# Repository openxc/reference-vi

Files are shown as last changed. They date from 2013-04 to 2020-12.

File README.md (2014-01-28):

OpenXC Vehicle Interface Reference Design
=========================================

This repository is a part of the [OpenXC][] project.

This repository contains the documentation and open source design files for the
OpenXC vehicle interface reference design, originally created by Ford.

## Documentation

The documentation is in the form of simple website, written in Markdown with the
HTML generated with [Jekyll][jekyll].

[jekyll]: http://jekyllrb.com/

### Organization

* the `*.mkd` files are the source for the documentation website - they're very
  readable as plain text files, too, if you're just digging through the
  repository.
* `static/` contains the static JavaScript, CSS and images for the site.
* `_layouts/default.html` contains the main layout for the site. There's only 1
  layout for now, although there could others in the future.
* `electrical/` contains the electrical design files and documentation.
* `mechanical/` contains the mechanical housing design files and documentation.
* `assembly/` contains documentation to support final assembly at a fabrication
  house.

### Local development

If you do not have ruby and RubyGems installed (you already do on OS X), see
below.

Assuming you have Ruby and RubyGems installed:

    $ gem install rdiscount jekyll

Then, assuming you have Python's `pip` installed:

    $ pip install pygments

Then run the local development server:

    $ cd reference-vi
    reference-vi/ $ jekyll serve -w

and point your browser to http://localhost:4000.

Jekyll uses the templates in the repository to generate a static html version of
the site. The static version is always dumped in the `_site` subdirectory in the
repository - this is *not* committed, since it's automatically generated. The
`-w` flag turns on auto-recompilation, so anytime you change a file it will
regenerate whatever files have changed, so you just need to refresh the browser
to see your latest updates.

### Installing Ruby and RubyGems

**Cygwin in Windows**

TODO is this necessary anymore?

Install the `ruby`, `make`, `gcc`, `libiconv` and `zlib` packages in
Cygwin using the `setup.exe`
you downloaded earlier. Download the RubyGems TGZ package from
http://rubygems.org/pages/download and put it in `C:\cygwin\home\<your
username>`. Fire up Cygwin and run this:

    $ tar -xzf rubygems*.tgz
    $ cd rubygems*
    $ ruby setup.rb

Jekyll depends on posix-spawn v0.3.6, but that has a problem with compiling in
Cygwin. The latest development version works, though, so install that gem from
source before continuing:

    $ git clone https://github.com/rtomayko/posix-spawn.git
    $ cd posix-spawn
    $ gem build posix-spawn.gemspec
    $ gem install posix-spawn-0.3.6.gem

If you didn't get any errors, return to the top of this section and install
jekyll.

### Going Live

The documentation site is hosted on GitHub pages, so deploying is as simple as
commiting your changes to the `gh-pages` branch and pushing to GitHub. It gets
regenerated within a minute or two, and then it's live. This of course means
don't push anything in the `gh-pages` branch that isn't 100% done!

## License

Copyright (c) 2013 Ford Motor Company

The electrical and mechanical designs in this repository are available under the
[Creative Commons Attribution 4.0
International](http://creativecommons.org/licenses/by/4.0/deed.en_US) license.

[OpenXC]: http://openxcplatform.com

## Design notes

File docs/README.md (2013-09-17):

OpenXC Vehicle Interface
========================

[TOC]

Details
-------

### Block diagram

Interface Block Diagram

The Vehicle Interface (VI) is built around an LPC1769 ARM Cortex M3 MCU by NXP,
running at 100MHz.  The interface reads vehicle data via two CAN buses.  By
default the device reads from the Diagnostic High speed and Diagnostic Medium
speed buses (Channel B can also read from the Multimedia CAN bus).  The CAN
buses are converted into serial data by a [TJA1048
IC](http://www.nxp.com/documents/data_sheet/TJA1048.pdf).  The translated data
is sent to a tablet or PC via USB and Bluetooth.  USB is achieved by the device
controller built into the LPC1769.  Bluetooth is achieved via a [Roving Networks
RN-41 Embedded bluetooth module](http://www.rovingnetworks.com/products/RN41),
using UART channel 1 on the LPC1769 with hardware flow control.

The Dock has two power regulators.  The main regulator is a low dropout linear
regulator regulator that steps the +12V automotive power down to a steady +5V.
A smaller 3.3V low dropout regulator (LDO) provides the USB Hub with a 3.3V
rail.  The power section is configured so that a USB OTG host can either provide
or consume +5V power.  If the Dock is plugged into a PC or laptop, the +5V power
can be used to power the Dock and downstream devices.  If a mobile phone or
tablet is plugged into the Dock, and is configured to charge from the USB OTG
port, it will be able to charge from the +5V power.  This is protected by a 1A
PTC resettable fuse - if a power fault occurs, the fuse will trip and power will
need to be removed for several minutes until the fuse is reset.

Several other headers and jumpers have been exposed for development purposes.  A
header has been provided to access UART0 on the LPC1769 - this can be used for
serial debug as well as ISP programming.  The standard JTAG interface has also
been exposed through a 10-pin ARM JTAG Mini connector.  Two buttons have also
been added to the board - one resets the LPC1769, and the other allows the
LPC1769 to enter a USB bootloader if available.  See
[Inputs/Outputs](#inputsoutputs) for more information.

### Parts Layout

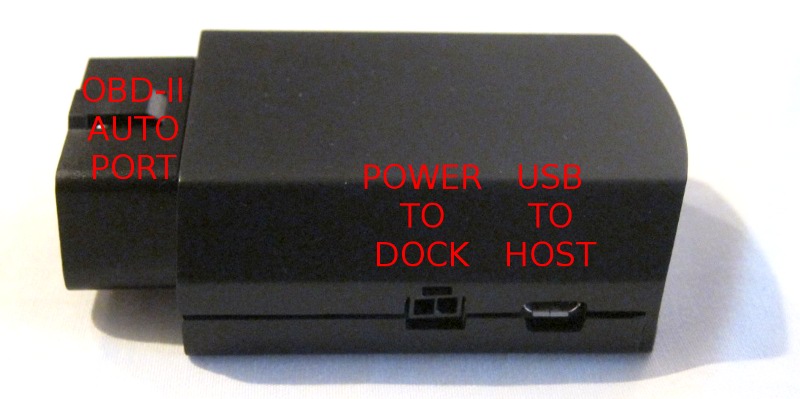
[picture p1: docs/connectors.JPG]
Interface Connections Interface board - Connections


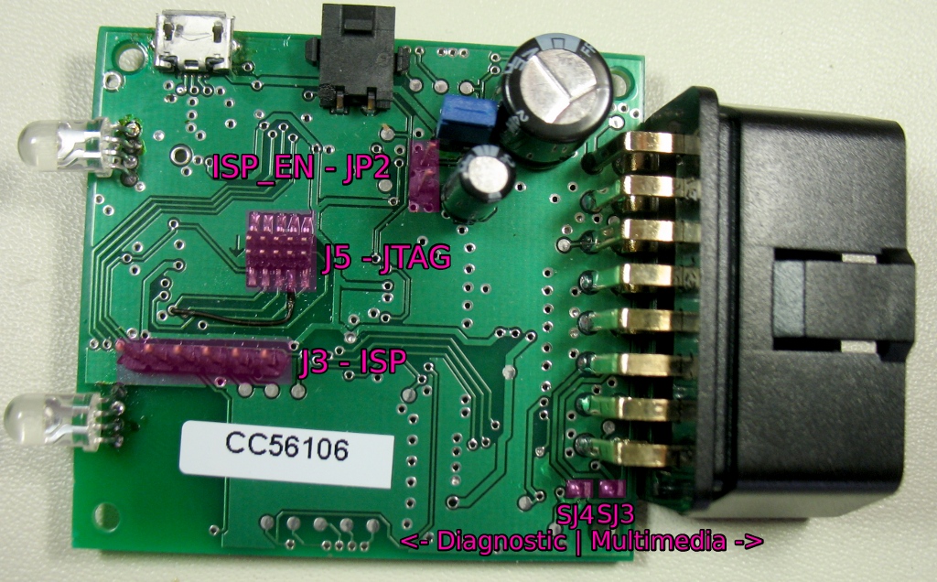
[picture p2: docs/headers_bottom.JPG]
Interface Headers Bottom Interface board - headers on bottom side


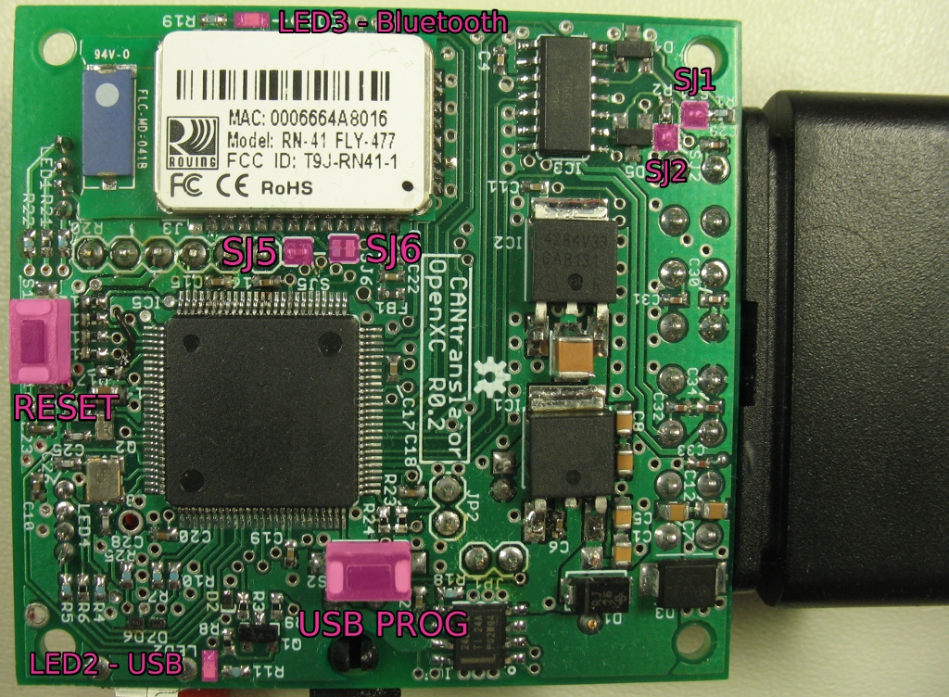
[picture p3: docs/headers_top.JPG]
Interface Headers Top Interface board - headers on top side


### Inputs/Outputs

#### Buttons

* S1 (RESET) - Pressing this button will reset the LPC1769 (it will not reset
  the RN-41 chipset)
* S2 (PROG) - This button engages a USB Bootloader. Hold down S2 while pressing
  S1 to enter the bootloader.

#### Headers and jumpers

* JP1 (HOST PWR) - Shorting this jumper will allow the board to either charge an
  upstream USB device, or be powered by it.
* JP2 (ISP_EN) - Shorting this jumper will place the LPC1769 in ISP Bootloader
  mode when it is reset. In ISP Bootloader mode, user code is not run - J3 can
  only be used to deploy firmware over serial.
* J3 (ISP) - The debug serial port (UART0) which can also be used for ISP
  programming (see JP2).
* J5 (JTAG) - This is a 50 mil pitch 10-pin ARM Mini JTAG interface. An adapter
  can be used to connect the standard 100 mil 20-pin JTAG connector.

#### Solder Jumpers

* SJ1, SJ2 - These are used to engage the 120 ohm termination resistor for CAN
  interfaces A and B respectively. If being used in a test bench without a full
  CAN network, you probably want these enabled. It may be simpler and more
  reversible to add the resistors to the OBD-II cable, instead.
* SJ3, SJ4 - These switch the CAN B channel between the Diagnostic Medium Speed
  and Multimedia CAN buses exposed by the OBD-II connector on Ford vehicles.
  They are each shorted towards the PCB edge, enabling the Diagnostic interface
  by default.
* SJ5  - This connects the DTR line of the ISP header (J3) to the LPC1769 RESET
  line. This can be used by an ISP programmer to automatically reset the LPC1769
  for programming.  In practice, this can accidentally hold the LPC1769 in
  reset, so this jumper should be OPENED if J3 is used.
* SJ6  - This disconnects the RN-41 reset pin from the BT_RST GPIO pin on the
  LPC1769. This is normally closed, and should only be opened if the RN-41 needs
  to be put into reset without the LPC1769.

### GPIO Pin List

A list of GPIO pins used on the LPC1769

#### Port 0

* P0.2 - ISP/Debug UART: TX
* P0.3 - ISP/Debug UART: RX
* P0.4 - CAN Channel B: RX
* P0.5 - CAN Channel B: TX
* P0.6 - CAN Channel B: Enable (HIGH = Normal Mode, LOW = Standby Mode)
* P0.15 - Bluetooth UART: RX
* P0.16 - Bluetooth UART: TX
* P0.17 - Bluetooth Enable: (HIGH = RN-41 is enabled, LOW = RN-41 is in RESET)
* P0.18 - Bluetooth Connection: INPUT - Will go high when bluetooth host is
  connected
* P0.19 - CAN Channel A: Enable (HIGH = Normal Mode, LOW = Standby Mode)
* P0.21 - CAN Channel A: RX
* P0.22 - CAN Channel A: TX
* P0.29 - USB D+
* P0.30 - USB D-

#### Port 1

* P1.18 - LED4 (Right LED) Green Channel
* P1.20 - LED4 (Right LED) Blue Channel
* P1.21 - LED4 (Right LED) Red Channel
* P1.23 - LED1 (Left LED) Green Channel
* P1.24 - LED1 (Left LED) Blue Channel
* P1.26 - LED1 (Left LED) Red Channel
* P1.30 - USB VBUS: Connected to USB +5V pin

#### Port 2

* P2.2 - Bluetooth UART: RTS (LOW when RN-41 is ready for data, HIGH when RN-41
  serial buffer is full)
* P2.7 - Bluetooth UART: CTS (LOW when LPC1769 is ready for data, HIGH when
  LPC1769 serial buffer is full)
* P2.9 - USB CONNECT: Enables USB Pullup (LOW when USB unused, HIGH to signal
  USB interface is ready)
* P2.10 - ISP ENABLE: When HIGH, User code runs on next RESET. When LOW, ISP
  Serial bootloader runs on next RESET.
* P2.12 - USB Bootloader ENABLE: When HIGH, User code runs on next RESET. When
  LOW, USB bootloader runs on next RESET
* P2.13 - Power output enable (Active Low): Output power port enabled when LOW

Usage:
------

### How to program

The most reliable way to program the VI is via the JTAG
interface, however other options are available:

#### JTAG

To program using JTAG, any ARM Cortex M3 compatible JTAG adapter can be used.
The interface has been tested using an
[ARM-USB-TINY-H](https://www.olimex.com/Products/ARM/JTAG/ARM-USB-TINY-H/) and
an [ARM-USB-OCD-H](https://www.olimex.com/Products/ARM/JTAG/ARM-USB-OCD-H/) by
Olimex.  The interface board does not have a full-size 20-pin JTAG connector -
[an adapter will be required with most JTAG
programmers](https://www.olimex.com/Products/ARM/JTAG/ARM-JTAG-20-10/).  Simply
plug the ARM-JTAG-MINI connector into J5 on the bottom side of the vehicle
interface PCB.  Make sure that the ribbon cable exits the connector in the
direction of the arrow on the PCB.

With the JTAG adapter connected, and power applied to the board, the LPC1769
should respond to commands from [OpenOCD](http://openocd.sourceforge.net/).  If
deploying code from an OpenXC repository, the board can be programmed by simply
executing "make flash" from the root of the source tree.  See other LPC17XX JTAG
tutorials for more information, the process is nearly identical across all
LPC17XX devices.

#### ISP

If a [3.3V USB-Serial converter is
available](https://www.sparkfun.com/products/9873), the device can be programmed
using the ISP header, J3.  To use ISP simply short JP2 and reset the LPC1769.
If the ISP_EN pin is grounded when the LPC1769 boots, it will enter the built-in
ISP bootloader instead of running the OpenXC firmware.  UART0 will then be used
for programming under an application like [Flash
Magic](http://www.flashmagictool.com/).  Page 616 of the LPC17XX user manual
outlines how to use ISP mode.

#### USB Bootloader

The LPC1769 has the capability to load code from the USB interface, however this
is not built into the MCU.  In order to program over USB, a USB bootloader must
already have been programmed onto the LPC1769.  The USB Bootloader should watch
pin P2.12 (the same pin as the LPC1768 BlueBoard) on startup.  If installed
correctly, the bootloader can be actived by holding down S2 while resetting the
VI.

#### RN-41 Configuration

After being manufactured, the only additional configuration step (outside of
deploying firmware) is to change a few default values on the RN-41 device.  The
default RN-41 baud rate is 115200 baud, which is not high enough to saturate the
bluetooth link.  The quickest way to preform this first initial configuration is
to use a PC or tablet with a bluetooth interface:

1. Apply power to the VI.
1. Discover Bluetooth devices on the PC, find the VI, and pair
      with it.
1. Remove power from the VI.
1. After a few moments, reapply power to the VI
1. Very quickly (within 60 seconds) connect to the VI and open a
    terminal
1. type "$$$" and press enter.  If done quickly, the bluetooth LED should
      start flashing rapidly and "CMD" should be printed to the screen.
1. type "ST,10" to reduce the configuration timer to 10 seconds.  It can also
      be disabled by executing "ST,0".
1. type "SU,43" to set the baud rate to 460800.  This value is used by the test
    firmware.
1. type "---" to exit configuration mode
1. Remove power from the VI.  When power is reapplied, the
   settings will be changed.

The commands can also be sent via UART0 on the LPC1769 to avoid the
configuration timer.  See [the RN-41 advanced user
manual](http://www.rovingnetworks.com/resources/download/47/Advanced_User_Manual)
for additional documentation on parameters that can be changed (Page 30 for a
quick reference)

### Known issues:

For greater detail, see CHANGELOG.xls

#### v0.3:

* The very first run of prototypes are lacking epoxy on the USB Micro connector
  and the connector may break under stress.  This will be fixed in subsequent
  manufacturing runs.

#### v0.2:

* Output Power Jack Polarity is incorrect - The output power jack should be
  configured such that Pin 1 (the keyed pin) is Ground, and Pin 2 is +12V. This
  is flipped on the R0.2 PCB. A custom cable was created to patch this issue,
  and is labeled `R0.2 Only`. Only use this cable with R0.2 prototypes,
  otherwise the KBoard TVS Diode D2 and/or the VI power switch IC7
  may be damaged or destroyed.
* JTAG CLK line - the JTAG signal RTCK was disconnected on R0.2 boards. It has
  manually been replaced with a wire. Occasionally the additional capacitance of
  this wire can cause JTAG errors - try reducing the JTAG clock rate.
* JTAG Ground noise - Occasionally JTAG errors can be caused by a ground loop
  between a USB JTAG adapter and the MicroUSB port on the VI. Try
  removing one or more connections to ground: IE, try powering the prototype
  from ONLY +5V USB verses the +12V OBD-II supply.
* Bluetooth connection dropout - Under some circumstances, the RN-41 bluetooth
  chipset will lock up and drop an active bluetooth connetion when under heavy
  load:
    * The most common cause of this problem is software flow control: make sure
      to use the RTS and CTS pins for UART1.
    * The RN-41 configuration timer can also cause the RN-41 input buffer to
      fill. From the LPC1769, enter configuration mode by transmitting
      ```$$$```, disable the configuration timer with ```ST,0\r\n``` and then
      exit configuration mode by entering ```---\r\n```. Finally, power cycle
      the VI. The test firmware `rn42-passthrough` enables serial
      data to be relayed between UART0 (the 6-pin ISP header) and UART1 (the
      bluetooth interface).

Design Details and Consideration
--------------------------------

### MCU Selection

The VI was originally built around a ChipKit MAX32 development
board, which used a PIC32MX795F512 processor.  We chose to move away from this
architecture due to frustrations around the open-source support and tools of the
PIC32 line.  We had trouble developing for this platform in Linux, and had to
resort to closed-source windows tools in order to use the device effectively.
Most other MCUs in the same performance category as the PIC32 device lie in the
[ARM-Cortex-M family](http://en.wikipedia.org/wiki/ARM_Cortex-M), particularly
the ARM Cortex-M3 core.  Several major MCU manufacturers make Cortex-M3 devices
(Atmel, NXP, STMicro, TI),  The NXP LPC17XX line was selected due to it's
excellent open-source compiler support, library support, and ease of
programming.  Many off-the-shelf open-source hardware designs exist for the
LPC1768, and this encourages a large amount of community support and a wider
variety of user-contributed libraries.

The MCU system design was based around the [Blueboard
LPC1768-H](http://shop.ngxtechnologies.com/product_info.php?products_id=65).
This was done to allow firmware to be prototyped on an off-the-shelf open-source
hardware.  The hardware configuration is also compatible with the [MBED rapid
prototyping board/environment](http://mbed.org/).  The Clock, Power and USB
subsystems are all equivalent.  The JTAG interface was converted to the 10-pin
ARM JTAG Mini format to reduce the PCB footprint of the normal large 20-pin JTAG
connector.  This results in a 12MHz external crystal oscillator stepped up to a
100MHz system clock.

### LPC1769 Data

* [LPC1769FB100 Product Page](http://www.nxp.com/products/microcontrollers/cortex_m3/LPC1769FBD100.html)
* [LPC176X Datasheet](http://www.nxp.com/documents/data_sheet/LPC1769_68_67_66_65_64_63.pdf)
* [LPC17XX User Manual](http://www.nxp.com/documents/user_manual/UM10360.pdf)
* [Blueboard LPC1768-H Product Page](http://shop.ngxtechnologies.com/product_info.php?products_id=65)
* [Blueboard LPC1768-H Schematics V2](http://shop.ngxtechnologies.com/download/Schematics/BlueBoard/BB_LPC1768_H/Blueboard_lpc1768_H_V2.pdf)
* [mbed LPC1768 schematics](http://mbed.org/media/uploads/chris/mbed-005.1.pdf)

### Power Section

The VI uses two heavy-duty low dropout linear regulators to
convert the unpredictable +12V automotive power source to the +5V and +3.3V
rails needed by the MCU and related ICs.  Incoming power is protected from
overvoltage by D3, a [SMBJ16CA](http://www.fairchildsemi.com/ds/SM/SMBJ16CA.pdf)
Transient Voltage Suppressor (TVS) diode.  D3 will protect the interface from
any voltage over 19.7V (Vbr).  The power regulators can handle up to 40V, but
the Dock power switch (IC7) can only tolerate up to 20V.  Reverse voltage is
protected by D1.  Both regulators do not require any additional current or
temperature protection - they can safely drive into a short circuit at
temperatures up to 150 degrees C, and will limit current if they become too hot.
Plenty of bulk and bypass capacitance has been provided to absorb automotive
power transients.

The regulators are cascaded such that the +5V rail supplies the +3.3V rail.  The
TLE4284DV33 has a maximum voltage drop of 1.4V, so it can be safely powered by
any source above 4.7V.  While this puts additional load on the +5V rail, it also
allows the interface to be powered either by the OBD-II connector or the
MicroUSB port.  Both regulators can deliver current up to 1.6A.  Current budget:

* 5V regulator capacity: 1600mA
* USB Charging Limit (fuse): 1000mA
* RN-41 average TX rate: 60mA
* LPC1769 Base consumption @ 100MHz: 50mA
* LPC1769 peripherals (2xCAN+2xUART): 3mA
* Both RGB LEDs on at full: 60mA
* TJA1048T both channels dominant: 140mA
* Total: 1313mA

This yields a headroom of ~300mA when all peripherals are active and a Tablet is
charging at 1A.

### Power Input/Output

The VI has the following power connections:

* OBD-II Automotive Power: Input @ 12V
* Dock Power Connector: Output @ 5V up to 6A
* USB Micro Connector: Input OR Output @5V up to 1A

The Dock power connector is controlled by a [TPS2421-2 power switch with
internal MOSFET](http://www.ti.com/lit/ds/symlink/tps2421-2.pdf).  This allows
the Dock power to be disabled when the vehicle is turned off, as well as
providing current protection.  The power switch has an active 6A limit, and will
actively attempt to re-engage power when the limit is tripped ("retry on
fault").

The USB Micro Connector is directly connected to the +5V bus through a Fuse.
The lack of a diode means that the connected USB device can either consume or
supply current.  If a PC is connected to the USB Micro connector, it will power
the 3.3V regulator and the +5V regulator will be bypassed.  If an android tablet
is connected that supports USB OTG Charging, it will be allowed to consume +5V
power.  A resettable fuse (F1) has been added to protect the VI
from a bad USB cable or USB Host.  The fuse is a [Bourns
MF-MSMF110/16-2](http://www.bourns.com/pdfs/mfmsmf.pdf).  The fuse will
automatically reset when power is removed and the fuse is allowed to cool off.
This has an added downside of temperature dependence - the fuse can only pass
the full 1A of current up to 40 degrees C.  Above that temperature the limit
slowly decreases - see the datasheet for a thermal derating chart.

### CAN Interface

The CAN interface is acheived using an [NXP
TJA1048](http://www.nxp.com/documents/data_sheet/TJA1048.pdf), a dual-channel
CAN transceiver.  This is a part recommended by Ford engineers for it's
reliablity and robustness.  The only hard requirement of this transceiver is
that it have a Standby mode, and some way to wake up the microcontroller when
the CAN bus comes out of standby.  Aside from the CAN signals, the TJA1048 also
has one standby input per channel - pulling each line low will put it's
respective CAN channel into standby mode.  These are routed to P0.19 for CAN
Channel 1, and P0.6 for CAN Channel 2.

On the automotive side of the CAN transceivers, some support electronics are
required.  D4 and D5 provide additional ESD protection against voltage spikes on
the CAN line - each
[PESD1CAN](http://www.nxp.com/documents/data_sheet/PESD1CAN.pdf) can provide up
to 200W of peak dissipation and ESD protection up to 23kV.  R1 and R2 provide
termination resistance for the CAN Bus.  If the VI is acting as a
CAN Slave, and is reading CAN signals from a vehicle, these resistors need to be
connected across the HI and LO wires of each CAN bus.  SJ1 and SJ2 are closed by
default, enabling this termination.  If this termination is not needed, the
solder jumpers can be cut.  Finally, each CAN signal as a 100pF bypass capacitor
very close to the OBD connector, to shunt high frequency noise to ground.

The CAN bus doesn't particularly require a high speed PCB design, since the rate
is only 1Mbps at most.  However an attempt was made to maintain the
characteristic 120 ohm differential impedance on the CAN lines.  An attempt was
also made to maintain a 45 mil guard band around each CAN bus, to keep high
frequency switching transients from coupling onto the CAN bus.  The guard band
was also applied to the LPC1769 side of the CAN transciever, to keep the same
transients out of the converted CAN signals.  Since the layout is only 2 layers
and very crowded, this wasn't implemented perfectly, but seems to be within 85%
coverage.  The combination of these considerations means that the CAN interface
should be highly resilient to noise and should limit signal distortion due to
reflections and other transmission line phenomenon.

### Bluetooth Interface

The [Roving Networks RN-41](http://www.rovingnetworks.com/products/RN41) was
chosen to implement the Bluetooth interface for the VI:

* a low-cost and easy-to-use option
* easily prototyped
* automatically implents the Serial Port Profile (SPP) configuration
* no need to implement a Host/Controller Interface (HCI), keeps MCU code simple

The only major design impact of the RN-41 is that it requires a large "keepout"
area near the antenna of the module.  In this area, there should be a minimal
amount of traces or copper blocking the radio signal.  The [RN-41
Datasheet](http://www.rovingnetworks.com/resources/download/18/RN_41)
illustrates the suggested keepout zone on page 9.  Otherwise, the RN-41 is
controlled with a serial UART bus with similar bitrates to the CAN data (230kbps
- 1Mbps).  In our testing we discovered that hardware flow control is necessary
to fully saturate the bluetooth link.  The firmware on the RN-41 does not
respond well to buffer overruns - if data is written to the RN-41 faster than it
can be sent over the bluetooth link, the module will eventually overflow and
reset without warning.  Adding the RTS and CTS lines to UART1 on the LPC1769
fixed this problem - the RN-41 will inform the MCU host when it's buffer is
full.

The tradeoff of a simplified Bluetooth module is that the implementation details
of the SPP profile limit the throughput of the bluetooth link.  While the
underlying Enhanced Data Rate (EDR) bluetooth link can technically operate at
3Mbps, the asynchronous nature of SPP limits the RN-41 to 240kbps in slave mode.
In our testing, the RN-41 only hit this speed for brief peak bursts.  The
sustained average speed was 202kbps.  Future designs may consider using a more
complicated bluetooth chipset with an HCI interface implemented on the MCU for
greater throughput.  An example of a test run:

<img src="./Testing%20Results/BT_Endurance_Histogram_012613.svg" alt="RN-41 Test Throughput" width="1024">
<!--![RN-41 Test Throughput](./Testing%20Results/BT_Endurance_Histogram_012613.svg "RN-41 Test Throughput")-->

* Average rate: 25.282 KB/s
* Maximum speed: 30.185 KB/s
* Minimum speed: 14.718 KB/s

### USB Interface

USB is provided directly by the LPC1769 - no external transceiver or controller
is necessary.  A few external components are required to correctly enable the
LPC1769 as a USB Device and can be found on [Page 276 of the LPC1769
manual](http://www.rovingnetworks.com/resources/download/47/Advanced_User_Manual).
The USB_CONNECT line and associated circuitry was mirrored from the LPC1768-H
Blueboard design so that USB bootloader firmware would be interoperable, and a
few modifications were made for additional resilience and device compatibility:

Diodes D2, D6 and D7 were added to ESD protect the USB lines.  D2 is an [NXP
PESD12VS1ULD](http://www.nxp.com/documents/data_sheet/PESD12VS1ULD.pdf)
unidirectional ESD protection diode.  D6 and D7 are [NXP
PESD5V0X1BL](http://www.nxp.com/documents/data_sheet/PESD5V0X1BL.pdf)
bidirectional ESD diodes.  All protection diodes are specifically designed for
the USB bus and have very low capacitance to avoid disrupting USB signals.

Resistor R25 attempts to indicate to an attached USB OTG device that the CAN
Translator can provide charging current.  A specification exists on [Page 48 of
the USB Battery Charging Specification
R1.2](http://kinetis.pl/sites/default/files/BC1.2_FINAL.pdf) describing an
Accessory Charger Adapter.  This specification defines special resistance values
on pin 4 of a USB OTG connector that should flag that the connected device is a
charging device.  However in practice very few devices actually honor this
specification.  It's totally up to the implementation of the portable tablet or
smartphone whether or not they support charging while using the USB port as a
USB Host.

If a Male-Male USB Micro cable is used with the VI, this
identification resistor will be readable by a connected USB OTG device.  If the
device is USB ACA compliant, it will successfully charge.  If a Male-Male cable
is unavailable, or if the device doesn't honor the USB ACA specification, a
normal USB A to USB Micro cable can be used with a commonly-available USB OTG
Host mode adapter.  For example:

* A Samsung Galaxy Note II with stock android firmware will honor the USB ACA
  profile [(from this forum post)](http://www.head-fi.org/t/595071/android-phones-and-usb-dacs/405#post_8748466)
* A Motorola Droid Razr with stock firmware and a normal USB OTG Host cable will
  charge (tested)
* A Google Nexus 7 tablet will not charge from the USB OTG port when host mode
  is enabled without a custom firmware (tested)

USB signals require high speed PCB routing to avoid signal integrity issues,
since the bitrates are high (11Mbps - 480Mbps).  Unfortunately with a 2 layer
PCB, the trace widths required to obtain the ideal 90 ohm differential impedance
for a USB line would be unfeasibly wide.  To compensate for this fact, the USB
connector was located extremely close (~300 mils) to the LPC1769 USB pins.  A
guard band was used around the USB lines and tightly coupled to the ground
plane.  The ground plane underneath the USB signals was kept clear so the ground
loop would be kept small and transient ground currents would avoid coupling into
the USB signal.

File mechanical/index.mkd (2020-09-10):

---
layout: default
title: Mechanical Design
---

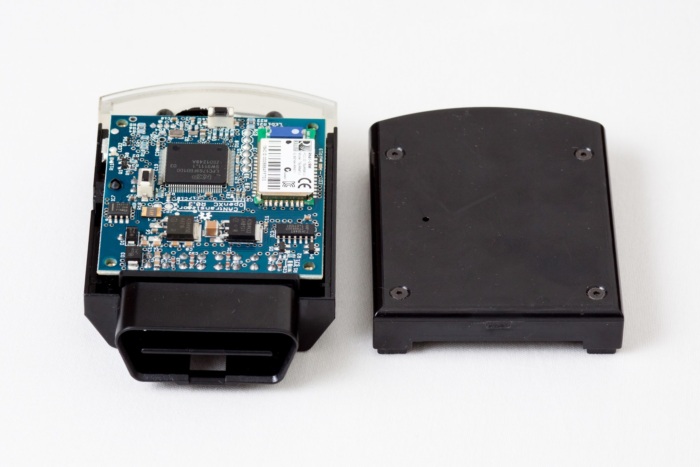
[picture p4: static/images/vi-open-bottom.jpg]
Assembly opened


The VI housing design consists of an opaque top and bottom, with a translucent
diffuser piece at the end opposite the OBD-II connector, between two halves of
the housing. The diffuser does a decent job of spreading the light from the 2
RGB LEDs, although a light pipe may provide more consistent saturation.

We've manufacturing this design succesfully with a MakerBot Replicator 2,
SLA, and most recently, injection molded by contract manufacturers from Silicon Valley, the
materials used were:

* VI Top and Bottom: Bayblend T85 XF-901510
* VI Difffuser: Lexan 3412R-131 (Natural 20% Glass Fiber PC)

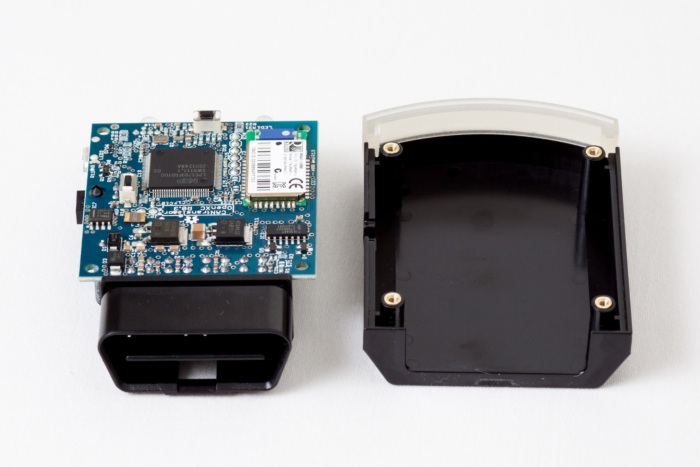
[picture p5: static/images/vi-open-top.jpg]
Assembly opened and separated


## Sources

The original master source files for the 3D design were created in CATIA, which
unfortunately is neither open source nor affordable. We've output the design for
the top of the enclosure, the bottom and the diffuser as STL (triangle) and STP
(solid) files.

The files are all [stored in a Git repository at
GitHub](https://github.com/openxc/reference-vi/tree/gh-pages/mechanical) -
pull requests are welcome!

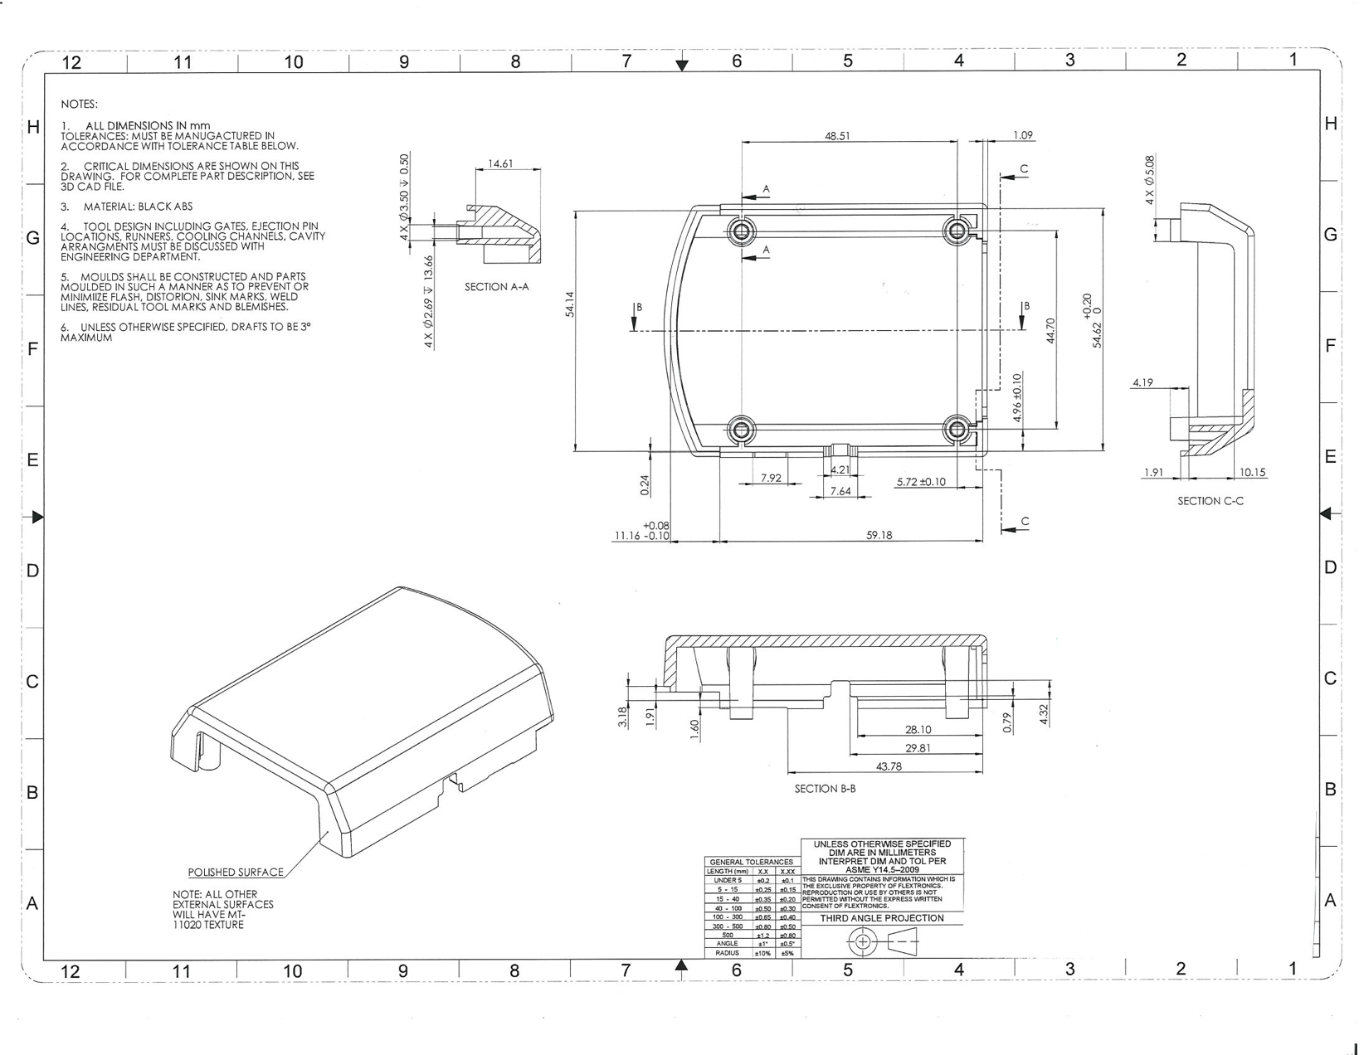
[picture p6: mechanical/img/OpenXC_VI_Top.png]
Top

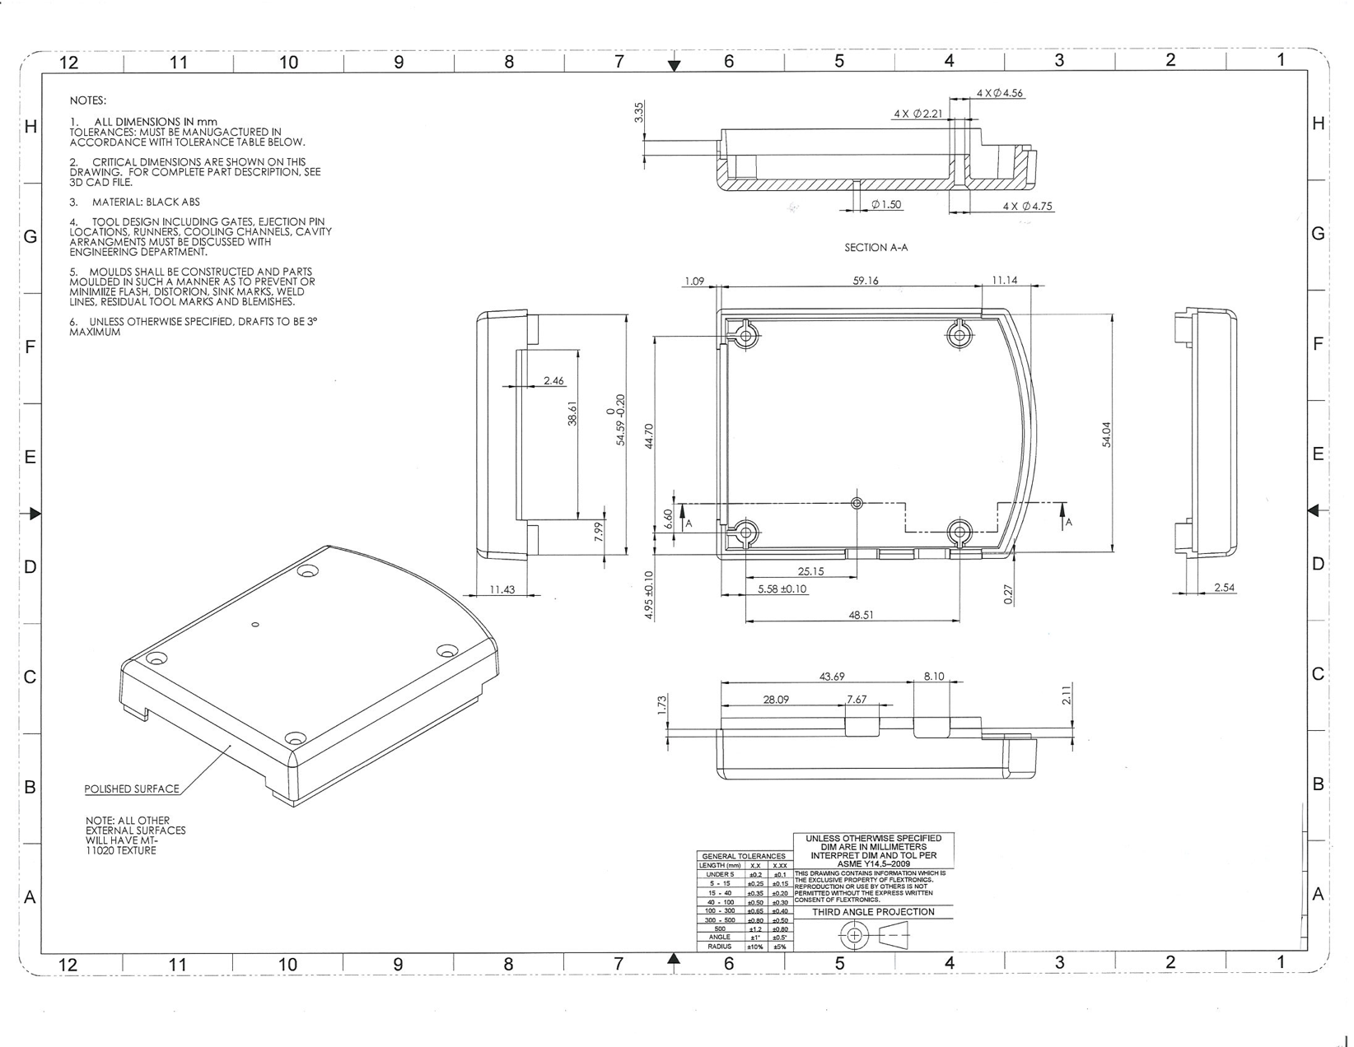
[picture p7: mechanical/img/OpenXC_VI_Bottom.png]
Bottom

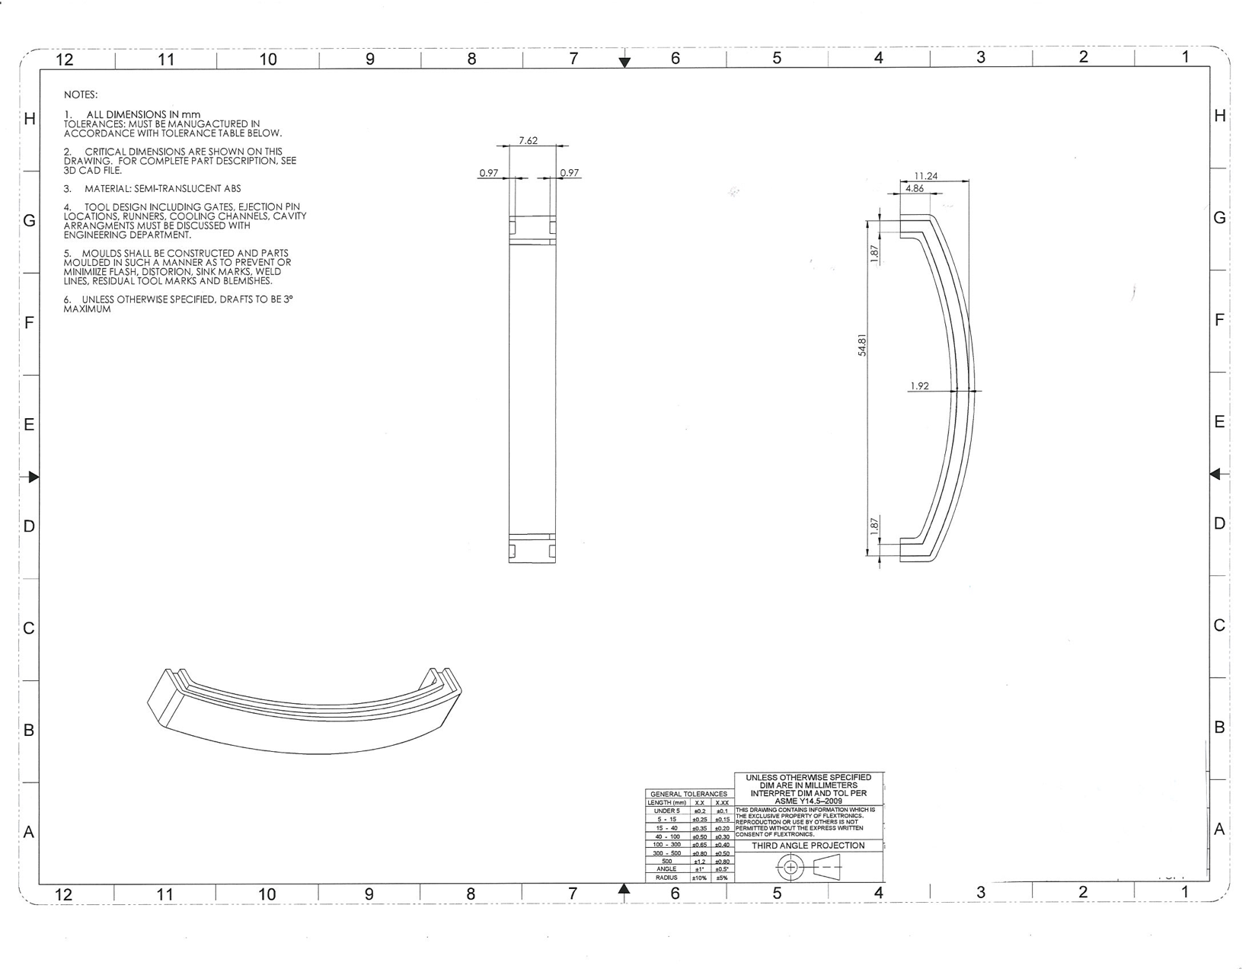
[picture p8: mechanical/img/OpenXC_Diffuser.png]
Diffuser


* VI Enclosure Bottom
  * [2D Drawing(PDF)](/mechanical/OpenXC_VI_Bottom.PDF)
  * [STEP](/mechanical/VI_bottom.step)
* VI Enclosure Top
  * [2D Drawing(PDF)](/mechanical/OpenXC_VI_Top.PDF)
  * [STEP](/mechanical/VI_top.step)
* Diffuser
  * [2D Drawing(PDF)](/mechanical/OpenXC_Diffuser.PDF)
  * [STEP](/mechanical/VI_diffuser.step)

## Design for Manufacturing

* Added 1.5 degree draft angles for top and bottom enclosures. 1.5 degree was chosen based on the selected surface texturing MT-11020. The only exception is the vertical wall where the OBD-II connector sits, which only has 0.5 degree of draft and does not have texturing.
*

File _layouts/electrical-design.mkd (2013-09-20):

---
layout: electrical
---

<ul class="nav nav-tabs subnav">
  <li><a href="/electrical/index.html">Overview</a></li>
  <li><a href="/electrical/design/power.html">Power</a></li>
  <li><a href="/electrical/design/microcontroller.html">Microcontroller</a></li>
  <li><a href="/electrical/design/can.html">CAN</a></li>
  <li><a href="/electrical/design/bluetooth.html">Bluetooth</a></li>
  <li><a href="/electrical/design/usb.html">USB</a></li>
</ul>

{{ content }}

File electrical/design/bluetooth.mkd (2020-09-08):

---
layout: electrical-design
title: Bluetooth Interface
---

The [Roving Networks RN-41](http://www.rovingnetworks.com/products/RN41) was
chosen to implement the Bluetooth interface for the VI because:

* it supports the Serial Port Profile (SPP) configuration
* it doesn't require implementing a Host/Controller Interface (HCI), keeping the
  MCU code simple
  - the stack is on the RN-41

The only major design impact of the RN-41 is that it requires a large "keepout"
area near the antenna of the module. In this area, there should be a minimal
amount of traces or copper blocking the radio signal. The [RN-41
Datasheet](https://cdn.sparkfun.com/datasheets/Wireless/Bluetooth/Bluetooth-RN-41-DS.pdf)
illustrates the suggested keepout zone on page 9. Otherwise, the RN-41 is
controlled with a serial UART bus with similar bitrates to the CAN data (230kbps
- 1Mbps).

In our testing we discovered that hardware flow control is necessary to fully
saturate the bluetooth link. The firmware on the RN-41 [does not respond
well](http://christopherpeplin.com/2013/07/26/uart-hardware-flow-control/) to
buffer overruns - if data is written to the RN-41 faster than it can be sent
over the bluetooth link, the module will eventually overflow and reset without
warning. Adding the RTS and CTS lines to UART1 on the LPC1769 fixed this problem
- the RN-41 will inform the MCU host when it's buffer is full.

The tradeoff of a simplified Bluetooth module is that the implementation details
of the SPP profile limit the throughput of the bluetooth link. While the
underlying Enhanced Data Rate (EDR) bluetooth link can technically operate at
3Mbps, the asynchronous nature of SPP limits the RN-41 to 240kbps in slave mode.
In our testing, the RN-41 only hit this speed for brief peak bursts. The
sustained average speed was 202kbps. Future designs may consider using a more
complicated Bluetooth chipset with an HCI interface implemented on the MCU for
greater throughput. An example of a test run:

Bluetooth Testing Results

* Average rate: 25.282 KB/s
* Maximum speed: 30.185 KB/s
* Minimum speed: 14.718 KB/s

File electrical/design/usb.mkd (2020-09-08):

---
layout: electrical-design
title: USB Interface
---

USB is provided directly by the LPC1769 - no external transceiver or controller
is necessary. A few external components are required to correctly enable the
LPC1769 as a USB Device and can be found on [the LPC1769
manual](https://www.nxp.com/docs/en/user-guide/UM10360.pdf).
The USB_CONNECT line and associated circuitry was mirrored from the LPC1768-H
Blueboard design so that USB bootloader firmware would be interoperable, and a
few modifications were made for additional resilience and device compatibility:

Diodes D2, D6 and D7 were added to ESD protect the USB lines. D2 is an [NXP
PESD12VS1ULD](https://assets.nexperia.com/documents/data-sheet/PESD12VS1ULD.pdf)
unidirectional ESD protection diode. D6 and D7 are [NXP
PESD5V0X1BL](https://assets.nexperia.com/documents/data-sheet/PESD5V0X1BL.pdf)
bidirectional ESD diodes. All protection diodes are specifically designed for
the USB bus and have very low capacitance to avoid disrupting USB signals.

Resistor R25 attempts to indicate to an attached USB OTG device that the CAN
Translator can provide charging current. A specification exists on [
the USB Battery Charging Specification
R1.2](https://www.usb.org/sites/default/files/USB_Battery_Charging_1.2.pdf) describing an
Accessory Charger Adapter. This specification defines special resistance values
on pin 4 of a USB OTG connector that should flag that the connected device is a
charging device. However in practice very few devices actually honor this
specification. It's totally up to the implementation of the portable tablet or
smartphone whether or not they support charging while using the USB port as a
USB Host.

If a Male-Male USB Micro cable is used with the VI, this
identification resistor will be readable by a connected USB OTG device. If the
device is USB ACA compliant, it will successfully charge. If a Male-Male cable
is unavailable, or if the device doesn't honor the USB ACA specification, a
normal USB A to USB Micro cable can be used with a commonly-available USB OTG
Host mode adapter. For example:

* A Samsung Galaxy Note II with stock android firmware will honor the USB ACA
  profile [(from this forum post)](http://www.head-fi.org/t/595071/android-phones-and-usb-dacs/405#post_8748466)
* A Motorola Droid Razr with stock firmware and a normal USB OTG Host cable will
  charge (tested)
* A Google Nexus 7 tablet will not charge from the USB OTG port when host mode
  is enabled without a custom firmware (tested)

USB signals require high speed PCB routing to avoid signal integrity issues,
since the bitrates are high (11Mbps - 480Mbps). Unfortunately with a 2 layer
PCB, the trace widths required to obtain the ideal 90 ohm differential impedance
for a USB line would be unfeasibly wide. To compensate for this fact, the USB
connector was located extremely close (~300 mils) to the LPC1769 USB pins. A
guard band was used around the USB lines and tightly coupled to the ground
plane. The ground plane underneath the USB signals was kept clear so the ground
loop would be kept small and transient ground currents would avoid coupling into
the USB signal.

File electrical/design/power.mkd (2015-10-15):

---
layout: electrical-design
title: Power Supply
---

The VI uses two heavy-duty low dropout linear regulators to
convert the unpredictable +12V automotive power source to the +5V and +3.3V
rails needed by the MCU and related ICs.  Incoming power is protected from
overvoltage by D3, a [SMBJ16CA](http://www.fairchildsemi.com/ds/SM/SMBJ16CA.pdf)
Transient Voltage Suppressor (TVS) diode.  D3 will protect the interface from
any voltage over 19.7V (Vbr).  The power regulators can handle up to
40V.  Reverse voltage is
protected by D1.  Both regulators do not require any additional current or
temperature protection - they can safely drive into a short circuit at
temperatures up to 150 degrees C, and will limit current if they become too hot.
Plenty of bulk and bypass capacitance has been provided to absorb automotive
power transients.

The regulators are cascaded such that the +5V rail supplies the +3.3V rail.  The
TLE4284DV33 has a maximum voltage drop of 1.4V, so it can be safely powered by
any source above 4.7V.  While this puts additional load on the +5V rail, it also
allows the interface to be powered either by the OBD-II connector or the
MicroUSB port.  Both regulators can deliver current up to 1.6A.  Current budget:

* 5V regulator capacity: 1600mA
* USB Charging Limit (fuse): 1000mA
* RN-41 average TX rate: 60mA
* LPC1769 Base consumption @ 100MHz: 50mA
* LPC1769 peripherals (2xCAN+2xUART): 3mA
* Both RGB LEDs on at full: 60mA
* TJA1048T both channels dominant: 140mA
* Total: 1313mA

This yields a headroom of ~300mA when all peripherals are active and a Tablet is
charging at 1A.

### Power Input/Output

The VI has the following power connections:

* OBD-II Automotive Power: Input @ 12V
* External Accessory Power Connector: Output @ 12V up to 5A
* USB Micro Connector: Input OR Output @ 5V up to 1A

The external accessory power connector is controlled by a [TPS2421-2
power switch with
internal MOSFET](http://www.ti.com/lit/ds/symlink/tps2421-2.pdf).  This allows
the external accessory power to be disabled when the vehicle is turned
off, as well as
providing current protection.  The power switch has an active 5A limit, and will
actively attempt to re-engage power when the limit is tripped ("retry on
fault").

The USB micro connector is directly connected to the +5V bus through a fuse.
The lack of a diode means that the connected USB device can either consume or
supply current.  If a PC is connected to the USB micro connector, it will power
the 3.3V regulator and the +5V regulator will be bypassed.  If an Android tablet
is connected that supports USB OTG charging, it will be allowed to consume +5V
power.  A resettable fuse (F1) has been added to protect the VI
from a bad USB cable or USB host.  The fuse is a [Bourns
MF-MSMF110/16-2](http://www.bourns.com/pdfs/mfmsmf.pdf).  The fuse will
automatically reset when power is removed and the fuse is allowed to cool off.
This has an added downside of temperature dependence - the fuse can only pass
the full 1A of current up to 40 degrees C.  Above that temperature the limit
slowly decreases - see the datasheet for a thermal derating chart.

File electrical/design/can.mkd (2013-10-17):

---
layout: electrical-design
title: CAN Interface
---

The CAN interface is acheived using an [NXP
TJA1048](http://www.nxp.com/documents/data_sheet/TJA1048.pdf), a dual-channel
CAN transceiver. This is a part recommended by Ford engineers for it's
reliablity and robustness. The only hard requirement of this transceiver is
that it have a standby mode, and some way to wake up the microcontroller when
the CAN bus comes out of standby. Aside from the CAN signals, the TJA1048 also
has one standby input per channel - pulling each line low will put it's
respective CAN channel into standby mode. These are routed to P0.19 for CAN
Channel 1, and P0.6 for CAN Channel 2.

Some support electronics are required on the vehicle side of the CAN
transceiver. D4 and D5 provide additional ESD protection against voltage spikes
on the CAN line - each
[PESD1CAN](http://www.nxp.com/documents/data_sheet/PESD1CAN.pdf) can provide up
to 200W of peak dissipation and ESD protection up to 23kV. R1 and R2 provide
termination resistance for the CAN Bus. If the VI is acting as a termiantion
point for a bench testing CAN rig, these resistors may need to be connected
across the HI and LO wires of each CAN bus. SJ1 and SJ2 are closed by default,
enabling this termination. If this termination is not needed, the solder jumpers
can be cut (see [this issue](https://github.com/openxc/reference-vi/issues/9)).
Finally, each CAN signal has a 100pF bypass capacitor very close to the OBD
connector, to shunt high frequency noise to ground.

The CAN bus doesn't particularly require a high speed PCB design, since the rate
is only 1Mbps at most and 500Kbps in practice. However, an attempt was made to
maintain the characteristic 120 ohm differential impedance on the CAN lines
(Note: this is a mistake in the design, as the termiation resistance should be
left to the vehicle's bus in normal operation - see [issue #21](https://github.com/openxc/reference-vi/issues/21)). An
attempt was also made to maintain a 45 mil guard band around each CAN bus, to
keep high frequency switching transients from coupling onto the CAN bus. The
guard band was also applied to the LPC1769 side of the CAN transciever, to keep
the same transients out of the converted CAN signals. Since the layout is only 2
layers and very crowded, this wasn't implemented perfectly, but seems to be
within 85% coverage. The combination of these considerations means that the CAN
interface should be highly resilient to noise and should limit signal distortion
due to reflections and other transmission line phenomena.

All CAN transceiver options we considered:

* NXP TJA1040 (or other NXP model, but this is supposedly best for being able to
  suspend)
* MCP2551 - Single CAN transceiver (not recommended need 2)
* NXP TJA1048T - Dual-CAN transceiver (recommended)
  * about 10 cents more expensive than 2 single CAN transceivers

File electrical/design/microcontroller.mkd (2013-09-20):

---
layout: electrical-design
title: Microcontroller
---

The VI was originally built around a ChipKit MAX32 development
board, which used a PIC32MX795F512 processor. We chose to move away from this
architecture due to the closed source nature of Microchip's C32 compiler for the
PIC32. It was pleasant enough using the compiler packaged with the chipKIT IDE
(MPIDE) but the licensing situation was unclear, particularly with the Microchip
Peripheral libraries (MAL).

Most other MCUs in the same performance category as the PIC32 device lie in the
[ARM-Cortex-M family](http://en.wikipedia.org/wiki/ARM_Cortex-M), particularly
the ARM Cortex-M3 core. Several major MCU manufacturers make Cortex-M3 devices
(Atmel, NXP, STMicro, TI). The NXP LPC17XX line was selected due to it's
excellent open-source compiler support, library support, and ease of
programming. Many off-the-shelf open-source hardware designs exist for the
LPC1768, and this encourages a large amount of community support and a wider
variety of user-contributed libraries.

The MCU system design was based around the [Blueboard
LPC1768-H](http://shop.ngxtechnologies.com/product_info.php?products_id=65).
This was done to allow firmware to be prototyped on an off-the-shelf open-source
hardware. The hardware configuration is also compatible with the [MBED rapid
prototyping board/environment](http://mbed.org/). The Clock, Power and USB
subsystems are all equivalent. The JTAG interface was converted to the 10-pin
ARM JTAG Mini format to reduce the PCB footprint of the normal large 20-pin JTAG
connector. This results in a 12MHz external crystal oscillator stepped up to a
100MHz system clock.

### LPC1769 Data

* [LPC1769FB100 Product Page](http://www.nxp.com/products/microcontrollers/cortex_m3/LPC1769FBD100.html)
* [LPC176X Datasheet](http://www.nxp.com/documents/data_sheet/LPC1769_68_67_66_65_64_63.pdf)
* [LPC17XX User Manual](http://www.nxp.com/documents/user_manual/UM10360.pdf)
* [Blueboard LPC1768-H Product Page](http://shop.ngxtechnologies.com/product_info.php?products_id=65)
* [Blueboard LPC1768-H Schematics V2](http://shop.ngxtechnologies.com/download/Schematics/BlueBoard/BB_LPC1768_H/Blueboard_lpc1768_H_V2.pdf)
* [mbed LPC1768 schematics](http://mbed.org/media/uploads/chris/mbed-005.1.pdf)

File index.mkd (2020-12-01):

---
layout: default
title: OpenXC Vehicle Interface Reference Design
section: overview
---

<h2>What is OpenXC?</h2>

[OpenXC](http://openxcplatform.com) is an API to your car - by installing a small hardware module
to read and translate metrics from a car's internal network, the data becomes
accessible from most Android applications using the OpenXC library. You can
start making vehicle-aware applications that have better interfaces based on
context, can minimize distraction while driving, are integrated with other
connected services, and can offer you more insight into your car's operation.
This website is the documentation for a reference design of an OpenXC-compatible
[Vehicle Interface](http://openxcplatform.com/vehicle-interface/index.html)  -
for more information on the platform in general, visit
[openxcplatform.com](http://openxcplatform.com).

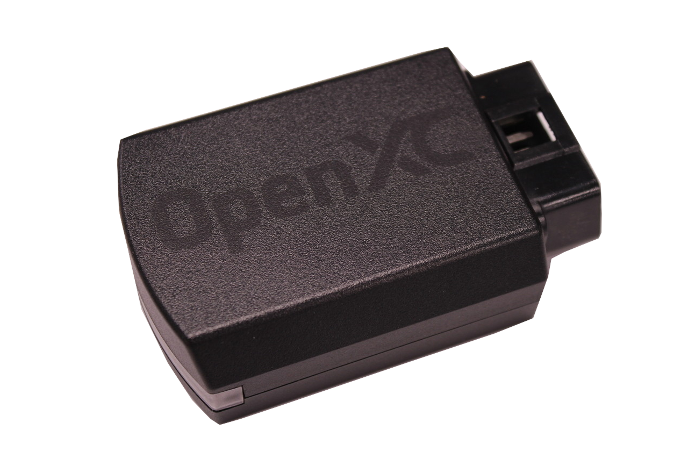
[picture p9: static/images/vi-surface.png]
Vehicle Interface

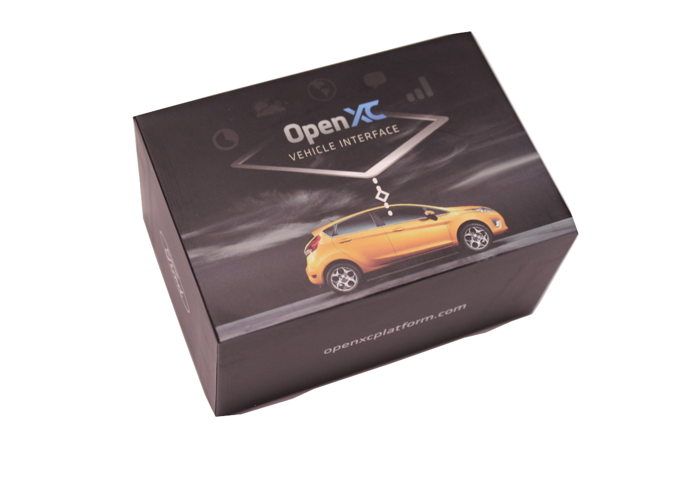
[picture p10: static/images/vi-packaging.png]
Vehicle Interface Opened Up


The [Vehicle Interface](http://openxcplatform.com/vehicle-interface/index.html)
(VI) is piece of hardware that connects to the car's CAN bus, translates
proprietary CAN messages to the standard [OpenXC message format](http://openxcplatform.com/vehicle-interface/output-format.html)
and sends the output over a common interface like USB to a [host device](http://openxcplatform.com/host-devices/hardware.html) -
this particular implementation has USB and Bluetooth.

Ford created this design and manufactured a small quantity to seed the developer
community. If you have an idea for an OpenXC application and this hardware would
help, make sure there aren't [any known issues
with
the fit](https://github.com/openxc/openxcplatform.com/wiki/Vehicle-interface-physical-fit-compatibility)
for the reference VI in your car.

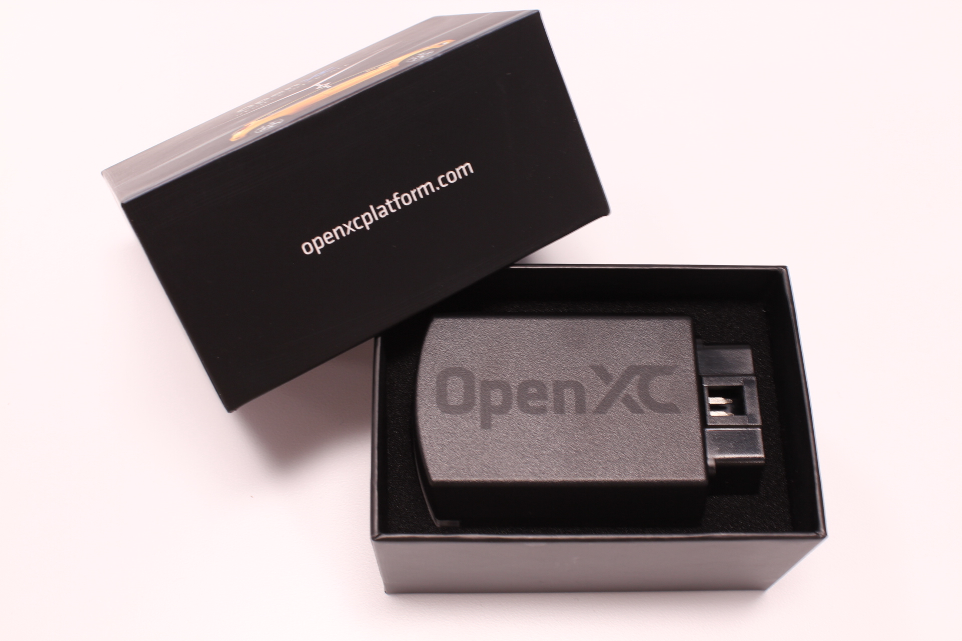
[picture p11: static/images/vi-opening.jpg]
Vehicle Interface Open

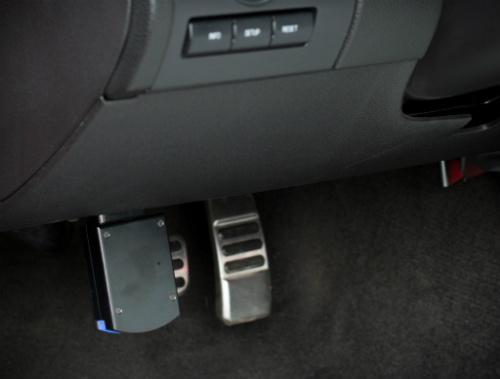
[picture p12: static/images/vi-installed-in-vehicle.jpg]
Vehicle Interface Installed in Vehicle


<h2>Quick Start</h2>

<div class="tabbable">

    <ul class="nav nav-tabs">
        <li class="active"><a href="#app-devs" data-toggle="tab">For App Developers</a></li>
        <li><a href="#firmware-devs" data-toggle="tab">For Firmware Developers</a></li>
        <li><a href="#hardware-devs" data-toggle="tab">For Hardware Developers</a></li>
    </ul>

    <div class="tab-content">

        <div class="active tab-pane" id="app-devs">

            <p>The VI needs to be programmed with firmware before you can get data
                from a car. You can use the <a href="https://github.com/openxc/vi-firmware/releases">emulator
                    firmware (zip file)</a> to test the data connection to a <a
                    href="http://openxcplatform.com/host-devices/index.html">host device</a>
                (a computer, smartphone or tablet). To get data from a real car, grab one
                of the <a href="http://openxcplatform.com/vehicle-interface/firmware.html">other
                    available firmwares</a>.
            </p>

            <p>Once you've downloaded a firmware file (it should be a version for the
                "FORDBOARD" and have the ".bin" extension) programming the VI is simple -
                follow the <a href="/firmware/programming/usb.html">USB programming
                    instructions</a>.
            </p>

        </div>

        <div class="active tab-pane" id="firmware-devs">

            <p>Besides using <a href="http://openxcplatform.com/vehicle-interface/firmware.html">binary
                    firmware for app developers</a>, you can build your own code to run on the
                VI. You can use the <a href="http://vi-firmware.openxcplatform.com">official OpenXC VI
                    firmware</a> (the source for most binary firmware, e.g. those from Ford)
                or start from scratch with a <a href="https://github.com/openxc/lpc17xx-starter">blank project</a>.</p>

            <p>Alternatively, you can use one of a few lower level programming options
                (some even allow in-circuit debugging). More details are available in the
                <a href="/firmware/index.html">firmware page</a>.
            </p>

        </div>

        <div class="active tab-pane" id="hardware-devs">

            <p>This site contains complete documentation of the hardware,
                design motivations, fabrication and testing plans. Every component is
                released as open source hardware and the source files are available in the
                <a href="https://github.com/openxc/reference-vi">openxc/reference-vi</a>
                GitHub repository (along with the contents of this website).
            </p>

        </div>

    </div>

</div>

<hr />

<h2>What is this vehicle interface?</h2>

<p>
    The particular unit is a reference design for a "dongle" style vehicle interface
    that connects directly to the diagnostic port with no cable. Ford created this
    design as an iteration from the original, <a href="https://chipkit-vi.openxcplatform.com"> chipKIT-based vehicle
        interface </a> with the goal to:
</p>

<ul>
    <li>Require no OBD-II cable to connect to the vehicle</li>
    <li>Be compact enough to sit directly on the OBD-II port and not hit the driver's
        knees</li>
    <li>Include Bluetooth by default</li>
    <li>Be powered from the vehicle and not drain the battery when left attached</li>
    <li>Provide 12v power from the vehicle to an external USB hub for other OpenXC
        hardware modules</li>
</ul>

<p>
    This streamlined vehicle interface uses a ARM Cortex-M3 microcontroller (NXP's
    LPC1769), a dual-channel CAN transceiver from NXP, the RN-41 Bluetooth
    module from Roving
    Networks and includes a micro-USB port. The design also includes a 12v port
    (with a Molex connector) to power an external device from the car, and this port
    can be shut off with the car to avoid battery drain.
</p>

<p>
    We also designed and prototyped a plastic housing for the board that allows it
    to be easily gripped and attached/detached from the OBD-II port underneath the
    steering wheel.
</p>

<p>
    The device is not as compact as it could be, primarily because we design it to
    use only a 2-layer PCB (to make it more accessible for hobbyists). Depending on
    the placement and angle of the OBD-II port in your vehicle, the VI may protrude
    too much - we recommend one of the many available <a
        href="http://www.obd2cables.com/products/obd-cables/obd-ii-cables/cable-j1962m-to-j1962f-obd-ii-extension-cable-5ft.html">OBD-II
        extension
        cables</a> if that's the case.
</p>

<p>
    The current BOM total cost for the electrical components in 1,000 unit
    quantities is around $45.
</p>

<h2>Features</h2>

<ul>
    <li>Reads from 2 different CAN buses simultaneously at up to 1Mbps per bus - by
        default CAN1 and CAN2-1 (according to the <a
            href="http://openxcplatform.com/vehicle-interface/index.html">OpenXC naming
            scheme</a>), with CAN2-2
        available behind a solder jumper
    </li>
    <li>Can relay vehicle data at up to 250kbps over a Bluetooth connection</li>
    <li>Can relay vehicle data at up to 11Mbps over a USB connection</li>
    <li>Passes up to 6A of power from the vehicle to accessories</li>
</ul>

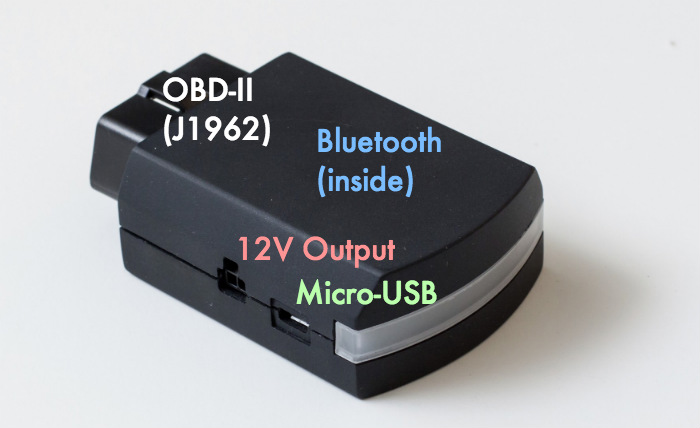
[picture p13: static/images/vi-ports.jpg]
VI Ports


<h2>Contributors</h2>

<p>
    The electrical reference design was created by Bug Labs, contracted by
    Ford and in
    collaboration with Ford Research and Innovation engineers in both <a
        href="https://corporate.ford.com/operations/locations/silicon-valley.html">Palo
        Alto, CA</a> and Dearborn, MI. For a full list of the
    contributors to this project, see the <a
        href="https://github.com/openxc/reference-vi/blob/gh-pages/AUTHORS">AUTHORS</a> file.
</p>

<h2>License</h2>

<p>
    Copyright (c) 2013 Ford Motor Company
</p>

<p>
    This vehicle interface is open source hardware. The electrical and mechanical
    designs in this repository are available under the <a
        href="http://creativecommons.org/licenses/by/4.0/deed.en_US">Creative Commons Attribution
        4.0 International</a> license.
</p>

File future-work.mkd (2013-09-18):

---
layout: overview
title: Future Work and Cost Optimization
---

These are some thoughts on how to minimize the cost of the VI.

**Remove Bluetooth**

Cost Savings: ~$25 (1000 unit quantity) by removing the module, associated
components on board and the slight size decrease that would be possible.

Negatives: No wireless support, USB only.

**Use a different MCU in the same family**

Cost Savings: ~$2 (1000 unit quantity) by going with the LPC1754 (half the price
of the LPC1769)

Negatives: Only 1 CAN controller

**Use a different MCU from another family**

Cost Savings: ?

NXP's Cortex-0 family doesn't have CAN controllers. The PIC32 family is
generally more expensive than the LPC1769. Any other options?

**Remove 12v power port**

**Remove 1 RGB LED**

Cost savings: $1

**Remove 1 button**

Cost savings: ~$0.35

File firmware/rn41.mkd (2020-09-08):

---
layout: firmware
title: RN-41 Configuration
---

After being manufactured, the RN-41 is in the default state and likely needs to
be confirgured with the correct device name and baud rate. Some firmware, like
the official [OpenXC VI firmware](/firmware/index.html) will automatically
handle this configuration each time it boots up (using the [AT-commander
library](http://github.com/openxc/at-commander)). If you need to configure it
manually, follow these instructions.

1. Apply power to the VI.
1. Discover Bluetooth devices on the PC, find the VI, and pair with it.
1. Remove power from the VI.
1. After a few moments, reapply power to the VI
1. Very quickly (within 60 seconds) connect to the VI and open a terminal
1. Type `$$$` and press enter.  If done quickly, the bluetooth LED should
      start flashing rapidly and `CMD` should be printed to the screen.
1. Type `ST,10` to reduce the configuration timer to 10 seconds.  It can also
      be disabled by executing `ST,0`.
1. Type `SU,43` to set the baud rate to 460800.
1. Type `---` to exit configuration mode
1. Remove power from the VI.  When power is reapplied, the settings will be
   changed.

The commands can also be sent via `UART0` on the LPC1769 to avoid the
configuration timer.  See [the RN-41 advanced user
manual](https://www.sparkfun.com/datasheets/Wireless/Bluetooth/rn-bluetooth-um.pdf)
for additional documentation on parameters that can be changed (Page 30 for a
quick reference)

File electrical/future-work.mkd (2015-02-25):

---
layout: electrical
title: Future Work and Cost Optimization
---

These are some thoughts on how to minimize the cost of 
the VI.

**PCB Design DFM**

Increase spacing between pin-through-holes(PIH) and surface-mount components(SMT) to allow wave soldering. For next iteration, potentially separate the two as much as possible.  
Negatives: none

**Remove Bluetooth**

Cost Savings: ~$25 (1000 unit quantity) by removing the module, associated
components on board and the slight size decrease that would be possible.

Negatives: No wireless support, USB only.

**Use a different MCU in the same family**

Cost Savings: ~$2 (1000 unit quantity) by going with the LPC1754 (half the price
of the LPC1769)

Negatives: Only 1 CAN controller

**Use a different MCU from another family**

Cost Savings: ?

NXP's Cortex-0 family doesn't have CAN controllers. The PIC32 family is
generally more expensive than the LPC1769. Any other options?

**Remove 12v power port**

**Remove 1 RGB LED**

Cost savings: $1

**Remove 1 button**

Cost savings: ~$0.35

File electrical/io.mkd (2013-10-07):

---
layout: electrical
title: Pins, Ports, Inputs and Outputs
---

Several headers and jumpers have been exposed for development purposes.  A
header has been provided to access UART0 on the LPC1769 - this can be used for
serial debug as well as [ISP programming](/firmware/programming/isp.html).  The
standard [JTAG interface](/firmware/programming/jtag.html) has also been exposed
through a 10-pin ARM JTAG Mini connector.  Two buttons have also been added to
the board - one resets the LPC1769, and the other allows the LPC1769 to enter a
[USB bootloader](/firmware/programming/usb.html) if available.

### Parts Layout

VI Ports

### Inputs/Outputs

#### Buttons

* S1 (RESET) - Pressing this button will reset the LPC1769 (it will not reset
  the RN-41 chipset)
* S2 (PROG) - This button engages a USB Bootloader. Hold down S2 while pressing
  S1 to enter the bootloader.

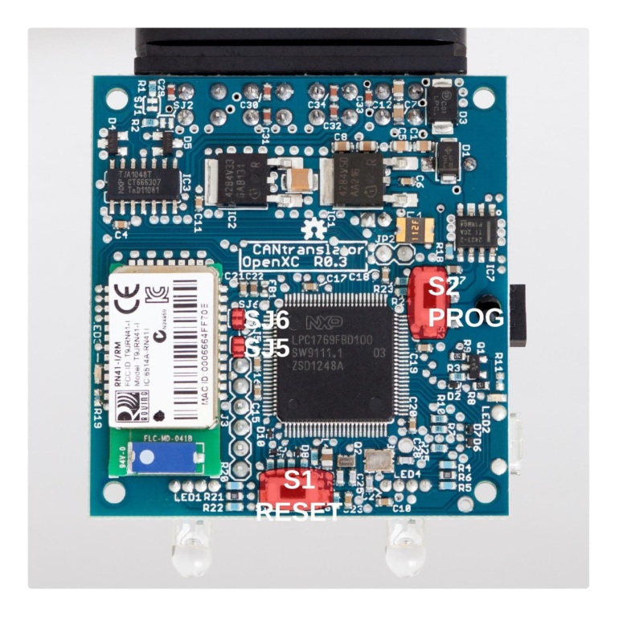
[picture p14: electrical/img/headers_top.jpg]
Interface Headers Top Interface board - headers on top side


#### Headers and jumpers

* JP1 (HOST PWR) - Shorting this jumper will allow the board to either charge an
  upstream USB device, or be powered by it.
* JP2 (ISP_EN) - Shorting this jumper will place the LPC1769 in ISP Bootloader
  mode when it is reset. In ISP Bootloader mode, user code is not run - J3 can
  only be used to deploy firmware over serial.
* J3 (ISP) - The debug serial port (UART0) which can also be used for ISP
  programming (see JP2).
* J5 (JTAG) - This is a 50 mil pitch 10-pin ARM Mini JTAG interface. An adapter
  can be used to connect the standard 100 mil 20-pin JTAG connector.

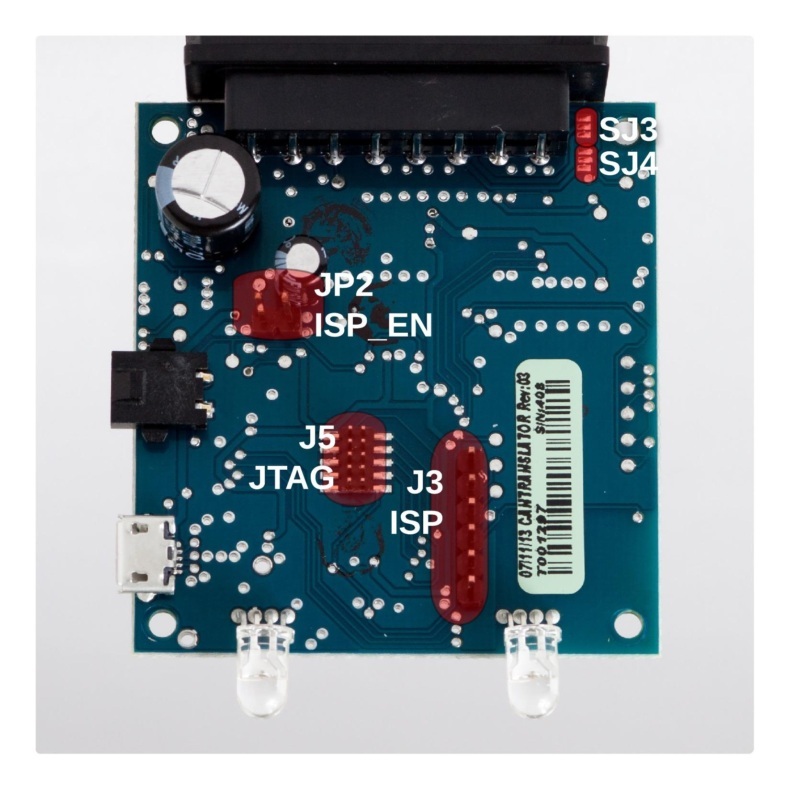
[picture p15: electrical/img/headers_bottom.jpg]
Interface Headers Bottom Interface board - headers on bottom side


#### Solder Jumpers

* SJ1, SJ2 - These are used to engage the 120 ohm termination resistor for CAN
  interfaces A and B respectively. If being used in a test bench without a full
  CAN network, you probably want these enabled. It may be simpler and more
  reversible to add the resistors to the OBD-II cable, instead. Note: The
  current version has an error in the design and this functionality is reversed - the
  resistors are enabled by default, and are disabled with the solder jumper. The
  termiation resistance should be left to the vehicle's bus in normal operation
  - see [issue #21](https://github.com/openxc/reference-vi/issues/21))
* SJ3, SJ4 - These switch the CAN B channel between the Diagnostic Medium Speed
  and Multimedia CAN buses exposed by the OBD-II connector on Ford vehicles.
  They are each shorted towards the PCB edge, enabling the Diagnostic interface
  by default.
* SJ5  - This connects the DTR line of the ISP header (J3) to the LPC1769 RESET
  line. This can be used by an ISP programmer to automatically reset the LPC1769
  for programming.  In practice, this can accidentally hold the LPC1769 in
  reset, so this jumper should be OPENED if J3 is used.
* SJ6  - This disconnects the RN-41 reset pin from the BT_RST GPIO pin on the
  LPC1769. This is normally closed, and should only be opened if the RN-41 needs
  to be put into reset without the LPC1769.

### GPIO Pin List

A list of GPIO pins used on the LPC1769

#### Port 0

* P0.2 - ISP/Debug UART: TX
* P0.3 - ISP/Debug UART: RX
* P0.4 - CAN Channel B: RX
* P0.5 - CAN Channel B: TX
* P0.6 - CAN Channel B: Enable (HIGH = Normal Mode, LOW = Standby Mode)
* P0.15 - Bluetooth UART: RX
* P0.16 - Bluetooth UART: TX
* P0.17 - Bluetooth Enable: (HIGH = RN-41 is enabled, LOW = RN-41 is in RESET)
* P0.18 - Bluetooth Connection: INPUT - Will go high when bluetooth host is
  connected
* P0.19 - CAN Channel A: Enable (HIGH = Normal Mode, LOW = Standby Mode)
* P0.21 - CAN Channel A: RX
* P0.22 - CAN Channel A: TX
* P0.29 - USB D+
* P0.30 - USB D-

#### Port 1

* P1.18 - LED4 (Right LED) Green Channel
* P1.20 - LED4 (Right LED) Blue Channel
* P1.21 - LED4 (Right LED) Red Channel
* P1.23 - LED1 (Left LED) Green Channel
* P1.24 - LED1 (Left LED) Blue Channel
* P1.26 - LED1 (Left LED) Red Channel
* P1.30 - USB VBUS: Connected to USB +5V pin

#### Port 2

* P2.2 - Bluetooth UART: RTS (LOW when RN-41 is ready for data, HIGH when RN-41
  serial buffer is full)
* P2.7 - Bluetooth UART: CTS (LOW when LPC1769 is ready for data, HIGH when
  LPC1769 serial buffer is full)
* P2.9 - USB CONNECT: Enables USB Pullup (LOW when USB unused, HIGH to signal
  USB interface is ready)
* P2.10 - ISP ENABLE: When HIGH, User code runs on next RESET. When LOW, ISP
  Serial bootloader runs on next RESET.
* P2.12 - USB Bootloader ENABLE: When HIGH, User code runs on next RESET. When
  LOW, USB bootloader runs on next RESET
* P2.13 - Power output enable (Active Low): Output power port enabled when LOW

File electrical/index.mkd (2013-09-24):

---
layout: electrical-design
title: Electrical Design Considerations
---

At the outset, we required the vehicle interface to have:

* A microcontroller with enough horsepower to process and send all CAN messages
* USB 2.0 port (controller included in microcontroller)
* 2x CAN transceivers, 2x CAN controllers
* UART with optional Bluetooth module
* Be programmable over USB with no extra hardware
* JTAG header for programming and debugging
* 6-pin ISP header for debugging
* Can be powered either via USB or the vehicle (via the OBD-II port)
* Allow USB to be attached while being vehicle powered
* Pass 12v power from the car to external peripherals

The result, documented on this site, meets all of the requirements with these
parts:

* Microcontroller: NXP LPC1769
  * Includes a [USB controller](/electrical/design/usb.html), 2 CAN controllers
    and enough UARTs for debugging and Bluetooth output
* [Dual-Channel CAN Transceiver](/electrical/design/can.html): NXP TJA1048
* Reads from 2 different CAN buses simultaneously at up to 1Mbps per bus - by
  default CAN1 and CAN2-1 (according to the [OpenXC naming
  scheme](http://openxcplatform.com/vehicle-interface/index.html)), with CAN2-2
  available behind a solder jumper
* [Bluetooth](/electrical/design/bluetooth.html): Roving Networks RN-41, with
  hardware flow control enabled
* [USB Programming](/firmware/programming/usb.html): we
  made the [OpenLPC USB
  Bootloader](https://github.com/openxc/openlpc-USB_Bootloader) compatible with
  this board and made it more reliable across all major operating systems.
* [Power](/electrical/design/power.html): up to 6A of 12v power can be passed
  through from the car, and USB can still be used when being powered by the car.

Interface Block Diagram

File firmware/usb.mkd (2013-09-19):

---
layout: firmware
title: USB Programming
---

The LPC1769 has the capability to load code from the USB interface, however this
is not built into the MCU.  In order to program over USB, a USB bootloader must
already have been programmed onto the LPC1769.  The USB Bootloader should watch
pin P2.12 (the same pin as the LPC1768 BlueBoard) on startup.  If installed
correctly, the bootloader can be actived by holding down S2 while resetting the
VI.

TODO add image

1. Use a paper clip or pencil to hold down the programming button on the VI.
1. While holding down the programming button, connect a micro-USB cable to the
   VI and to the computer you will use to do the programming - an LED on the VI
   will flash green, and then you can let go of the button. TODO add image of
   USB cable attaching
1. On Windows, OS X and Linux, the VI will appear as a typical USB drive named
   `LPC1759` - open it.
1. The drive will have a `firmware.bin` file - delete it.
1. Drag and drop the new firmware `.bin` file onto the drive.
1. Eject or unmount the drive.
1. When the drive is safe to remove, unplug the USB cable.
1. The next time you power up the VI (without pressing the programming button)
   it will be running the new firmware.

TODO point to testing guide, installing Windows drivers

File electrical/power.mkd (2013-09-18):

---
layout: default
title: Power Supply
---

### Power Section

The VI uses two heavy-duty low dropout linear regulators to
convert the unpredictable +12V automotive power source to the +5V and +3.3V
rails needed by the MCU and related ICs.  Incoming power is protected from
overvoltage by D3, a [SMBJ16CA](http://www.fairchildsemi.com/ds/SM/SMBJ16CA.pdf)
Transient Voltage Suppressor (TVS) diode.  D3 will protect the interface from
any voltage over 19.7V (Vbr).  The power regulators can handle up to 40V, but
the Dock power switch (IC7) can only tolerate up to 20V.  Reverse voltage is
protected by D1.  Both regulators do not require any additional current or
temperature protection - they can safely drive into a short circuit at
temperatures up to 150 degrees C, and will limit current if they become too hot.
Plenty of bulk and bypass capacitance has been provided to absorb automotive
power transients.

The regulators are cascaded such that the +5V rail supplies the +3.3V rail.  The
TLE4284DV33 has a maximum voltage drop of 1.4V, so it can be safely powered by
any source above 4.7V.  While this puts additional load on the +5V rail, it also
allows the interface to be powered either by the OBD-II connector or the
MicroUSB port.  Both regulators can deliver current up to 1.6A.  Current budget:

* 5V regulator capacity: 1600mA
* USB Charging Limit (fuse): 1000mA
* RN-41 average TX rate: 60mA
* LPC1769 Base consumption @ 100MHz: 50mA
* LPC1769 peripherals (2xCAN+2xUART): 3mA
* Both RGB LEDs on at full: 60mA
* TJA1048T both channels dominant: 140mA
* Total: 1313mA

This yields a headroom of ~300mA when all peripherals are active and a Tablet is
charging at 1A.

### Power Input/Output

The VI has the following power connections:

* OBD-II Automotive Power: Input @ 12V
* Dock Power Connector: Output @ 5V up to 6A
* USB Micro Connector: Input OR Output @5V up to 1A

The Dock power connector is controlled by a [TPS2421-2 power switch with
internal MOSFET](http://www.ti.com/lit/ds/symlink/tps2421-2.pdf).  This allows
the Dock power to be disabled when the vehicle is turned off, as well as
providing current protection.  The power switch has an active 6A limit, and will
actively attempt to re-engage power when the limit is tripped ("retry on
fault").

The USB Micro Connector is directly connected to the +5V bus through a Fuse.
The lack of a diode means that the connected USB device can either consume or
supply current.  If a PC is connected to the USB Micro connector, it will power
the 3.3V regulator and the +5V regulator will be bypassed.  If an android tablet
is connected that supports USB OTG Charging, it will be allowed to consume +5V
power.  A resettable fuse (F1) has been added to protect the VI
from a bad USB cable or USB Host.  The fuse is a [Bourns
MF-MSMF110/16-2](http://www.bourns.com/pdfs/mfmsmf.pdf).  The fuse will
automatically reset when power is removed and the fuse is allowed to cool off.
This has an added downside of temperature dependence - the fuse can only pass
the full 1A of current up to 40 degrees C.  Above that temperature the limit
slowly decreases - see the datasheet for a thermal derating chart.

Some notes on the power supply, designed by Kevin Hille and Karl Wojcik.

* One of the 330 caps at the top, going into the 5v regulator, is missing the
  polarity sign - the top line should have the +.
* C5 protects from low voltage dropout
* Diodes make sure reversing 12v and ground doesn't blow anything up
* c3/c4 are high frequency filters to protect from a voltage dropout
* 47uF - keeps 3v3 regulator stable and protects from dropouts
* Could take the 3.3v regulator off of the 5v to minimize the heat that has to
  be dissapated - going from 5 -> 3.3 instead of 12 -> 3.3v.
  * Fill in the copper around the regulator as a heatsink

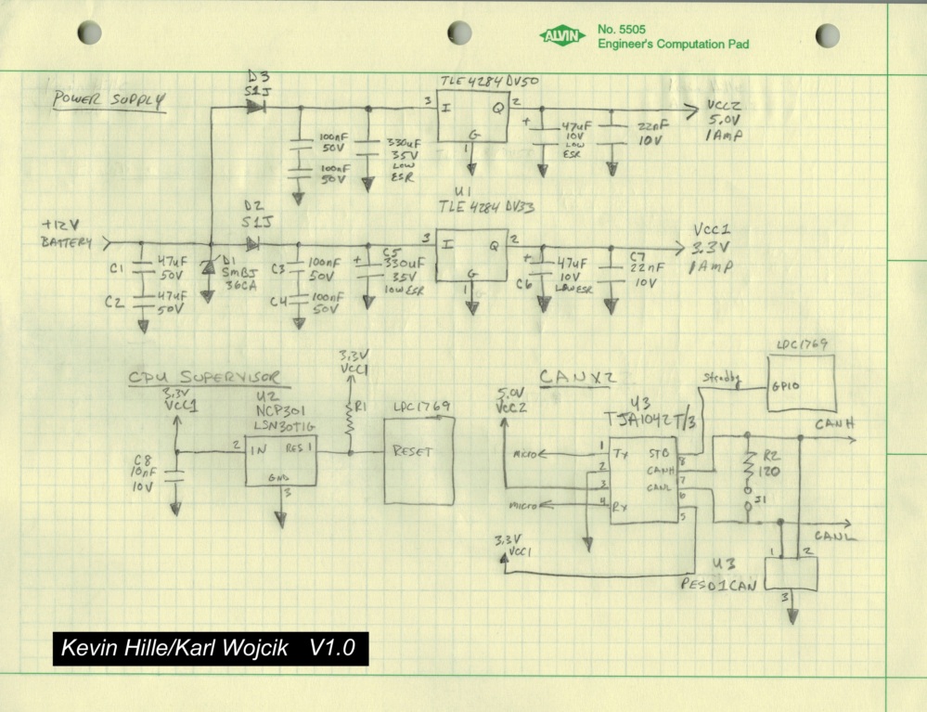
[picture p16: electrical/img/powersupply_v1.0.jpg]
Power Supply Schematic


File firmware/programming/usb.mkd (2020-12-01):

---
layout: programming
title: USB Programming
---

All of the reference VI units manufactured so far are pre-programmed with a USB
bootloader (the OpenXC fork of the [OpenLPC USB
Bootloader](https://github.com/openxc/openlpc-USB_Bootloader)). This means you
can re-flash the device using USB, with no extra hardware required.

<p>
To verify the VI was flashed correctly, we recommend trying the
<a href="http://openxcplatform.com/android/getting-started.html">Android "smoke test"</a> to make sure everything's working.
You can also <a href="http://openxcplatform.com/python/getting-started.html">test from a regular computer with Python</a>, but it's a
bit more involved if you're not already familiar with the tools.
</p>

<p>
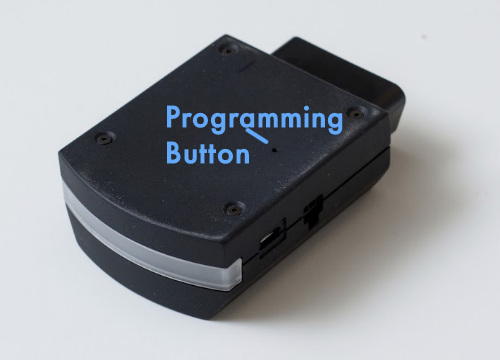
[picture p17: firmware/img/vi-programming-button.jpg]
Programming Button

</p>

<div class="panel-group" id="accordian">

   <div class="panel panel-default">
      <div class="panel-heading">
         <h4 class="panel-title">
            <a class="accordian-toggle" data-toggle="collapse"
                  data-parent="#accordian" href="#collapseMac">
               Mac OS X
            </a>
         </h4>
      </div>
      <div id="collapseMac" class="panel-collapse collapse">
         <div class="panel-body">
            <p>Use a paper clip or pencil to hold down the programming button on
            the VI. While holding down the programming button, connect a
            micro-USB cable to the VI and to the computer you will use to do the
            programming - an LED on the VI will flash green, and then you can
            let go of the button.
            </p>

            <p>
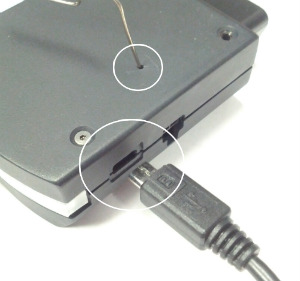
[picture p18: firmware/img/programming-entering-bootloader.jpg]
Entering the Bootloader
            
            </p>

            <p>
            If your VI has the v1.1 bootloader, i.e. it <strong>does</strong>
            have an OpenXC sticker on the housing, you can copy the new
            firmware over in Finder. Browse to the LPC1759 drive that appears
            when you run it in bootloader mode, delete the firmware.bin file and
            copy your new firmware file .bin over (the new filename doesn't
            matter).
            </p>

            <p>Eject the LPC1759 drive and unplug the VI. It's flashed!</p>

            <p>Eject the LPC1759 drive and unplug the VI. It's flashed!</p>
            
            <p>
            Note: The <code>LPC1759/firmware.bin</code> file you see in Finder is
            <a href="https://github.com/openxc/openlpc-USB_Bootloader#flashing-user-code">just a placeholder</a>. 
            To check if your firmware is properly flashed, plug in the VI via 
            USB and try running <code>openxc-control version</code>
            <a href="http://openxcplatform.com/python/getting-started.html">from the Terminal</a>
            to get the firmware version.
            </p>

         </div>
      </div>
   </div>

   <div class="panel panel-default">
      <div class="panel-heading">
         <h4 class="panel-title">
            <a class="accordian-toggle" data-toggle="collapse"
                  data-parent="#accordian" href="#collapseLinux">
               Linux
            </a>
         </h4>
      </div>
      <div id="collapseLinux" class="panel-collapse collapse">
         <div class="panel-body">

            <p>Use a paper clip or pencil to hold down the programming button on the VI. While
            holding down the programming button, connect a micro-USB cable to the VI and to
            the computer you will use to do the programming - an LED on the VI will flash
            green, and then you can let go of the button.
            </p>

            <p>
            Entering the Bootloader
            </p>

            <p>
            If your VI has the v1.1 bootloader, i.e. it <strong>does</strong>
            have an OpenXC sticker on the housing, you can copy the new
            firmware over in any file manager. Browse to the LPC1759 drive that
            appears when you run it in bootloader mode, delete the firmware.bin
            file and copy your new firmware file .bin over (the new filename
            doesn't matter). Eject the LPC1759 drive and unplug the VI. It's
            flashed!
            </p>

         </div>
      </div>
   </div>

   <div class="panel panel-default">
      <div class="panel-heading">
         <h4 class="panel-title">
            <a class="accordian-toggle" data-toggle="collapse"
                  data-parent="#accordian" href="#collapseWindows">
               Windows
            </a>
         </h4>
      </div>
      <div id="collapseWindows" class="panel-collapse collapse">
         <div class="panel-body">

            <p>Use a paper clip or pencil to hold down the programming button on the VI. While
            holding down the programming button, connect a micro-USB cable to the VI and to
            the computer you will use to do the programming - an LED on the VI will flash
            green, and then you can let go of the button.
            </p>

            <p>
            Entering the Bootloader
            </p>

            <p>The VI will appear as a typical USB drive named
            <code>LPC1759</code> - open it.</p>

            <p>
            USB drive
            </p>

            <p>
            The drive will have a <code>firmware.bin</code> file - delete it.
            </p>

            <p>
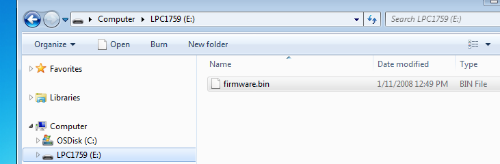
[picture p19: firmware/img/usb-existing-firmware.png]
Existing firmware
            
            </p>

            <p>
            Drag and drop the new firmware <code>.bin</code> file onto the drive.
            </p>

            <p>
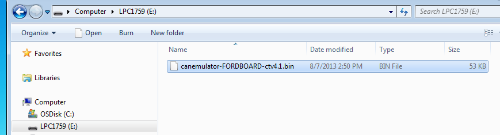
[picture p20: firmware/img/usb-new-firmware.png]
New firmware
            
            </p>

            <p>
            Eject or unmount the drive. When the drive is safe to remove, unplug the USB
            cable.
            </p>

            <p>
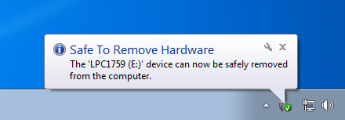
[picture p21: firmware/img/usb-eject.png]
Safe to remove
            
            </p>

            <p>
            The next time you power up the VI (without pressing the programming button) it
            will be running the new firmware.
            </p>
            <p>
            Note: The <code>LPC1759/firmware.bin</code> file you see in Windows
            Explorer is <a href="https://github.com/openxc/openlpc-USB_Bootloader#flashing-user-code">just a placeholder</a>. 
            To check if your firmware is properly flashed, plug in the VI via 
            USB and try running <code>openxc-control version</code>
            <a href="http://openxcplatform.com/python/getting-started.html">from the command line</a>
            to get the firmware version.
            </p>
         </div>
      </div>
   </div>

</div>

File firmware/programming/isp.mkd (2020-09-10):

---
layout: programming
title: ISP Programming
---

If a [3.3V USB-Serial converter is
available](https://www.sparkfun.com/products/9873), the device can be programmed
using the ISP header, J3.  To use ISP simply short JP2 and reset the LPC1769.
If the ISP_EN pin is grounded when the LPC1769 boots, it will enter the built-in
ISP bootloader instead of running the OpenXC firmware.  UART0 will then be used
for programming under an application like [Flash
Magic](http://www.flashmagictool.com/).  

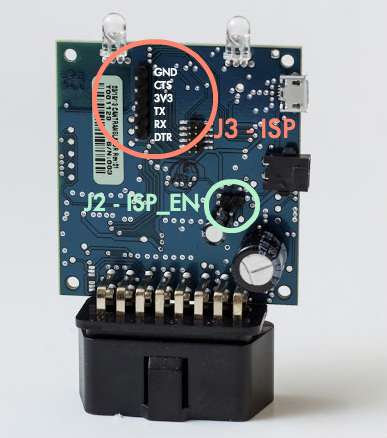
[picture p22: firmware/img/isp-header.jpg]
ISP Header


The setup using Flash Magic are as follow:

1. Connect to the OpenXC VI board using 3.3V USB-Serial converter, with exactly each pins on USB-Serial converter connect to the OpenXC VI board as shown on the above
2. Short JP2 with a proper connector or jumper cable 
3. Use Flash Magic and set the following programming paratmeters:

	- Select LPC1769 device from dropdown list
	- Select the correct COM port
	- Set Baud rate to 38400
	- Set Oscillator frequency to 12000000
	- Check "Erase all Flash+Code Rd Prot" box
	- Check "Verify after programming" box
	- Select the downloaded [bootloader hex file](/firmware/programming/Bootloader.hex)

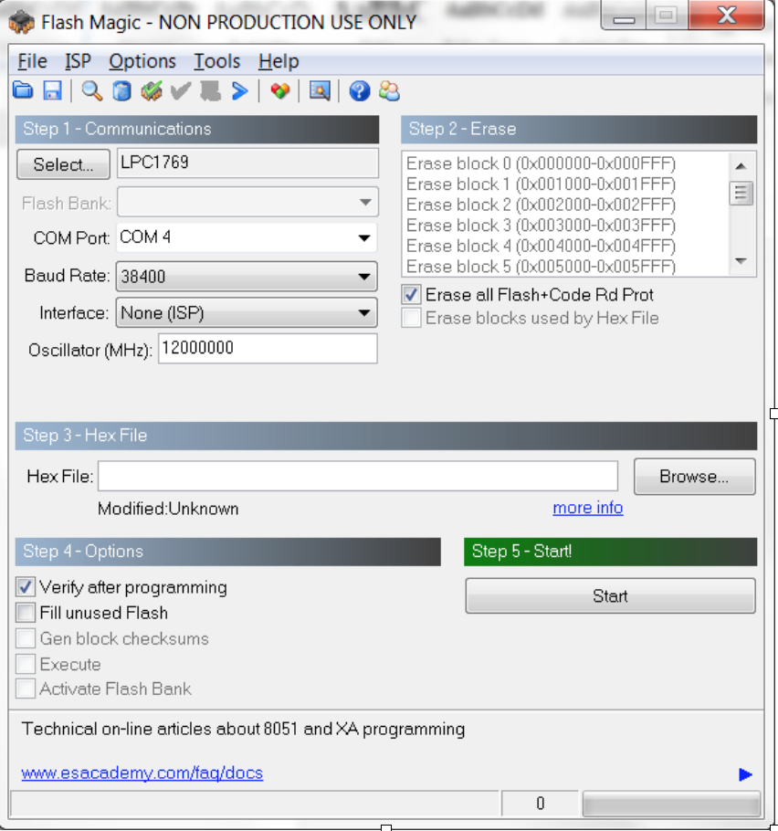
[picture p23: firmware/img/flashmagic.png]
flash magic


Step 4: 
	Click Start in Flash Magic!

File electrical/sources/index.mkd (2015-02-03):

---
layout: electrical
title: Electrical Source Files
---

The board was designed with Cadsoft EAGLE, and the source files should be
compatible with the free Light Edition.

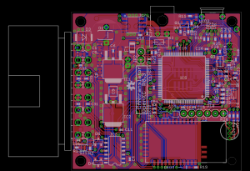
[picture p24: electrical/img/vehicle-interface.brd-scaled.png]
Layout

Schematic

The files are all [stored in a Git repository at
GitHub](https://github.com/openxc/reference-vi/tree/gh-pages/electrical/sources) -
pull requests are welcome!

* Electrical Schematic
  * [EAGLE source](/electrical/sources/vehicle-interface.sch)
  * [PDF](/electrical/sources/vehicle-interface.sch.pdf)
* Board Layout
  * [EAGLE source](/electrical/sources/vehicle-interface.brd)
  * [PNG image](/electrical/sources/vehicle-interface.brd.png)
* [Bill of Materials (BOM)](/electrical/sources/vehicle-interface.bom-v3.xls)
* [Changelog](/electrical/CHANGELOG.xls)

VI PCB Top
VI PCB Bottom

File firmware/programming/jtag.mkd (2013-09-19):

---
layout: programming
title: JTAG Programming
---

To program using JTAG, any ARM Cortex M3 compatible JTAG adapter can be used.
The interface has been tested using an
[ARM-USB-TINY-H](https://www.olimex.com/Products/ARM/JTAG/ARM-USB-TINY-H/) and
an [ARM-USB-OCD-H](https://www.olimex.com/Products/ARM/JTAG/ARM-USB-OCD-H/) by
Olimex.  The interface board does not have a full-size 20-pin JTAG connector -
[an adapter will be required with most JTAG
programmers](https://www.olimex.com/Products/ARM/JTAG/ARM-JTAG-20-10/).  Simply
plug the ARM-JTAG-MINI connector into J5 on the bottom side of the vehicle
interface PCB.  Make sure that the ribbon cable exits the connector in the
direction of the arrow on the PCB.

JTAG Header

With the JTAG adapter connected, and power applied to the board, the LPC1769
should respond to commands from [OpenOCD](http://openocd.sourceforge.net/).  If
deploying code from an OpenXC repository, the board can be programmed by simply
executing "make flash" from the root of the source tree.  See other LPC17XX JTAG
tutorials for more information, the process is nearly identical across all
LPC17XX devices.



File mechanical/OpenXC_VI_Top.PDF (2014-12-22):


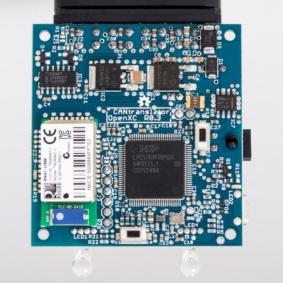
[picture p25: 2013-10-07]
static/images/vi-front-square.jpg

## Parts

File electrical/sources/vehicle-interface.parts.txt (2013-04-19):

Partlist

Exported from CANtranslator.sch at 3/11/13 7:49 PM

EAGLE Version 6.1.0 Copyright (c) 1988-2012 CadSoft

Assembly variant: 

Part     Value                     Device                        Package               Library                    Sheet

C1       0.1u                      CAP0805                       0805                  BUG                        1
C2       150u                      CAP_POL5MMX2D                 CPOL-5MMX2D           BUG                        1
C3       270u                      CAP_POL10MMX5D                CPOL-10MMX5D          BUG                        1
C4       22n                       CAP0402-CAP                   0402-CAP              BUG                        1
C5       0.1u                      CAP0805                       0805                  BUG                        1
C6       0.1u                      CAP0402-CAP                   0402-CAP              BUG                        1
C7       0.47u                     CAP0805                       0805                  BUG                        1
C8       0.1u                      CAP0805                       0805                  BUG                        1
C9       47u                       CAP1210                       1210                  BUG                        1
C10      0.1u                      CAP0402-CAP                   0402-CAP              BUG                        1
C11      22n                       CAP0402-CAP                   0402-CAP              BUG                        1
C12      0.47u                     CAP0805                       0805                  BUG                        1
C13      0.1u                      CAP0805                       0805                  BUG                        1
C14      10u                       CAP0805                       0805                  BUG                        1
C15      0.1u                      CAP0402-CAP                   0402-CAP              BUG                        1
C16      0.1u                      CAP0402-CAP                   0402-CAP              BUG                        1
C17      0.1u                      CAP0402-CAP                   0402-CAP              BUG                        1
C18      0.1u                      CAP0402-CAP                   0402-CAP              BUG                        1
C19      0.1u                      CAP0402-CAP                   0402-CAP              BUG                        1
C20      0.1u                      CAP0402-CAP                   0402-CAP              BUG                        1
C21      0.1u                      CAP0402-CAP                   0402-CAP              BUG                        1
C22      1u                        CAP0402-CAP                   0402-CAP              BUG                        1
C23      0.1u                      CAP0402-CAP                   0402-CAP              BUG                        1
C24      18p                       CAP0402-CAP                   0402-CAP              BUG                        1
C25      18p                       CAP0402-CAP                   0402-CAP              BUG                        1
C26      18p                       CAP0402-CAP                   0402-CAP              BUG                        1
C27      1u                        CAP0402-CAP                   0402-CAP              BUG                        1
C28      18p                       CAP0402-CAP                   0402-CAP              BUG                        1
C29      100p                      CAP0402-CAP                   0402-CAP              BUG                        1
C30      100p                      CAP0402-CAP                   0402-CAP              BUG                        1
C31      100p                      CAP0402-CAP                   0402-CAP              BUG                        1
C32      100p                      CAP0402-CAP                   0402-CAP              BUG                        1
C33      100p                      CAP0402-CAP                   0402-CAP              BUG                        1
C34      100p                      CAP0402-CAP                   0402-CAP              BUG                        1
D1       RS1J                      DIODESMA                      SMA-DIODE             BUG                        1
D2       PESD12VS1ULD              DIODE-TVS-SOD882D             SOD-882D              BUG                        1
D3       1SMB16CAT3G               DIODE-TVS-SMB                 SMB-DIODE             BUG                        1
D4       PESD1CAN                  DIODE_ESD_DUAL-SOT-23         SOT23                 BUG                        1
D5       PESD1CAN                  DIODE_ESD_DUAL-SOT-23         SOT23                 BUG                        1
D6       PESD5V0X1BL               DIODE_ESD_BI-SOD882           SOD-882               BUG                        1
D7       PESD5V0X1BL               DIODE_ESD_BI-SOD882           SOD-882               BUG                        1
D8                                 DIODE_ESD_DUAL-SOT-1123       SOT-1123              BUG                        1
D9                                 DIODE_ESD_DUAL-SOT-1123       SOT-1123              BUG                        1
D10                                DIODE_ESD_DUAL-SOT-1123       SOT-1123              BUG                        1
F1       MF-MSMF110/16-2           PTCFUSE-1206                  R1206                 adafruit                   1
FB1      742843122                 INDUCTOR0402                  C0402                 BUG                        1
IC1      LM340S-50                 V_REG_317DPACK                V-REG_DPACK           SparkFun-PowerIC           1
IC2      TLE4284DV33               V_REG_317DPACK                V-REG_DPACK           SparkFun-PowerIC           1
IC3      TJA1048T                  TJA1048-SO14                  SO14                  BUG                        1
IC5      LPC1769FBD100             LPC1768_SPLIT-TQFP            TQFP100               BUG                        1
IC6      RN41-I/RM                 BLUETOOTH-RN41"               RN41                  SparkFun-RF                1
IC7      TPS2421-2                 TPS2421SO8                    POWER_SO8             BUG                        1
J1       USB_MINIB_SHIELD-10118193 USB_MINIB_SHIELD-10118193     10118193              BUG                        1
J2       OBDII                     M08X2-OBDII-COMTECH           OBDII-COMTECH         BUG                        1
J3       ISP                       ARDUINO_SERIAL_PROGRAMPTH     1X06                  SparkFun-Connectors        1
J4       PWR OUT                   M022-1445055-2                2-1445055-2           BUG                        1
J5       ARM mini-JTAG             M05X2-SHF-105-01-X-D-SM       SHF-105-01-X-D-SM     BUG                        1
JP2      ISP_EN                    M02PTH                        1X02                  SparkFun-Connectors        1
LED1     RGB                       LED_3X_COMMON_CATHODE         LED5MM-RGB            BUG                        1
LED2     SML-LX0603SRW             LED0603                       LED-0603              BUG                        1
LED3     SML-LX0603SRW             LED0603                       LED-0603              BUG                        1
LED4     RGB                       LED_3X_COMMON_CATHODE         LED5MM-RGB            BUG                        1
Q1       BC856                     TRANSISTOR_PNPSMD             SOT23-3               SparkFun-DiscreteSemi      1
Q2       32k                       CRYSTAL-ST2012SB              ST2012SB              BUG                        1
Q3       12M                       CRYSTAL-CX3225SB              CX3225SB              BUG                        1
R1       120                       RESISTOR0402-RES              0402-RES              BUG                        1
R2       120                       RESISTOR0402-RES              0402-RES              BUG                        1
R3       10k                       RESISTOR0402-RES              0402-RES              BUG                        1
R4       17.4                      RESISTOR0402-RES              0402-RES              BUG                        1
R5       143                       RESISTOR0402-RES              0402-RES              BUG                        1
R6       30                        RESISTOR0402-RES              0402-RES              BUG                        1
R7       33E                       RESISTOR0402-RES              0402-RES              BUG                        1
R8       1.5k                      RESISTOR0402-RES              0402-RES              BUG                        1
R9       2k                        RESISTOR0402-RES              0402-RES              BUG                        1
R10      33E                       RESISTOR0402-RES              0402-RES              BUG                        1
R11      560                       RESISTOR0402-RES              0402-RES              BUG                        1
R12      10k                       RESISTOR0402-RES              0402-RES              BUG                        1
R13      10k                       RESISTOR0402-RES              0402-RES              BUG                        1
R14      10k                       RESISTOR0402-RES              0402-RES              BUG                        1
R15      4.7k                      RESISTOR0402-RES              0402-RES              BUG                        1
R16      10k                       RESISTOR0402-RES              0402-RES              BUG                        1
R17      10k                       RESISTOR0402-RES              0402-RES              BUG                        1
R18      49.9k                     RESISTOR0402-RES              0402-RES              BUG                        1
R19      560                       RESISTOR0402-RES              0402-RES              BUG                        1
R20      143                       RESISTOR0402-RES              0402-RES              BUG                        1
R21      30                        RESISTOR0402-RES              0402-RES              BUG                        1
R22      17.4                      RESISTOR0402-RES              0402-RES              BUG                        1
R23      10k                       RESISTOR0402-RES              0402-RES              BUG                        1
R24      10k                       RESISTOR0402-RES              0402-RES              BUG                        1
R25      120                       RESISTOR0402-RES              0402-RES              BUG                        1
R25B     DNP                       RESISTORPTH-1/4W              AXIAL-0.4             BUG                        1
S1       RESET                     SWITCH-MOMENTARY-2-SMD-1101NE TACTILE-SWITCH-1101NE SparkFun-Electromechanical 1
S2       PROG                      SWITCH-MOMENTARY-2-SMD-1101NE TACTILE-SWITCH-1101NE SparkFun-Electromechanical 1
SJ1      CLOSED                    SOLDERJUMPERTRACE             SJ_2S-TRACE           SparkFun-Passives          1
SJ2      CLOSED                    SOLDERJUMPERTRACE             SJ_2S-TRACE           SparkFun-Passives          1
SJ3                                SOLDERJUMPER_2WAYPASTE1&2     SJ_3_PASTE1&2         SparkFun-Passives          1
SJ4                                SOLDERJUMPER_2WAYPASTE1&2     SJ_3_PASTE1&2         SparkFun-Passives          1
SJ5      OPEN                      SOLDERJUMPERNO                SJ_2S-NO              SparkFun-Passives          1
SJ6      CLOSED                    SOLDERJUMPERTRACE             SJ_2S-TRACE           SparkFun-Passives          1
TP1                                TEST-POINT3X5                 PAD.03X.05            SparkFun-Passives          1
TP2                                TEST-POINT3X5                 PAD.03X.05            SparkFun-Passives          1
TP3                                TEST-POINT3X5                 PAD.03X.05            SparkFun-Passives          1
TP4                                TEST-POINT3X5                 PAD.03X.05            SparkFun-Passives          1
TP5                                TEST-POINT3X5                 PAD.03X.05            SparkFun-Passives          1
TP6                                TEST-POINT3X5                 PAD.03X.05            SparkFun-Passives          1
TP7                                TEST-POINT3X5                 PAD.03X.05            SparkFun-Passives          1
TP8                                TEST-POINT3X5                 PAD.03X.05            SparkFun-Passives          1
TP9                                TEST-POINT3X5                 PAD.03X.05            SparkFun-Passives          1
TP10                               TEST-POINT3X5                 PAD.03X.05            SparkFun-Passives          1
TP11                               TEST-POINT3X5                 PAD.03X.05            SparkFun-Passives          1
TP12                               TEST-POINT3X5                 PAD.03X.05            SparkFun-Passives          1
TP13                               TEST-POINT3X5                 PAD.03X.05            SparkFun-Passives          1
TP14                               TEST-POINT3X5                 PAD.03X.05            SparkFun-Passives          1
TP15                               TEST-POINT3X5                 PAD.03X.05            SparkFun-Passives          1
TP16                               TEST-POINT3X5                 PAD.03X.05            SparkFun-Passives          1
TP17                               TEST-POINT3X5                 PAD.03X.05            SparkFun-Passives          1
TP18                               TEST-POINT3X5                 PAD.03X.05            SparkFun-Passives          1
TP19                               TEST-POINT3X5                 PAD.03X.05            SparkFun-Passives          1
TP20                               TEST-POINT3X5                 PAD.03X.05            SparkFun-Passives          1
TP21                               TEST-POINT3X5                 PAD.03X.05            SparkFun-Passives          1
TP22                               TEST-POINT3X5                 PAD.03X.05            SparkFun-Passives          1
TP23                               TEST-POINT3X5                 PAD.03X.05            SparkFun-Passives          1

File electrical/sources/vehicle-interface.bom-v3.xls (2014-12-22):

Level | Number | Part Type | Description | Rev | Lifecycle Phase | Commodity Code | Customer(s) | Rev Incorp Date | Rev Release Date | Effectivity Date | Exclude from Rollup | Compliance Calculated Date | Overall Compliance | Shippable Item | Part Family | Size | Sites | BOM.Position # | BOM.MSS Sequence | BOM.Item Description | BOM.Item Rev | BOM.Effective Date | BOM.Qty | BOM.UOM | BOM.MSS Alternate Part % | BOM.MSS Prime Item | BOM.Ref Des | BOM.BOM Notes | BOM.Item Lifecycle Phase | BOM.Item Type | BOM.Item Group | BOM.Part Type | BOM.Customer Part Number | BOM.Customer Rev | BOM.Legacy Part Number | BOM.Phantom | BOM.Operation Seq. | BOM.Warehouse | BOM.Point of usage | BOM.Scrap Factor | BOM.Lead Time Offset | BOM.LTO Value | BOM.Number of Notes | BOM.Extra Information | BOM.Signal Code | BOM.MSS Sequence Trigger | BOM.Customer Part Number & Revision History (Automotive) | BOM.Legacy Part Number & Revision History (Automotive) | BOM.Scrap Qty | Manufacturers.Mfr. Name | Manufacturers.Mfr. Part Number | Manufacturers.Status | Manufacturers.Manufacturer Code | Manufacturers.Mfr. Part Lifecycle Phase | Manufacturers.Comments | Manufacturers.MFG REPLACED BY | Manufacturers.MPN Validated | Manufacturers.AML Expired Date | Manufacturers.Packing Type
0 | 335-FMC-3000-000035 | Part | FORD, DIAGNOSTIC UNIT | X4-1 FNP-050321 | Prototype |  | FORD MOTOR COMPANY |  | 11/24/2014 03:04:45 PM PST | 11/24/2014 12:00:00 AM PST | No |  |  | No |  |  |  |  |  |  |  |  |  |  |  |  |  |  |  |  |  |  |  |  |  |  |  |  |  |  |  |  |  |  |  |  |  |  |  | FLEXTRONICS INTERNATIONAL | 3000-000035 | Active | M45840 | Active
1 | 335-FMC-320-000446 | Part | VI TOP | X1 FNP-047754 | Prototype |  | FORD MOTOR COMPANY |  | 09/05/2014 06:43:25 PM PDT | 09/05/2014 12:00:00 AM PDT | No |  |  | No |  |  |  | 10 |  | VI TOP | X1 FNP-047754 | 09/05/2014 12:00:00 AM PDT | 1 | ea |  |  |  |  | Prototype | PURCHASED | FMCAPP | Part | 320-000446 | X1 |  |  |  |  |  |  |  |  |  |  |  | 0 |  |  |  | MODEL SOLUTION | VI TOP | Active | MA4937 | Active
1 | 335-FMC-320-000447 | Part | VI BOTTOM | X1 FNP-047754 | Prototype |  | FORD MOTOR COMPANY |  | 09/05/2014 06:43:25 PM PDT | 09/05/2014 12:00:00 AM PDT | No |  |  | No |  |  |  | 20 |  | VI BOTTOM | X1 FNP-047754 | 09/05/2014 12:00:00 AM PDT | 1 | ea |  |  |  |  | Prototype | PURCHASED | FMCAPP | Part | 320-000447 | X1 |  |  |  |  |  |  |  |  |  |  |  | 0 |  |  |  | MODEL SOLUTION | VI BOTTOM | Active | MA4937 | Active
1 | 335-FMC-320-000448 | Part | VI DIFFUSER | X1 FNP-047754 | Prototype |  | FORD MOTOR COMPANY |  | 09/05/2014 06:43:25 PM PDT | 09/05/2014 12:00:00 AM PDT | No |  |  | No |  |  |  | 30 |  | VI DIFFUSER | X1 FNP-047754 | 09/05/2014 12:00:00 AM PDT | 1 | ea |  |  |  |  | Prototype | PURCHASED | FMCAPP | Part | 320-000448 | X1 |  |  |  |  |  |  |  |  |  |  |  | 0 |  |  |  | MODEL SOLUTION | VI DIFFUSER | Active | MA4937 | Active
1 | 335-FMC-HWR-00001267-000 | Part | SCREW M2x12MM METRIC BLACK CARBON STEEL PHILLIPS FLAT HEAD | 01 FNP-050254 | Prototype | Screws | FORD MOTOR COMPANY |  | 11/20/2014 01:54:16 PM PST | 11/20/2014 12:00:00 AM PST | No |  |  | No |  |  |  | 40 |  | SCREW M2x12MM METRIC BLACK CARBON STEEL PHILLIPS FLAT HEAD | 01 FNP-050254 | 11/20/2014 12:00:00 AM PST | 4 | ea |  |  |  |  | Prototype | PURCHASED | FMCAPP | Part | HWR-00001267-000 |  |  |  |  |  |  |  |  |  |  |  |  | 0 |  |  |  | PENCOM | BUY BY DESCRIPTION | Active | M06565 | Active
1 | 335-FMC-PCA-00001186-000 | Part | PCA,FMC,DIAGNOSTIC | 02 FNP-050529 | Prototype |  | FORD MOTOR COMPANY |  | 12/03/2014 04:57:37 PM PST | 12/03/2014 12:00:00 AM PST | No |  |  | No |  |  |  | 50 |  | PCA,FMC,DIAGNOSTIC | 02 FNP-050529 | 12/03/2014 12:00:00 AM PST | 1 | ea |  |  |  |  | Prototype | MANUFACTURED | FMCBAM | Part | PCA-00001186-000 | 1 |  |  |  |  |  |  |  |  |  |  |  | 0 |  |  |  | FLEXTRONICS INTERNATIONAL | PCA-00001186-000 | Active | M45840 | Active
2 | 335-FMC-CON-00001146-000 | Part | CONN HEADER 6 POS 2.54 | A MLG-078457 | Prototype |  | FORD MOTOR COMPANY |  | 11/18/2014 03:37:51 PM PST |  | No |  |  | No |  |  |  | 10 |  | CONN HEADER 6 POS 2.54 | A MLG-078457 |  | 1 | ea |  |  | J3 |  | Prototype | PURCHASED | FMCAPP | Part | CON-00001146-000 | A |  |  |  |  |  |  |  |  |  |  |  | 0 |  |  |  | WURTH | 613 006 111 21 | Active | MB1918 | Active | // |  | Yes |  | Bulk BLK
2 | 335-FMC-CAP-00001147-000 | Part | CAP CER 1UF 6.3V 10% X5R 0603 | A MLG-078457 | Prototype |  | FORD MOTOR COMPANY |  | 11/18/2014 03:37:51 PM PST |  | No |  |  | No |  |  |  | 20 |  | CAP CER 1UF 6.3V 10% X5R 0603 | A MLG-078457 |  | 2 | ea |  |  | C22,C27 |  | Prototype | PURCHASED | FMCC1P | Part | CAP-00001147-000 | A |  |  |  |  |  |  |  |  |  |  |  | 0 |  |  |  | AVX/KYOCERA | 06036D105KAT2A | Active | M01800 | Active | // |  | Yes |  | Tape and Reel TR
2 | 335-FMC-CON-00001148-000 | Part | CONN USB MICRO B RECPT SMT R/A | A MLG-078457 | Prototype |  | FORD MOTOR COMPANY |  | 11/18/2014 03:37:51 PM PST |  | No |  |  | No |  |  |  | 30 |  | CONN USB MICRO B RECPT SMT R/A | A MLG-078457 |  | 1 | ea |  |  | J1 |  | Prototype | PURCHASED | FMCAPP | Part | CON-00001148-000 | A |  |  |  |  |  |  |  |  |  |  |  | 0 |  |  |  | FCI | 10118193-0001LF | Active | M16110 | Active | // |  | Yes |  | Tape and Reel TR
2 | 335-FMC-DIO-00001149-000 | Part | TVS DIODE 16VWM 26VC SMB | A MLG-078457 | Prototype |  | FORD MOTOR COMPANY |  | 11/18/2014 03:37:51 PM PST |  | No |  |  | No |  |  |  | 40 |  | TVS DIODE 16VWM 26VC SMB | A MLG-078457 |  | 1 | ea |  |  | D3 |  | Prototype | PURCHASED | FMCAPP | Part | DIO-00001149-000 | A |  |  |  |  |  |  |  |  |  |  |  | 0 |  |  |  | ON SEMICONDUCTOR | 1SMB16CAT3G | Active | M43960 | Active | // |  | Yes |  | Tape and Reel TR
2 | 335-FMC-CON-00001150-000 | Part | CONN HEADER 3MM 2POS R/A TIN | A MLG-078457 | Prototype |  | FORD MOTOR COMPANY |  | 11/18/2014 03:37:51 PM PST |  | No |  |  | No |  |  |  | 50 |  | CONN HEADER 3MM 2POS R/A TIN | A MLG-078457 |  | 1 | ea |  |  | J4 |  | Prototype | PURCHASED | FMCAPP | Part | CON-00001150-000 | A |  |  |  |  |  |  |  |  |  |  |  | 0 |  |  |  | TE CONNECTIVITY | 2-1445055-2 | Active | MB4588 | Active | // |  | Yes |  | Bulk BLK
2 | 335-FMC-RES-00001151-000 | Part | RES 49.9K OHM 1/16W 1% 0603 | A MLG-078457 | Prototype |  | FORD MOTOR COMPANY |  | 11/18/2014 03:37:51 PM PST |  | No |  |  | No |  |  |  | 60 |  | RES 49.9K OHM 1/16W 1% 0603 | A MLG-078457 |  | 1 | ea |  |  | R18 |  | Prototype | PURCHASED | FMCC1P | Part | RES-00001151-000 | A |  |  |  |  |  |  |  |  |  |  |  | 0 |  |  |  | TE CONNECTIVITY | 2-1879338-7 | Active | MB4588 | Active | // |  | Yes |  | Tape and Reel TR
2 | 335-FMC-RES-00001152-000 | Part | RES 4.7K OHM 1/16W 0.05% 0603 | A MLG-078887 | Prototype |  | FORD MOTOR COMPANY |  | 11/26/2014 05:18:13 PM PST |  | No |  |  | No |  |  |  | 70 |  | RES 4.7K OHM 1/16W 0.05% 0603 | A MLG-078887 |  | 1 | ea |  |  | R15 |  | Prototype | PURCHASED | FMCC1P | Part | RES-00001152-000 | A |  |  |  |  |  |  |  |  |  |  |  | 0 |  |  |  | TE CONNECTIVITY | 5-1879192-0 | Active | MB4588 | Active | // |  | Yes |  | Tape and Reel TR
 |  |  |  |  |  |  |  |  |  |  |  |  |  |  |  |  |  |  |  |  |  |  |  |  |  |  |  |  |  |  |  |  |  |  |  |  |  |  |  |  |  |  |  |  |  |  |  |  |  | PANASONIC | ERA3ARW472V | Active | M12880 | Active | //,0.1W |  | Yes |  | Tape and Reel TR
2 | 335-FMC-IND-00001153-000 | Part | FERRITE BEAD 220 OHM .5A 0603 | A FNP-049952 | Prototype |  | FORD MOTOR COMPANY |  | 11/10/2014 05:00:52 PM PST | 11/10/2014 12:00:00 AM PST | No |  |  | No |  |  |  | 80 |  | FERRITE BEAD 220 OHM .5A 0603 | A FNP-049952 | 11/10/2014 12:00:00 AM PST | 1 | ea |  |  | FB1 |  | Prototype | PURCHASED | FMCAPP | Part | IND-00001153-000 | A |  |  |  |  |  |  |  |  |  |  |  | 0 |  |  |  | WURTH | 710-74279263 | Active | MB1918 | Active
2 | 335-FMC-RES-00001154-000 | Part | RES 1.5K OHM 1/16W 1% 0603 | A FNP-050623 | Prototype |  | FORD MOTOR COMPANY |  | 12/05/2014 05:49:17 PM PST |  | No |  |  | No |  |  |  | 90 |  | RES 1.5K OHM 1/16W 1% 0603 | A FNP-050623 |  | 1 | ea |  |  | R8 |  | Prototype | PURCHASED | FMCC1P | Part | RES-00001154-000 | A |  |  |  |  |  |  |  |  |  |  |  | 0 |  |  |  | TE CONNECTIVITY | 7-1879336-9 | Active | MB4588 | Active | // |  | Yes |  | Tape and Reel TR
 |  |  |  |  |  |  |  |  |  |  |  |  |  |  |  |  |  |  |  |  |  |  |  |  |  |  |  |  |  |  |  |  |  |  |  |  |  |  |  |  |  |  |  |  |  |  |  |  |  | SAMSUNG ELECTRONICS | RC1608F152CS | Active | M27960 | Active
2 | 335-FMC-CON-00001156-000 | Part | CONN,BERGSTIK II 0.100 DUAL | A MLG-078457 | Prototype |  | FORD MOTOR COMPANY |  | 11/18/2014 03:37:51 PM PST |  | No |  |  | No |  |  |  | 110 |  | CONN,BERGSTIK II 0.100 DUAL | A MLG-078457 |  | 1 | ea |  |  | JP2 |  | Prototype | PURCHASED | FMCAPP | Part | CON-00001156-000 | A |  |  |  |  |  |  |  |  |  |  |  | 0 |  |  |  | FCI | 93287-202HLF | Active | M16110 | Active | //,OBS |  | Yes |  | Bulk BLK
2 | 335-FMC-XTR-00001157-000 | Part | TRANS PNP 65V 100MA SOT23 | A MLG-078457 | Prototype |  | FORD MOTOR COMPANY |  | 11/18/2014 03:37:51 PM PST |  | No |  |  | No |  |  |  | 120 |  | TRANS PNP 65V 100MA SOT23 | A MLG-078457 |  | 1 | ea |  |  | Q1 |  | Prototype | PURCHASED | FMCAPP | Part | XTR-00001157-000 | A |  |  |  |  |  |  |  |  |  |  |  | 0 |  |  |  | ON SEMICONDUCTOR | BC856ALT1G | Active | M43960 | Active | // |  | Yes |  | Tape and Reel TR
2 | 335-FMC-CAP-00001158-000 | Part | CAP CER 0.1UF 16V 5% X7R 0603 | A MLG-078457 | Prototype |  | FORD MOTOR COMPANY |  | 11/18/2014 03:37:51 PM PST |  | No |  |  | No |  |  |  | 130 |  | CAP CER 0.1UF 16V 5% X7R 0603 | A MLG-078457 |  | 10 | ea |  |  | C6,C10,C15,C16,C17,C18,C19,C20,C21,C23 |  | Prototype | PURCHASED | FMCC1P | Part | CAP-00001158-000 | A |  |  |  |  |  |  |  |  |  |  |  | 0 |  |  |  | KEMET ELECTRONICS | C0603C104J4RACTU | Active | M04220 | Active | // |  | Yes |  | Tape and Reel TR
2 | 335-FMC-CAP-00001159-000 | Part | CAP CER 18PF 50V 5% C0G 0603 | A MLG-078457 | Prototype |  | FORD MOTOR COMPANY |  | 11/18/2014 03:37:51 PM PST |  | No |  |  | No |  |  |  | 140 |  | CAP CER 18PF 50V 5% C0G 0603 | A MLG-078457 |  | 4 | ea |  |  | C24,C25,C26,C28 |  | Prototype | PURCHASED | FMCC1P | Part | CAP-00001159-000 | A |  |  |  |  |  |  |  |  |  |  |  | 0 |  |  |  | SAMSUNG ELECTRONICS | CL10C180JB8NNNC | Active | M27960 | Active | // |  | Yes |  | Tape and Reel TR
 |  |  |  |  |  |  |  |  |  |  |  |  |  |  |  |  |  |  |  |  |  |  |  |  |  |  |  |  |  |  |  |  |  |  |  |  |  |  |  |  |  |  |  |  |  |  |  |  |  | KEMET ELECTRONICS | C0603C180J5GACTU | Active | M04220 | Active | // |  | Yes |  | Tape and Reel TR
 |  |  |  |  |  |  |  |  |  |  |  |  |  |  |  |  |  |  |  |  |  |  |  |  |  |  |  |  |  |  |  |  |  |  |  |  |  |  |  |  |  |  |  |  |  |  |  |  |  | TDK | CGA3E2C0G1H180J080AA | Active | M25801 | Active | // |  | Yes |  | Tape and Reel TR
2 | 335-FMC-CAP-00000925-000 | Part | CAP CER 0.1UF 50V 10% X7R 0805 | A MLG-078457 | Prototype |  | FORD MOTOR COMPANY |  | 11/18/2014 03:37:51 PM PST |  | No |  |  | No |  |  |  | 150 |  | CAP CER 0.1UF 50V 10% X7R 0805 | A MLG-078457 |  | 4 | ea |  |  | C1,C5,C8,C13 |  | Prototype | PURCHASED | FMCC1P | Part | CAP-00000925-000 | A |  |  |  |  |  |  |  |  |  |  |  | 0 |  |  |  | KEMET ELECTRONICS | C0805C104K5RACAUTO | Active | M04220 | Active | // |  | Yes |  | Tape and Reel TR
2 | 335-FMC-CAP-00001160-000 | Part | CAP CER 10UF 10V 10% X5R 0805 | A MLG-078457 | Prototype |  | FORD MOTOR COMPANY |  | 11/18/2014 03:37:51 PM PST |  | No |  |  | No |  |  |  | 160 |  | CAP CER 10UF 10V 10% X5R 0805 | A MLG-078457 |  | 1 | ea |  |  | C14 |  | Prototype | PURCHASED | FMCC1P | Part | CAP-00001160-000 | A |  |  |  |  |  |  |  |  |  |  |  | 0 |  |  |  | KEMET ELECTRONICS | C0805C106K8PACTU | Active | M04220 | Active | // |  | Yes |  | Tape and Reel TR
2 | 335-FMC-CAP-00001161-000 | Part | CAP CER 0.47UF 50V 10% X7R 0805 | A MLG-078457 | Prototype |  | FORD MOTOR COMPANY |  | 11/18/2014 03:37:51 PM PST |  | No |  |  | No |  |  |  | 170 |  | CAP CER 0.47UF 50V 10% X7R 0805 | A MLG-078457 |  | 2 | ea |  |  | C7,C12 |  | Prototype | PURCHASED | FMCC1P | Part | CAP-00001161-000 | A |  |  |  |  |  |  |  |  |  |  |  | 0 |  |  |  | KEMET ELECTRONICS | C0805C474K5RACTU | Active | M04220 | Active | // |  | Yes |  | Tape and Reel TR
2 | 335-FMC-CAP-00000528-001 | Part | CAP CER 100PF 50V 5% NP0 0603 | A MLG-078457 | Prototype |  | FORD MOTOR COMPANY |  | 11/18/2014 03:37:51 PM PST |  | No |  |  | No |  |  |  | 180 |  | CAP CER 100PF 50V 5% NP0 0603 | A MLG-078457 |  | 6 | ea |  |  | C29,C30,C31,C32,C33,C34 |  | Prototype | PURCHASED | FMCC1P | Part | CAP-00000528-001 | A |  |  |  |  |  |  |  |  |  |  |  | 0 |  |  |  | MURATA MANUFACTURING | GRM1885C1H101JA01D | Active | M17400 | Active | // |  | Yes |  | Tape and Reel TR
 |  |  |  |  |  |  |  |  |  |  |  |  |  |  |  |  |  |  |  |  |  |  |  |  |  |  |  |  |  |  |  |  |  |  |  |  |  |  |  |  |  |  |  |  |  |  |  |  |  | TDK | C1608C0G1H101J080AA | Active | M25801 | Active | // |  | Yes |  | Tape and Reel TR
 |  |  |  |  |  |  |  |  |  |  |  |  |  |  |  |  |  |  |  |  |  |  |  |  |  |  |  |  |  |  |  |  |  |  |  |  |  |  |  |  |  |  |  |  |  |  |  |  |  | KEMET ELECTRONICS | C0603C101J5GACTU | Active | M04220 | Active | // |  | Yes |  | Tape and Reel TR
2 | 335-FMC-CAP-00001162-000 | Part | CAP CER 0.022UF 50V 10% X7R 0603 | A MLG-078457 | Prototype |  | FORD MOTOR COMPANY |  | 11/18/2014 03:37:51 PM PST |  | No |  |  | No |  |  |  | 190 |  | CAP CER 0.022UF 50V 10% X7R 0603 | A MLG-078457 |  | 2 | ea |  |  | C4,C11 |  | Prototype | PURCHASED | FMCC1P | Part | CAP-00001162-000 | A |  |  |  |  |  |  |  |  |  |  |  | 0 |  |  |  | SAMSUNG ELECTRONICS | CL10B223KB8SFNC | Active | M27960 | Active | // |  | Yes |  | Tape and Reel TR
2 | 335-FMC-XTL-00001163-000 | Part | CRYSTAL 12KHZ 8PF SMD | A FNP-049952 | Prototype |  | FORD MOTOR COMPANY |  | 11/10/2014 05:00:52 PM PST | 11/10/2014 12:00:00 AM PST | No |  |  | No |  |  |  | 200 |  | CRYSTAL 12KHZ 8PF SMD | A FNP-049952 | 11/10/2014 12:00:00 AM PST | 1 | ea |  |  | Q3 |  | Prototype | PURCHASED | FMCAPP | Part | XTL-00001163-000 | A |  |  |  |  |  |  |  |  |  |  |  | 0 |  |  |  | AVX/KYOCERA | CX3225SB12000D0FLJZZ | Active | M01800 | Active
2 | 335-FMC-CAP-00000928-000 | Part | CAP,ALUM,150UF,10V,20%,RADIAL | A MLG-078457 | Prototype |  | FORD MOTOR COMPANY |  | 11/18/2014 03:37:51 PM PST |  | No |  |  | No |  |  |  | 210 |  | CAP,ALUM,150UF,10V,20%,RADIAL | A MLG-078457 |  | 1 | ea |  |  | C2 |  | Prototype | PURCHASED | FMCC1P | Part | CAP-00000928-000 | A |  |  |  |  |  |  |  |  |  |  |  | 0 |  |  |  | PANASONIC | EEUFR1A151B | Active | M12880 | Active | // |  | Yes |  | Ammo AMP
2 | 335-FMC-CAP-00000932-000 | Part | CAP,ALUM,270UF,35V,20%,RADIAL | A FNP-049952 | Prototype |  | FORD MOTOR COMPANY |  | 11/10/2014 05:00:52 PM PST | 11/10/2014 12:00:00 AM PST | No |  |  | No |  |  |  | 220 |  | CAP,ALUM,270UF,35V,20%,RADIAL | A FNP-049952 | 11/10/2014 12:00:00 AM PST | 1 | ea |  |  | C3 |  | Prototype | PURCHASED | FMCC1P | Part | CAP-00000932-000 | A |  |  |  |  |  |  |  |  |  |  |  | 0 |  |  |  | PANASONIC | EEU-FR1V271 | Active | M12880 | Active
2 | 335-FMC-DIO-00001164-000 | Part | TVS DIODE 3.3VWM 7.8VC SOT1123 | A MLG-078457 | Prototype |  | FORD MOTOR COMPANY |  | 11/18/2014 03:37:51 PM PST |  | No |  |  | No |  |  |  | 230 |  | TVS DIODE 3.3VWM 7.8VC SOT1123 | A MLG-078457 |  | 3 | ea |  |  | D8,D9,D10 |  | Prototype | PURCHASED | FMCAPP | Part | DIO-00001164-000 | A |  |  |  |  |  |  |  |  |  |  |  | 0 |  |  |  | ON SEMICONDUCTOR | ESD11A3.3DT5G | Active | M43960 | Active | // |  | Yes |  | Tape and Reel TR
2 | 335-FMC-CAP-00001165-000 | Part | CAP CER 47UF 10V 10% X7R 1210 | A MLG-078457 | Prototype |  | FORD MOTOR COMPANY |  | 11/18/2014 03:37:51 PM PST |  | No |  |  | No |  |  |  | 240 |  | CAP CER 47UF 10V 10% X7R 1210 | A MLG-078457 |  | 1 | ea |  |  | C9 |  | Prototype | PURCHASED | FMCC1P | Part | CAP-00001165-000 | A |  |  |  |  |  |  |  |  |  |  |  | 0 |  |  |  | MURATA MANUFACTURING | GRM32ER71A476KE15L | Active | M17400 | Active | // |  | Yes |  | Tape and Reel TR
2 | 335-FMC-CON-00001166-000 | Part | CONN HEADER .050 10PS DL SMD AU | A FNP-050761 | Prototype |  | FORD MOTOR COMPANY |  | 12/11/2014 02:30:48 PM PST |  | No |  |  | No |  |  |  | 250 |  | CONN HEADER .050 10PS DL SMD AU | A FNP-050761 |  | 1 | ea |  |  | J5 |  | Prototype | PURCHASED | FMCAPP | Part | CON-00001166-000 | A |  |  |  |  |  |  |  |  |  |  |  | 0 |  |  |  | SULLINS CONNECTOR SOLUTIONS | GRPB052VWQS-M81RC | Active | MB8254 | Active | //,M81=TR |  | Yes |  | Tape and Reel TR
 |  |  |  |  |  |  |  |  |  |  |  |  |  |  |  |  |  |  |  |  |  |  |  |  |  |  |  |  |  |  |  |  |  |  |  |  |  |  |  |  |  |  |  |  |  |  |  |  |  | SAMTEC | FTS-105-01-L-DV-P-TR | Active | M05290 | Active | // |  | Yes |  | Tape and Reel TR
2 | 335-FMC-ICS-00001167-000 | Part | IC MCU ARM 512KB FLASH 100LQFP | A MLG-078457 | Prototype |  | FORD MOTOR COMPANY |  | 11/18/2014 03:37:51 PM PST |  | No |  |  | No |  |  |  | 260 |  | IC MCU ARM 512KB FLASH 100LQFP | A MLG-078457 |  | 1 | ea |  |  | IC5 |  | Prototype | PURCHASED | FMCAPP | Part | ICS-00001167-000 | A |  |  |  |  |  |  |  |  |  |  |  | 0 |  |  |  | NXP SEMICONDUCTORS | LPC1769FBD100,551 | Active | MA8673 | Active | // |  | Yes |  | Tape and Reel TR
2 | 335-FMC-ELC-00001168-000 | Part | FUSE,PTC RESETTABLE 1.10A 16V 1812 | A MLG-078457 | Prototype |  | FORD MOTOR COMPANY |  | 11/18/2014 03:37:51 PM PST |  | No |  |  | No |  |  |  | 270 |  | FUSE,PTC RESETTABLE 1.10A 16V 1812 | A MLG-078457 |  | 1 | ea |  |  | F1 |  | Prototype | PURCHASED | FMCAPP | Part | ELC-00001168-000 | A |  |  |  |  |  |  |  |  |  |  |  | 0 |  |  |  | BOURNS | MF-MSMF110/16-2 | Active | M02090 | Active | // |  | Yes |  | Tape and Reel TR
2 | 335-FMC-DIO-00001169-000 | Part | TVS DIODE 12VWM 35VC SOD882D | A MLG-078457 | Prototype |  | FORD MOTOR COMPANY |  | 11/18/2014 03:37:51 PM PST |  | No |  |  | No |  |  |  | 280 |  | TVS DIODE 12VWM 35VC SOD882D | A MLG-078457 |  | 1 | ea |  |  | D2 |  | Prototype | PURCHASED | FMCAPP | Part | DIO-00001169-000 | A |  |  |  |  |  |  |  |  |  |  |  | 0 |  |  |  | NXP SEMICONDUCTORS | PESD12VS1ULD,315 | Active | MA8673 | Active | // |  | Yes |  | Tape and Reel TR
2 | 335-FMC-DIO-00001170-000 | Part | TVS DIODE 24VWM 70VC SOT23 | A MLG-078457 | Prototype |  | FORD MOTOR COMPANY |  | 11/18/2014 03:37:51 PM PST |  | No |  |  | No |  |  |  | 290 |  | TVS DIODE 24VWM 70VC SOT23 | A MLG-078457 |  | 2 | ea |  |  | D4,D5 |  | Prototype | PURCHASED | FMCAPP | Part | DIO-00001170-000 | A |  |  |  |  |  |  |  |  |  |  |  | 0 |  |  |  | NXP SEMICONDUCTORS | PESD1CAN,215 | Active | MA8673 | Active | // |  | Yes |  | Tape and Reel TR
2 | 335-FMC-DIO-00000029-000 | Part | TVS DIODE 5VWM SOD882 | B FNP-050325 | Prototype |  | FORD MOTOR COMPANY |  | 11/24/2014 04:17:41 PM PST |  | No |  |  | No |  |  |  | 300 |  | TVS DIODE 5VWM SOD882 | B FNP-050325 |  | 2 | ea |  |  | D6,D7 |  | Prototype | PURCHASED | FMCAPP | Part | DIO-00000029-000 | B |  |  |  |  |  |  |  |  |  |  |  | 0 |  |  |  | NXP SEMICONDUCTORS | PESD5V0X1BL,315 | Active | MA8673 | Active | // |  | Yes |  | Tape and Reel TR
 |  |  |  |  |  |  |  |  |  |  |  |  |  |  |  |  |  |  |  |  |  |  |  |  |  |  |  |  |  |  |  |  |  |  |  |  |  |  |  |  |  |  |  |  |  |  |  |  |  | NXP SEMICONDUCTORS | PESD5V0X1BL | Inactive | MA8673 | Active | TR version PESD5V0X1BL,315
2 | 335-FMC-RES-00001171-000 | Part | RES 30 OHM 1/10W 5% 0603 SMD | A MLG-078457 | Prototype |  | FORD MOTOR COMPANY |  | 11/18/2014 03:37:51 PM PST |  | No |  |  | No |  |  |  | 310 |  | RES 30 OHM 1/10W 5% 0603 SMD | A MLG-078457 |  | 2 | ea |  |  | R6,R21 |  | Prototype | PURCHASED | FMCC1P | Part | RES-00001171-000 | A |  |  |  |  |  |  |  |  |  |  |  | 0 |  |  |  | KOA SPEER ELECTRONICS | RK73B1JTTD300J | Active | M04273 | Active | // |  | Yes |  | Tape and Reel TR
2 | 335-FMC-RES-00001172-000 | Part | RES 120 OHM 1/16W 1% 0603 | A MLG-078457 | Prototype |  | FORD MOTOR COMPANY |  | 11/18/2014 03:37:51 PM PST |  | No |  |  | No |  |  |  | 320 |  | RES 120 OHM 1/16W 1% 0603 | A MLG-078457 |  | 3 | ea |  |  | R1,R2,R25 |  | Prototype | PURCHASED | FMCC1P | Part | RES-00001172-000 | A |  |  |  |  |  |  |  |  |  |  |  | 0 |  |  |  | KOA SPEER ELECTRONICS | RK73H1JTTD1200F | Active | M04273 | Active | //,0.1W |  | Yes |  | Tape and Reel TR
2 | 335-FMC-RES-00001173-000 | Part | RES 143 OHM 1/16W 1% 0603 | A MLG-078457 | Prototype |  | FORD MOTOR COMPANY |  | 11/18/2014 03:37:51 PM PST |  | No |  |  | No |  |  |  | 330 |  | RES 143 OHM 1/16W 1% 0603 | A MLG-078457 |  | 2 | ea |  |  | R5,R20 |  | Prototype | PURCHASED | FMCC1P | Part | RES-00001173-000 | A |  |  |  |  |  |  |  |  |  |  |  | 0 |  |  |  | KOA SPEER ELECTRONICS | RK73H1JTTD1430F | Active | M04273 | Active | //,0.1W |  | Yes |  | Tape and Reel TR
2 | 335-FMC-RES-00001174-000 | Part | RES 17.4 OHM 1/16W 1% 0603 | A MLG-078457 | Prototype |  | FORD MOTOR COMPANY |  | 11/18/2014 03:37:51 PM PST |  | No |  |  | No |  |  |  | 340 |  | RES 17.4 OHM 1/16W 1% 0603 | A MLG-078457 |  | 2 | ea |  |  | R4,R22 |  | Prototype | PURCHASED | FMCC1P | Part | RES-00001174-000 | A |  |  |  |  |  |  |  |  |  |  |  | 0 |  |  |  | KOA SPEER ELECTRONICS | RK73H1JTTD17R4F | Active | M04273 | Active | //,0.1W |  | Yes |  | Tape and Reel TR
2 | 335-FMC-RES-00001175-000 | Part | RES 560 OHM 1/16W 1% 0603 | A MLG-078457 | Prototype |  | FORD MOTOR COMPANY |  | 11/18/2014 03:37:51 PM PST |  | No |  |  | No |  |  |  | 350 |  | RES 560 OHM 1/16W 1% 0603 | A MLG-078457 |  | 2 | ea |  |  | R11,R19 |  | Prototype | PURCHASED | FMCC1P | Part | RES-00001175-000 | A |  |  |  |  |  |  |  |  |  |  |  | 0 |  |  |  | KOA SPEER ELECTRONICS | RK73H1JTTD5600F | Active | M04273 | Active | //,0.1W |  | Yes |  | Tape and Reel TR
2 | 335-FMC-ELC-00001176-000 | Part | MODULE BLUETOOTH W/ANT CLASS1 | A FNP-050406 | Prototype |  | FORD MOTOR COMPANY |  | 11/26/2014 04:13:38 PM PST |  | No |  |  | No |  |  |  | 360 |  | MODULE BLUETOOTH W/ANT CLASS1 | A FNP-050406 |  | 1 | ea |  |  | IC6 |  | Prototype | PURCHASED | FMCAPP | Part | ELC-00001176-000 | A |  |  |  |  |  |  |  |  |  |  |  | 0 |  |  |  | MICROCHIP TECHNOLOGY | RN41-I/RM | Active | M04980 | Active | // |  | Yes |  | Bulk BLK
2 | 335-FMC-RES-00001177-000 | Part | RES 10K OHM 1/16W 1% 0603 | A MLG-078457 | Prototype |  | FORD MOTOR COMPANY |  | 11/18/2014 03:37:51 PM PST |  | No |  |  | No |  |  |  | 370 |  | RES 10K OHM 1/16W 1% 0603 | A MLG-078457 |  | 8 | ea |  |  | R3,R12,R13,R14,R16,R17,R23,R24 |  | Prototype | PURCHASED | FMCC1P | Part | RES-00001177-000 | A |  |  |  |  |  |  |  |  |  |  |  | 0 |  |  |  | PANASONIC | ERJ-3EKF1002V | Active | M12880 | Active
 |  |  |  |  |  |  |  |  |  |  |  |  |  |  |  |  |  |  |  |  |  |  |  |  |  |  |  |  |  |  |  |  |  |  |  |  |  |  |  |  |  |  |  |  |  |  |  |  |  | SEI ELECTRONICS | RNCF0603FKE10K0 | Active | M18120 | Active | // |  | Yes |  | Tape and Reel TR
2 | 335-FMC-RES-00001178-000 | Part | RES 2.0K OHM 1/16W .5% 0603 SMD | A MLG-078457 | Prototype |  | FORD MOTOR COMPANY |  | 11/18/2014 03:37:51 PM PST |  | No |  |  | No |  |  |  | 380 |  | RES 2.0K OHM 1/16W .5% 0603 SMD | A MLG-078457 |  | 1 | ea |  |  | R9 |  | Prototype | PURCHASED | FMCC1P | Part | RES-00001178-000 | A |  |  |  |  |  |  |  |  |  |  |  | 0 |  |  |  | SUSUMU | RR0816P-202-D | Active | M07204 | Active | // |  | Yes |  | Tape and Reel TR
2 | 335-FMC-ELC-00000526-001 | Part | SWITCH TACTILE SPST-NO 0.05A 12V | A FNP-049952 | Prototype |  | FORD MOTOR COMPANY |  | 11/10/2014 05:00:52 PM PST | 11/10/2014 12:00:00 AM PST | No |  |  | No |  |  |  | 390 |  | SWITCH TACTILE SPST-NO 0.05A 12V | A FNP-049952 | 11/10/2014 12:00:00 AM PST | 2 | ea |  |  | S1,S2 |  | Prototype | PURCHASED | FMCAPP | Part | ELC-00000526-001 | A |  |  |  |  |  |  |  |  |  |  |  | 0 |  |  |  | C & K COMPONENTS | RS-032G05A3-SM RT | Active | M02190 | Active
2 | 335-FMC-DIO-00000938-000 | Part | DIODE,SWITCHING,600V,1A,250NS,30 AMP IFSM | A MLG-078457 | Prototype |  | FORD MOTOR COMPANY |  | 11/18/2014 03:37:51 PM PST |  | No |  |  | No |  |  |  | 400 |  | DIODE,SWITCHING,600V,1A,250NS,30 AMP IFSM | A MLG-078457 |  | 1 | ea |  |  | D1 |  | Prototype | PURCHASED | FMCC2P | Part | DIO-00000938-000 | A |  |  |  |  |  |  |  |  |  |  |  | 0 |  |  |  | VISHAY | RS1J-E3/5AT | Active | M20930 | Active | // |  | Yes |  | Tape and Reel TR
2 | 335-FMC-DIO-00001179-000 | Part | LED 660NM SUPER RED DIFF 0603SMD | A MLG-078457 | Prototype |  | FORD MOTOR COMPANY |  | 11/18/2014 03:37:51 PM PST |  | No |  |  | No |  |  |  | 410 |  | LED 660NM SUPER RED DIFF 0603SMD | A MLG-078457 |  | 2 | ea |  |  | LED2,LED3 |  | Prototype | PURCHASED | FMCC2P | Part | DIO-00001179-000 | A |  |  |  |  |  |  |  |  |  |  |  | 0 |  |  |  | LUMEX | SML-LX0603SRW-TR | Active | M04560 | Active | // |  | Yes |  | Tape and Reel TR
2 | 335-FMC-XTL-00000186-002 | Part | CRYSTAL 32.768KHZ 12.5PF SMD | A FNP-050570 | Prototype |  | FORD MOTOR COMPANY |  | 12/04/2014 05:19:27 PM PST |  | No |  |  | No |  |  |  | 420 |  | CRYSTAL 32.768KHZ 12.5PF SMD | A FNP-050570 |  | 1 | ea |  |  | Q2 |  | Prototype | PURCHASED | FMCAPP | Part | XTL-00000186-002 | A |  |  |  |  |  |  |  |  |  |  |  | 0 |  |  |  | AVX/KYOCERA | ST2012SB32768H5HPWAA | Active | M01800 | Active | // |  | Yes |  | Tape and Reel TR
2 | 335-FMC-ICS-00001180-000 | Part | IC CAN TXRX HI-SPEED 14SO | A MLG-078457 | Prototype |  | FORD MOTOR COMPANY |  | 11/18/2014 03:37:51 PM PST |  | No |  |  | No |  |  |  | 430 |  | IC CAN TXRX HI-SPEED 14SO | A MLG-078457 |  | 1 | ea |  |  | IC3 |  | Prototype | PURCHASED | FMCAPP | Part | ICS-00001180-000 | A |  |  |  |  |  |  |  |  |  |  |  | 0 |  |  |  | NXP SEMICONDUCTORS | TJA1048T,118 | Active | MA8673 | Active | // |  | Yes |  | Tape and Reel TR
2 | 335-FMC-ICS-00001181-000 | Part | IC REG LDO 3.3V 1A TO252-3 | A FNP-049952 | Prototype |  | FORD MOTOR COMPANY |  | 11/10/2014 05:00:52 PM PST | 11/10/2014 12:00:00 AM PST | No |  |  | No |  |  |  | 440 |  | IC REG LDO 3.3V 1A TO252-3 | A FNP-049952 | 11/10/2014 12:00:00 AM PST | 1 | ea |  |  | IC2 |  | Prototype | PURCHASED | FMCAPP | Part | ICS-00001181-000 | A |  |  |  |  |  |  |  |  |  |  |  | 0 |  |  |  | INFINEON TECHNOLOGIES | TLE4284D V33 | Active | M35960 | Active
2 | 335-FMC-ICS-00001182-000 | Part | IC REG LDO 5V 1A TO252-3 | A FNP-049952 | Prototype |  | FORD MOTOR COMPANY |  | 11/10/2014 05:00:52 PM PST | 11/10/2014 12:00:00 AM PST | No |  |  | No |  |  |  | 450 |  | IC REG LDO 5V 1A TO252-3 | A FNP-049952 | 11/10/2014 12:00:00 AM PST | 1 | ea |  |  | IC1 |  | Prototype | PURCHASED | FMCAPP | Part | ICS-00001182-000 | A |  |  |  |  |  |  |  |  |  |  |  | 0 |  |  |  | INFINEON TECHNOLOGIES | TLE4284D V50 | Active | M35960 | Active
2 | 335-FMC-ICS-00001183-000 | Part | IC CTRLR HOT SWAP 3-20V 8SOPWR | A MLG-078457 | Prototype |  | FORD MOTOR COMPANY |  | 11/18/2014 03:37:51 PM PST |  | No |  |  | No |  |  |  | 460 |  | IC CTRLR HOT SWAP 3-20V 8SOPWR | A MLG-078457 |  | 1 | ea |  |  | IC7 |  | Prototype | PURCHASED | FMCAPP | Part | ICS-00001183-000 | A |  |  |  |  |  |  |  |  |  |  |  | 0 |  |  |  | TEXAS INSTRUMENTS | TPS2421-2DDAR | Active | M21880 | Active | // |  | Yes |  | Tape and Reel TR
2 | 335-FMC-DIO-00001184-000 | Part | LED 5MM RGB 640/515/461NM CLR TH | A MLG-079405 | Prototype |  | FORD MOTOR COMPANY |  | 12/10/2014 05:19:25 PM PST |  | No |  |  | No |  |  |  | 470 |  | LED 5MM RGB 640/515/461NM CLR TH | A MLG-079405 |  | 2 | ea |  |  | LED1,LED4 |  | Prototype | PURCHASED | FMCC2P | Part | DIO-00001184-000 | A |  |  |  |  |  |  |  |  |  |  |  | 0 |  |  |  | KINGBRIGHT | WP154A4SUREQBFZGC | Active | M12140 | Active | // |  | Yes |  | Bulk BLK
2 | 335-FMC-ELC-00001185-000 | Part | M08X2-OBDII-COMTECH - TBD | A FNP-049952 | Prototype |  | FORD MOTOR COMPANY |  | 11/10/2014 05:00:52 PM PST | 11/10/2014 12:00:00 AM PST | No |  |  | No |  |  |  | 480 |  | M08X2-OBDII-COMTECH - TBD | A FNP-049952 | 11/10/2014 12:00:00 AM PST | 1 | ea |  |  | J2 |  | Prototype | PURCHASED | FMCAPP | Part | ELC-00001185-000 | A |  |  |  |  |  |  |  |  |  |  |  | 0 |  |  |  | COMTECH COMMUNICATION | XK144220 | Active | MK4107 | Active
2 | 335-FMC-RES-00001319-000 | Part | RES 33 OHM 1/10W 5% 0603 SMD | A MLG-079479 | Prototype | RES,CHIP THICK FILM,0603 | FORD MOTOR COMPANY |  | 12/12/2014 10:45:15 AM PST |  | No |  |  | No |  |  |  | 490 |  | RES 33 OHM 1/10W 5% 0603 SMD | A MLG-079479 |  | 2 | ea |  |  | R7,R10 |  | Prototype | PURCHASED | FMCC1P | Part | RES-00001319-000 | 01 |  |  |  |  |  |  |  |  |  |  |  | 0 |  |  |  | ROHM SEMICONDUCTOR | MCR03ERTJ330 | Active | MJ7436 | Active | // |  | Yes |  | Tape and Reel TR
2 | 335-FMC-PCB-00001186-000 | Part | PCB,(FAB),FMC,DIAGNOSTICS | A FNP-049952 | Prototype |  | FORD MOTOR COMPANY |  | 11/10/2014 05:00:52 PM PST | 11/10/2014 12:00:00 AM PST | No |  |  | No |  |  |  | 500 |  | PCB,(FAB),FMC,DIAGNOSTICS | A FNP-049952 | 11/10/2014 12:00:00 AM PST | 1 | ea |  |  |  |  | Prototype | PURCHASED | FMCAPP | Part | PCB-00001186-000 | A |  |  |  |  |  |  |  |  |  |  |  | 0 |  |  |  | MULTEK | PCB-00001186-000 | Active | M40571 | Active
3 | 335-FMC-DWG-00001186-000-PCB | Document | DWG,PCB,(FAB),FMC,DIAGNOSTICS | X00 FNP-049952 | Prototype |  | FORD MOTOR COMPANY |  | 11/10/2014 05:00:52 PM PST | 11/10/2014 12:00:00 AM PST | Yes |  |  |  |  |  |  | 7771 |  | DWG,PCB,(FAB),FMC,DIAGNOSTICS | X00 FNP-049952 | 11/10/2014 12:00:00 AM PST | 0 |  |  |  |  | REFERENCE ONLY | Prototype |  |  | Document |  |  |  |  |  |  |  |  |  |  |  |  |  | 0
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

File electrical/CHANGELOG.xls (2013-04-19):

What | Where | Criteria | done | Notes
R0.1
Verify TH Cap orientation | Layout + Docs | Clear indication of Capacitor Orientation on PCB | Y
Verify Crystal Orientation | Layout + Docs | Clear indication of Crystal Orientation on PCB | Y
Move connectors away from OBD connector | Layout | Move connectors away by at least 100 mils. | Y | Had room for 150 mils
Fix Threshold on Voltage Monitor IC | BOM | Source Voltage monitor with threshold appropriate for LPC1769 (less than 3.3v) | Y | N/A - Voltage monitor / power sequencing is unnecessary, removed.
USB Micro | Layout + Docs | Update USB Connector to a USB Micro B connector | Y
LEDs Changed to TH on BOT | Layout + Docs | Change RGB LEDs to Through Hole part, on Bottom layer of PCB | Y
RGB LED has unbalanced color | BOM | Source an RGB LED with better intensity consistency (particularly on Green) | Y
Try to better distribute LEDS | Layout | Center LEDs on 1/4 points of the front panel for even distribution of light | Y
Individual LED Control | Schematic + Layout | try to split both RGB LEDs to different PWM channels | Y
ISP Pin Pulled up with jumper or switch | Schematic + Layout + BOM | Pull up ISP line with resistor, include switch or jumper to pull down | Y | 0.1" jumper added to place device in ISP mode
Better ISP Breakout | Schematic + Layout | For debug UART, include reset and ISP line for LPC1769 ISP | Y | ISP jumper must be set before use, DTR pin will auto-reset the LPC1768.
CAN Bus Impedance Control | Layout | Provide guard band on CAN lines, attempt to maintain correct signal impedance | Y | 120 ohm differential impedance acheived, but inconsistent ground pour underneath.
USB_CONNECT signal routing | Layout | Wrong pinout on USB_CONNECT signal, fix LPC1769 part within Eagle | Y
R15 Pullup Amt | Schematic + BOM | Increase R15 Pullup to 4.7k or less for JTAG consistency. | Y
Review Main Crystal Capacitance | BOM | Consider increasing capacitance on main crystal to 18pF per LPC1769 manual. | Y
100pF caps on CAN Lines | Schematic + Layout + BOM | Place 100pF caps between each CAN line and GND | Y
Add Guard tracks | Layout | Add a Guard to CAN, USB and UART lines (at least 0.5mm wide, gnded every 10mm) | Y | Able to sneak >=20mil guard track around ~75% of sensitive signals.
USB line length | Layout | Try to make USB lines of equal length | Y | Traces are within 10 mils
Accept 5v power via USB | Schematic + Layout | Verify regulator dropout voltage is low enough to chain 3.3V regulator on 5V regulator | Y | Possible after removing 3.3v input diode (voltage drop too great).
Leave an LED on when Bluetooth Connected | Layout | Flip the LED polarity to remain ON when bluetooth connection is active | Y
Add button to enter USB bootloader mode | Schematic + Layout | This will bring total button count to 2 - one for reset, one for bootloader | Y | PROG button added to P2.12
Indicate JTAG connector orientation | Layout + Docs | An indication of which side the little notch goes | Y
Add a CAN BUS selection jumper | Schematic + Layout | Add ability to toggle channel B between Diagnostic Med and Multimedia busses | Y | Solder jumpers located on bottom of PCB.
Hardware flow control | Schematic + Layout | Add signals UARTRTS and UARTCTS between RN41 and LPC1769 | Y
IC7 ground pad is too large | Layout | Keep ground pad of IC7 away from leads to avoid shorting | Y | Culprit was an enlarged Stop mask around ground pad.
LPC Include part # in sch | Schematic | Improve schematic labeling/documentation | Y
IC7 Include part # in sch | Schematic | Improve schematic labeling/documentation | Y
Fix jumper part numbering | Schematic | Jumpers should use prefix JP, connectors prefix J | Y
IC3 update part # in sch | Schematic | Improve schematic labeling/documentation | Y
D4-D5 Include part # in sch | Schematic | Improve schematic labeling/documentation | Y
Change Pin 13 to NC | Schematic | Pin 13 should be left open RE: LPC1768 manual | Y
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

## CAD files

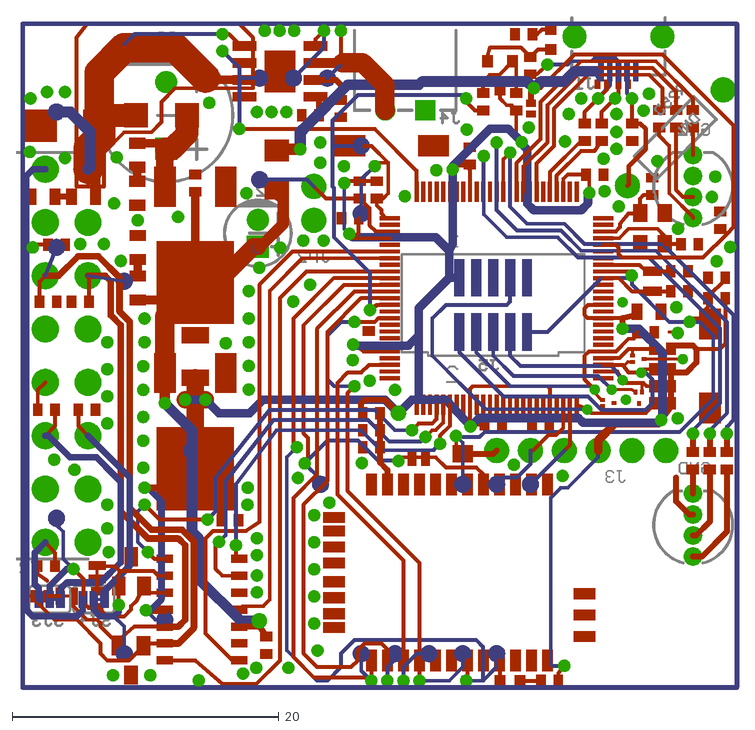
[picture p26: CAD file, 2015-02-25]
assembly/electrical/vehicle-interface.dxf
54.2 x 50.5

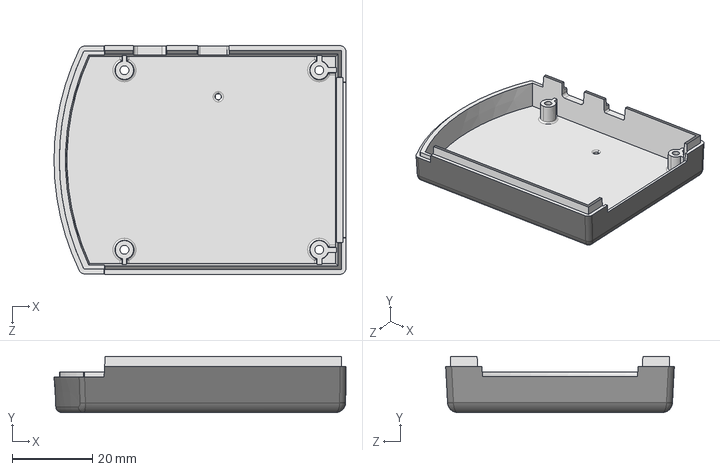
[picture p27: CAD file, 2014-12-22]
mechanical/VI_bottom.STEP
72.7 x 14.0 x 57.0 mm

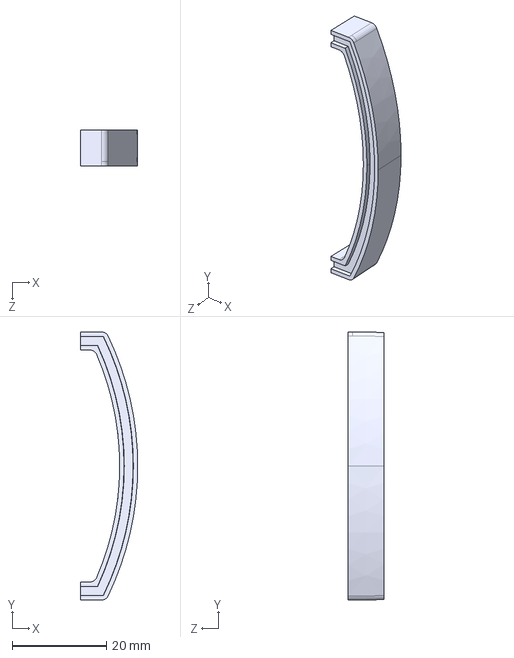
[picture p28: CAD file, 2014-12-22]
mechanical/VI_diffuser.STEP
12.2 x 56.8 x 7.62 mm

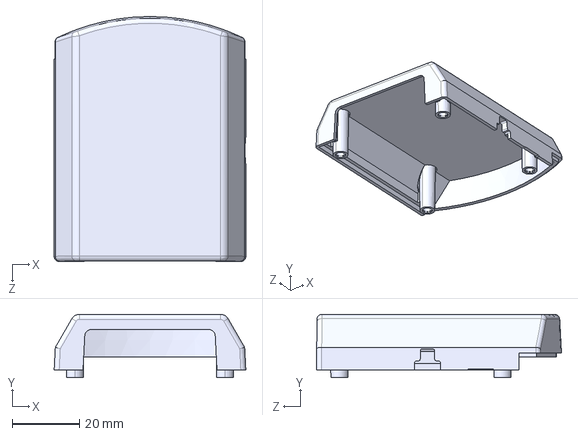
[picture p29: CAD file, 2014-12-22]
mechanical/VI_top.STEP
57.0 x 18.8 x 72.9 mm

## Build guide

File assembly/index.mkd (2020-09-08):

---
layout: assembly
title: Assembly Instructions
---

If you want to take this design into the physical world, the major components
you need to build are:

* Manufacture the PCB, e.g. with a company like [OSH Park](http://oshpark.com/)
* Manufacture the enclosure, e.g. with your own [3D
  printer](https://store.makerbot.com/3d-printers) (you may find one at your
  local [TechShop][]), a rapid prototyping shop like
  [Fathom](http://studiofathom.com/) or an injection molding service like
  [Protomold](http://www.protomold.com/).
* Assemble the components onto the PCB - there are surface mount components that
  will reuquire a reflow oven, so you can't hand solder this. Again, check out
  your local [TechShop][] (Note: currently all TechShops are close but look for similar shops such as [ProtoHaven][]) or a prototyping firm like [SF
  Circuits](http://www.sfcircuits.com/).

[TechShop]: https://en.wikipedia.org/wiki/TechShop

[ProtoHaven]: https://www.protohaven.org/

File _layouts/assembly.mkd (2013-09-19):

---
layout: default
section: assembly
---

<ul class="nav nav-tabs">
  <li><a href="/assembly/index.html">Assembly</a></li>
  <li><a href="/assembly/electrical/index.html">Electrical Fabrication Sources</a></li>
  <li><a href="/assembly/testing.html">Factory Testing</a></li>
</ul>

<div class="page-header">
    <h2>{{page.title}}</h2>
</div>

{{ content }}

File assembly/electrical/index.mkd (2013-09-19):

---
layout: assembly
title: PCB Assembly Sources
---

### Assembly Files

The assembly files are generated from the [schematics and board layout source
files](/electrical/sources/index.html) which were created in CADsoft EAGLE.

The files are all [stored in a Git repository at
GitHub](https://github.com/openxc/reference-vi/tree/gh-pages/assembly/electrical).

* [Board Layout DXF](/assembly/electrical/vehicle-interface.dxf)
* [Gerber files](https://github.com/openxc/reference-vi/raw/gh-pages/assembly/electrical)
    * .top  Top Copper Layer
    * .smt  Top Soldermask
    * .slk  Top Silkscreen
    * .tsp  Top Solderpaste
    * .bot  Bottom Copper Layer
    * .smb  Bottom Soldermask
    * .bsk  Bottom Silkscreen
    * .bsp  Bottom Solderpaste
    * .oln PCB Outline
    * .drd  Excellon Drill Data
    * .drl  Basic Drill tool information
    * .dri  Extended Drill tool information

### Special Assembly Instructions

* See NOTES: on ASSY drawings for general notes
* Ensure no excess solder is wicked into J0 (USB Micro Connector).  Verify a USB
  Micro cable can successfully connect
* Ensure J0 (USB Micro Connector) is completely flush to the PCB before/after
  reflow.  Ensure pins at rear of connector are not lifted off pads.
* Apply epoxy to J0 for additional structural rigidity
* Ensure J2 (OBD-II connector) pins are flush with PCB before soldering
* Ensure J2 (OBD-II connector) is horizontal to PCB before soldering
* LED1 and LED4 (through hole RGB LEDs) must be bent 90 degrees towards front
  edge of PCB
* Ensure both through hole electrolytic capacitors (C2 and C3) are flush against
  PCB before soldering.
* Ensure part Q2 (12MHz crystal) is oriented such that the long dimension
  follows the centerline on the silkscreen layer.

### Assembly file output instructions

If you modify the schematics and need to regenerate the assembly files, follow
these instructions.

* Verify silkscreen and PCB Frame artwork reflects accurate revision
* Update layers 125 and 126 - text on top of each component should identify the
  part designator
* Delete all content on layer (144) DrillLegend
* run "drillegend.ulp": Use all default values, click OK.
* Reselect layer (144) and move the newly created drill legend back onto the
  frame
* Verify SSC-EAGLE-2Lyr_v1.0.0.3.dru is loaded as current design rules file
* Turn on all copper and stopmask layers, turn off silkscreen layers (skip
  silkscreen error checking, silkscreen will be clipped by assembly house)
* Preform DRC/ERC check
* run "drillcfg.ulp": select "Inch" as output format.  Click OK.  Save.
* run "excellon.cam" in the CAM processor, click "Process Job"
* run "2LPlus-Sunstone.cam" in the CAM processor, click "Process Job"
* Double check all gerber files using a gerber file viewer (like gerbv).
* Deselect all layers, select only the following layers: (17)Pads, (18)Vias,
  (20)Dimension, (21)tPlace, (22)bPlace, (23)tOrigins, (24)bOrigins,
  (49)Reference, (51)tDocu, (52)bDocu, (125)tAssy, (126)bAssy
* run "dxf.ulp": deselect "Fill Areas", make sure "mm" is selected under the
  "units" header.  Save the DXF file.
* Deselect all layers, select only the following layers: (17)Pads, (18)Vias,
  (20)Dimension, (21)tPlace, (23)tOrigins, (48)Document, (49)Reference,
  (51)tDocu, (125)tAssy, (144)DrillLegend
* Hit print (Ctrl+P), select "Print to File (PDF)" as the printer, select
  vehicle-interface_ASSY_TOP.pdf, paper size A4, scale factor 1.  Click OK.
* Deselect all layers, select only the following layers: (17)Pads, (18)Vias,
  (20)Dimension, (22)bPlace, (24)bOrigins, (48)Document, (49)Reference,
  (52)bDocu, (126)bAssy, (144)DrillLegend
* Hit print (Ctrl+P), select "Print to File (PDF)" as the printer, select
  vehicle-interface_ASSY_BOT.pdf, paper size A4, scale factor 1.  Click OK.
* Deselect all layers, select only the following layers: (1)Top, (16)Bottom,
  (17)Pads, (18)Vias, (20)Dimension, (21)tPlace, (22)bPlace, (25)tNames,
  (51)tDocu, (52)bDocu
* Zoom in so that PCB is centered in the screen and fills the window as much as
  possible.
* Select File->Export->Image.  Select vehicle-interface.brd.png.  Set
  "Resolution" to 600.  Set "Area" to "Window".
* In the schematic window, hit print (Ctrl+P), select "Print to File (PDF)" as
  the printer, select vehicle-interface.sch.pdf, paper size A4, scale factor 1,
  page limit 1  Click OK.
* In the schematic window, select File->Export->Partlist.  Select
  "vehicle-interface.parts.txt".  Click OK.
* Manually compare "vehicle-interface.parts.txt" to "vehicle-interface.bom.xls".
  Make sure the two lists are consistent.
* Open "CHANGELOG.xls".  Update the file to reflect the new revision.
* Create a zip archive with the following files (at least):
    * vehicle-interface.pdf
    * vehicle-interface.brd.png
    * vehicle-interface_ASSY_TOP.pdf
    * vehicle-interface_ASSY_BOT.pdf
    * vehicle-interface.tsp
    * vehicle-interface.top
    * vehicle-interface.smt
    * vehicle-interface.smb
    * vehicle-interface.slk
    * vehicle-interface.oln
    * vehicle-interface.gpi
    * vehicle-interface.dxf
    * vehicle-interface.drl
    * vehicle-interface.dri
    * vehicle-interface.drd
    * vehicle-interface.bsp
    * vehicle-interface.bsk
    * vehicle-interface.bot
    * vehicle-interface.bom.xls
    * vehicle-interface.sch
    * vehicle-interface.brd
    * CHANGELOG.xls

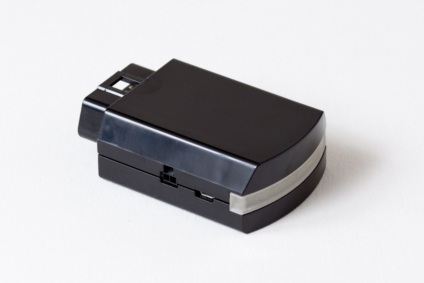
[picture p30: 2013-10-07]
static/images/vi-assembled.jpg

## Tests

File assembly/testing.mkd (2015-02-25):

---
layout: assembly
title: Testing Plan
---

A test jig can be created using [Spring Pogo
Pins](https://www.adafruit.com/products/394).  At a minimum, the test jig should
contain pogo pins and mounting holes at the PCB locations outlined by [this
spreadsheet](/assembly/pogo_location.xls).  A rooted linux host is
necessary for this test - perhaps an embedded android device like a raspberyPi,
Beagleboard or pcDuino.

1. Connect OBD cable, JTAG and Micro USB cables to the board under test
1. Apply 12V power to board
1. Measure all power rails, verify they are within 0.1V of target
1. Remove +12V power, attach +5V supply to the Micro USB port
1. Re-verify power rails are within range
1. Re-apply 12V power to board
1. Deploy test firmware to board, examine OpenOCD output for errors
1. Take snapshot of logic levels and compare to expected values: BT_RTS,
 BT_CTS, BT_RESET, BT_CONN, DOCK_PWR_EN, DOCK_PWR_OUT, USB_CON, ISP_EN,
 USBBOOT_EN, DEBUG_TX, DEBUG_RX, RESET, DOCK_PWR_FLT, DOCK_PWR_PG
1. Boot into ISP bootloader (Pull ISP_EN low, Toggle RESET, Release ISP_EN) and
 retrieve LPC1769 serial number
1. (ensure that test firmware configures the baud rate of the RN-41 device, see
 [RN-41 configuration](/firmware/rn41.html))
1. Execute short bluetooth bandwidth test (data-test.py --bandwidth --size 5000
 --plot).  Capture results.  Take snapshot of BT_RTS, BT_CTS, BT_RESET,
 BT_CONN lines upon error
1. Execute short USB bandwidth test (data-test.py --usb --bandwidth --size
 50000 --plot).  Capture results.  Take snapshot of USB_CON, +5V upon error
1.  Execute short CAN bandwdith test (cantx.py --plot).  Capture results.  Take
 snapshot CANA_HI, CANA_LO, CANB_HI, CANB_LO upon error.
1. Assert Dock power output.  Measure voltage at connector output, verify it is
 within 0.5V of target.
1. De-assert Dock power output, re-measure, verify connector output is 1V or
 below.
1. Deploy [Emulator Firmware](https://github.com/openxc/vi-firmware/releases) from the openxc-vi-firmware package and connect to the OpenXC VI with an test Android device. 
2. Use the OpenXC Enabler App on the Android device to verify emulated data is being streamed to Android from the OpenXC VI.
1. Deploy production firmware to board
1. Connect to USB, verify production firmware is successfully running

## Validation Criteria

**Bluetooth**

1. Maintain a baud rate of at least 115200 for a sustained 5MB transfer over
   Bluetooth with no transmission errors
1. Push varying amounts of data for 12 hours and record all disconnections and
   transmissions errors
1. Run through 100 connect/disconnect cycles, looking for failures to connect,
   or any instance in which the Bluetooth stack on the CAN Translator becomes
   out of sync.

**USB**

1. Maintain a transfer rate of at least 100KB/s for a sustained 5MB transfer
   over USB with no transmission errors
1. Push varying amounts of data for 12 hours and record all disconnections and
   transmissions errors
1. Verify the CAN translator can be powered via USB when not connected to an
   OBD-II port
1. Verify that the CAN translator can be powered by the vehicle through the
   OBD-II port and also be plugged into an Android device via USB while not
   having conflicting current.

**CAN**

1. Verify that CAN messages can be received from a vehicle or test harness,
   and that the stream can be maintained for 1 hour without interruption.
1. Verify that a stream of CAN messages can be written out to the CAN bus for
   1 hour

**Power**

1. Test that MCU can be put to sleep and power draw goes very low
1. Test that MCU can wakeup on a CAN interrupt and get back to full power,
   record time to wakeup (time to wakeup is on the order of microseconds)
1. External power socket should provide steady 12v
1. External power socket should not provide any power when the MCU goes into
   sleep mode

**Lighting**

1. RGB LEDs must be controllable from software

**Pysical**

1. OBD-II connector can be attached to a vehicle with a reasonable amount of
   force
1. OBD-II connector is robustly connected to the port
1. OBD-II connector takes a reasonable amount of effort to detach from the
   vehicle, but the process does not overly strain the housing or PCB
1. The 12v power cable can be attached and detached with a reasonable amount
   of force, and resists being knocked out of the socket by accident

**Mechanical Design**

1. Designed for injection molding --> Constant wall thickness, appropriate
  minimum thickness material (0.050" for ABS), draft angles, slide
  consideration
1. Robust attachment and mating features between housing pieces
1. Appropriate fit in specified vehicles (Focus, Flex, F-150, Explorer)

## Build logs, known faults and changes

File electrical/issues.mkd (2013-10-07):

---
layout: electrical
title: Known Issues
---

The version of the reference VI currently being shipped by Ford (in limited
quantity) has v0.3 of the PCB, and there are no known electrical issues.

For greater detail, see the [changelog in the source
files (.xls)](/electrical/CHANGELOG.xls).

#### v0.3

* No known electrical issues.

#### v0.2

This was the first test run of the schematic.

* Output Power Jack Polarity is incorrect - The output power jack should be
  configured such that Pin 1 (the keyed pin) is Ground, and Pin 2 is +12V. This
  is flipped on the R0.2 PCB. A custom cable was created to patch this issue,
  and is labeled `R0.2 Only`. Only use this cable with R0.2 prototypes,
  otherwise the KBoard TVS Diode D2 and/or the VI power switch IC7
  may be damaged or destroyed.
* JTAG CLK line - the JTAG signal RTCK was disconnected on R0.2 boards. It has
  manually been replaced with a wire. Occasionally the additional capacitance of
  this wire can cause JTAG errors - try reducing the JTAG clock rate.
* JTAG Ground noise - Occasionally JTAG errors can be caused by a ground loop
  between a USB JTAG adapter and the MicroUSB port on the VI. Try
  removing one or more connections to ground: IE, try powering the prototype
  from ONLY +5V USB verses the +12V OBD-II supply.
* Bluetooth connection dropout - Under some circumstances, the RN-41 bluetooth
  chipset will lock up and drop an active bluetooth connetion when under heavy
  load:
    * The most common cause of this problem is software flow control: make sure
      to use the RTS and CTS pins for UART1.
    * The RN-41 configuration timer can also cause the RN-41 input buffer to
      fill. From the LPC1769, enter configuration mode by transmitting
      ```$$$```, disable the configuration timer with ```ST,0\r\n``` and then
      exit configuration mode by entering ```---\r\n```. Finally, power cycle
      the VI. The test firmware `rn42-passthrough` enables serial
      data to be relayed between UART0 (the 6-pin ISP header) and UART1 (the
      bluetooth interface).

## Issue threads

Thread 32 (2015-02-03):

electrical BOM link doesn't work

tangchihwei, 2015-02-03:

Closed 2015-02-03.

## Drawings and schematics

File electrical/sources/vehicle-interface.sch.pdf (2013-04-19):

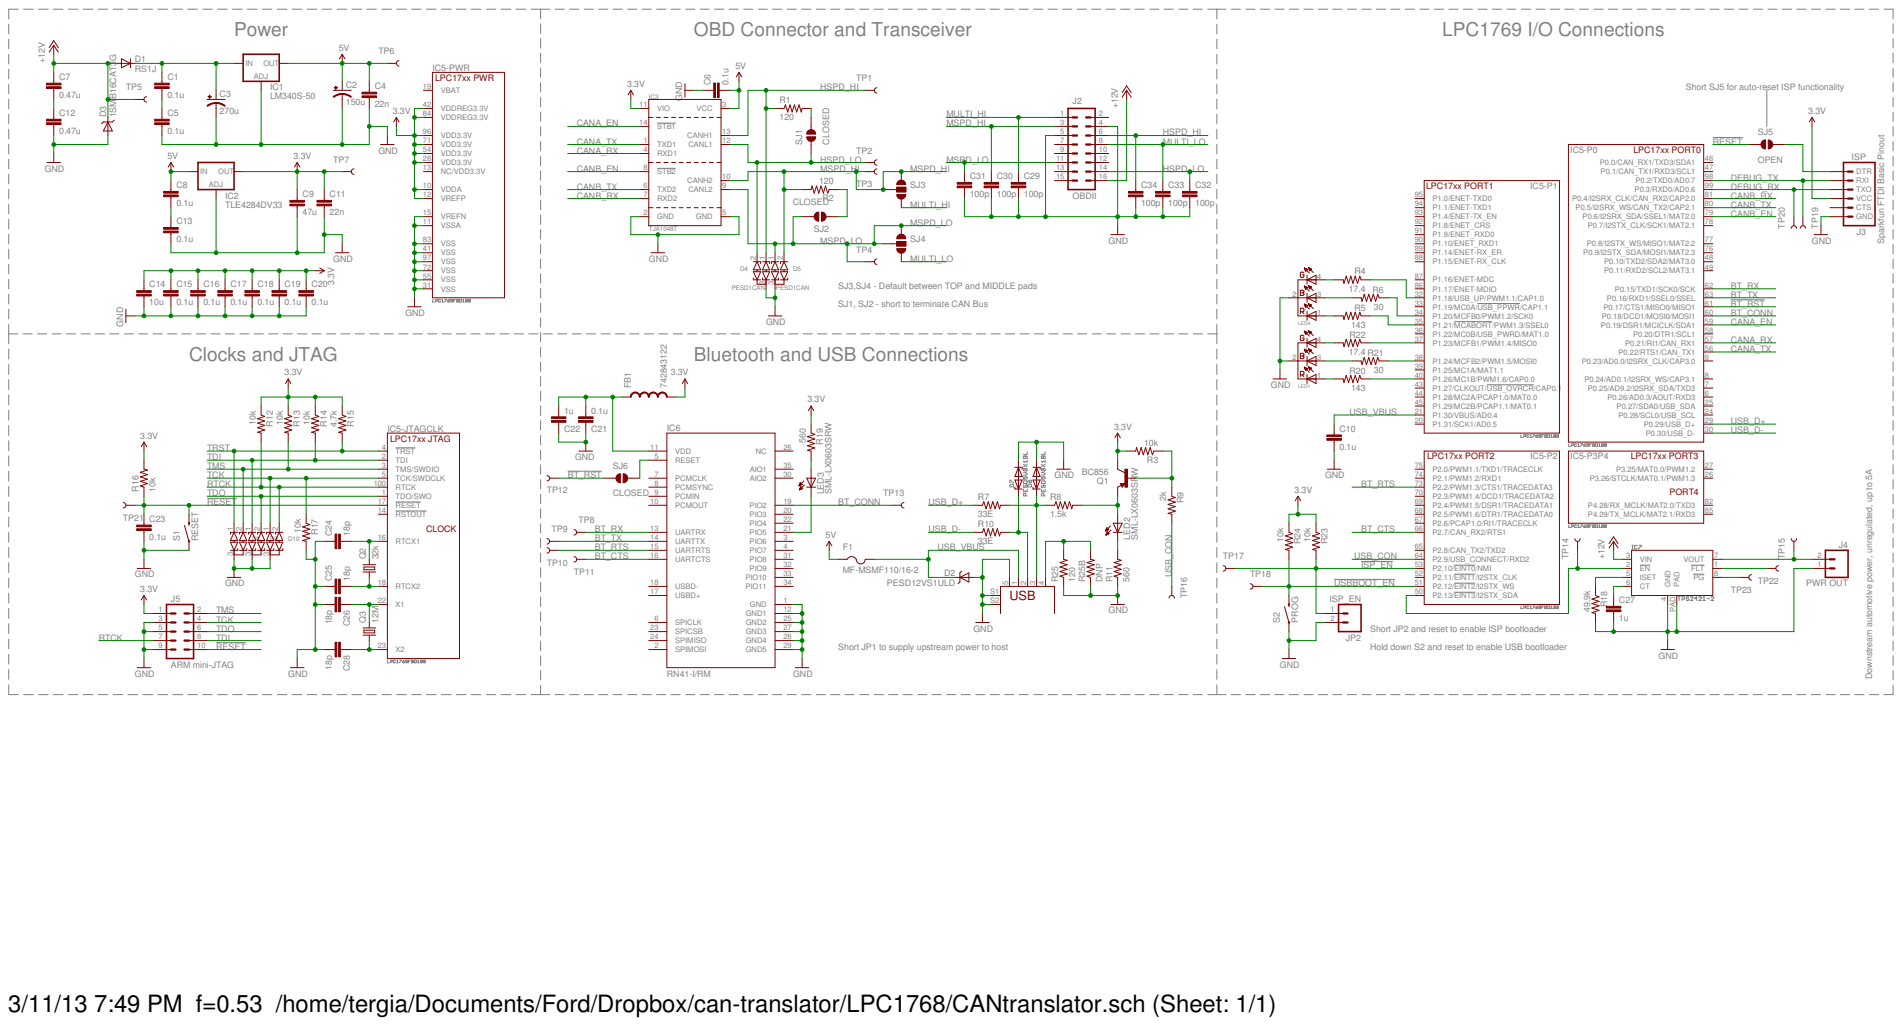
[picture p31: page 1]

Short SJ5 for auto-reset ISP functionality

SJ1, SJ2 - short to terminate CAN Bus

Short JP2 and reset to enable ISP bootloader Hold down S2 and reset to enable USB bootloader

Short JP1 to supply upstream power to host

3/11/13 7:49 PM f=0.53 /home/tergia/Documents/Ford/Dropbox/can-translator/LPC1768/CANtranslator.sch (Sheet: 1/1)

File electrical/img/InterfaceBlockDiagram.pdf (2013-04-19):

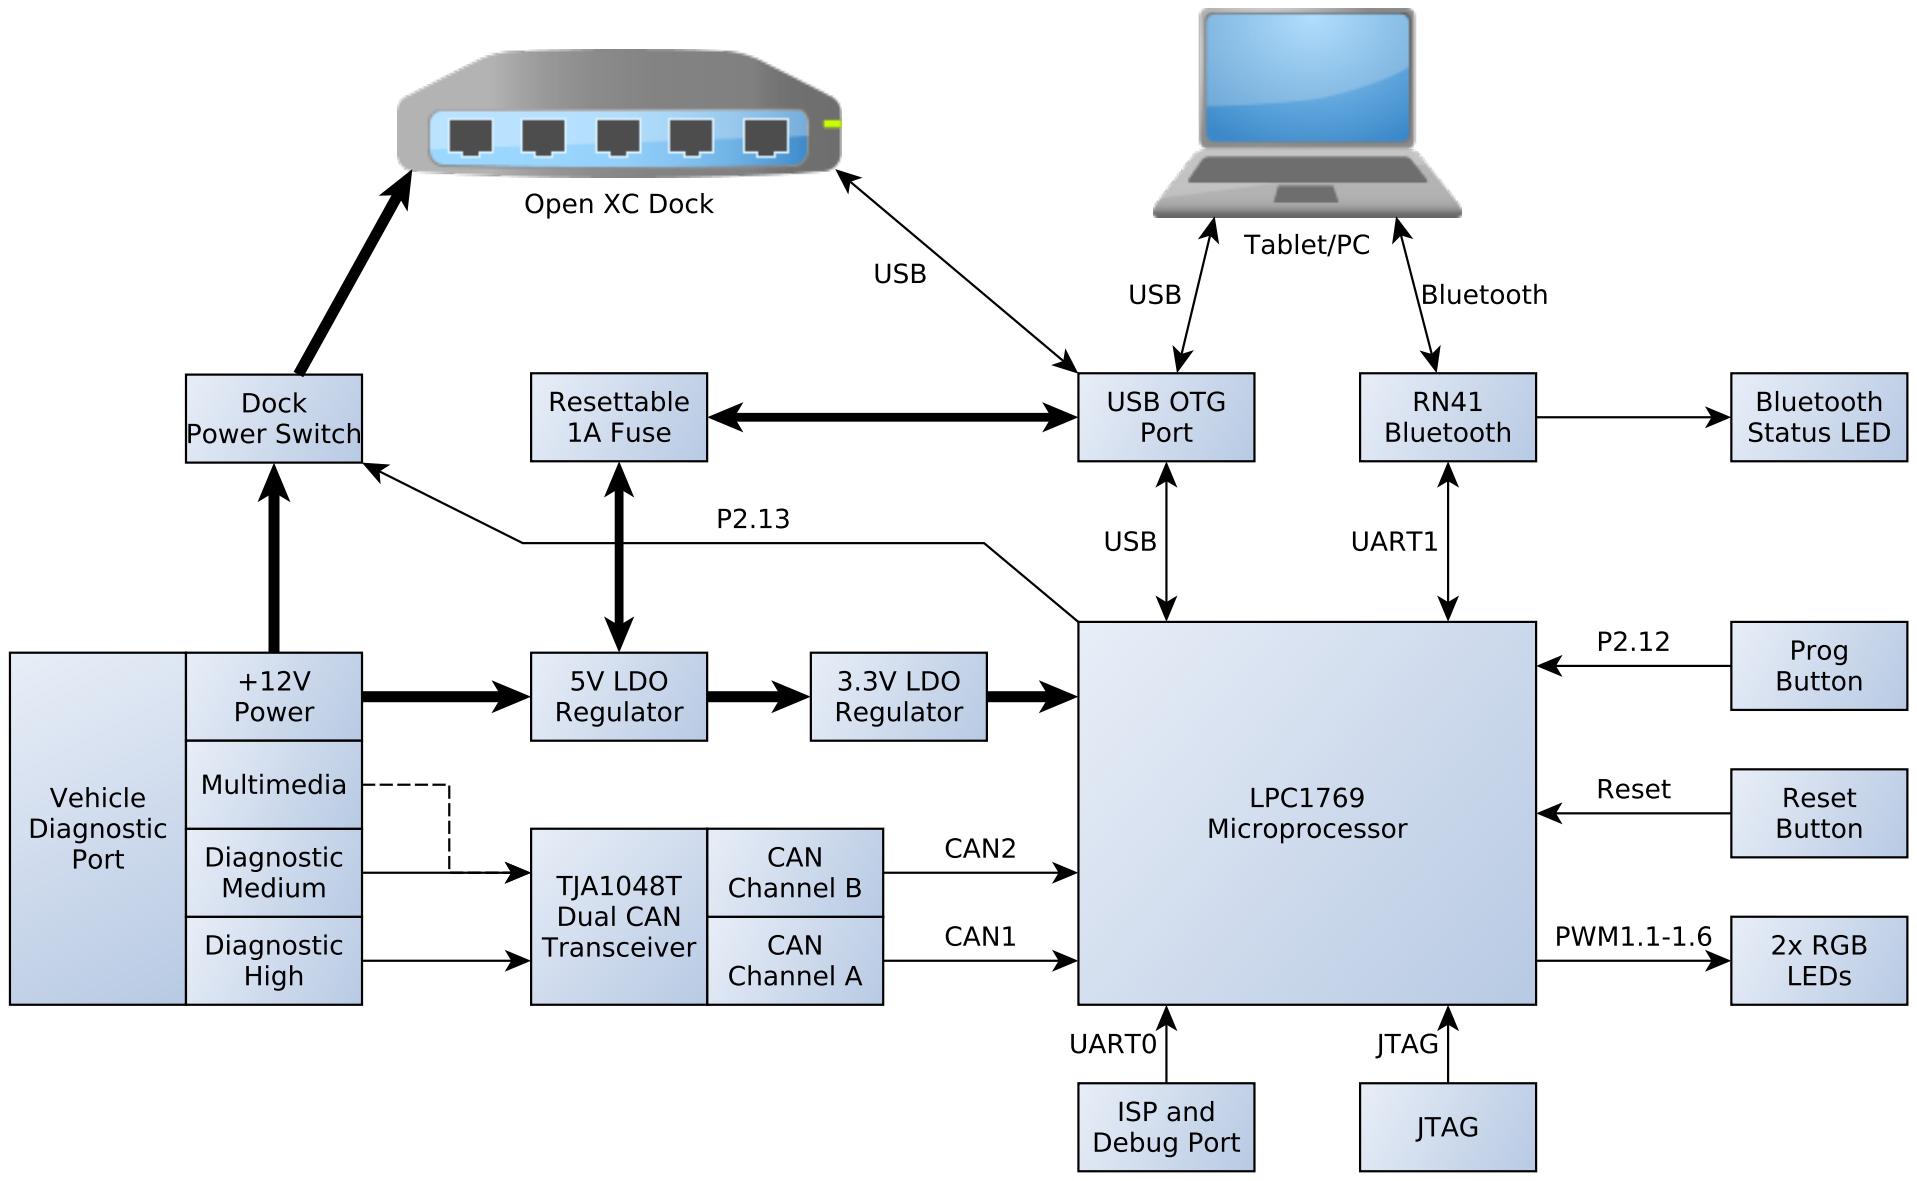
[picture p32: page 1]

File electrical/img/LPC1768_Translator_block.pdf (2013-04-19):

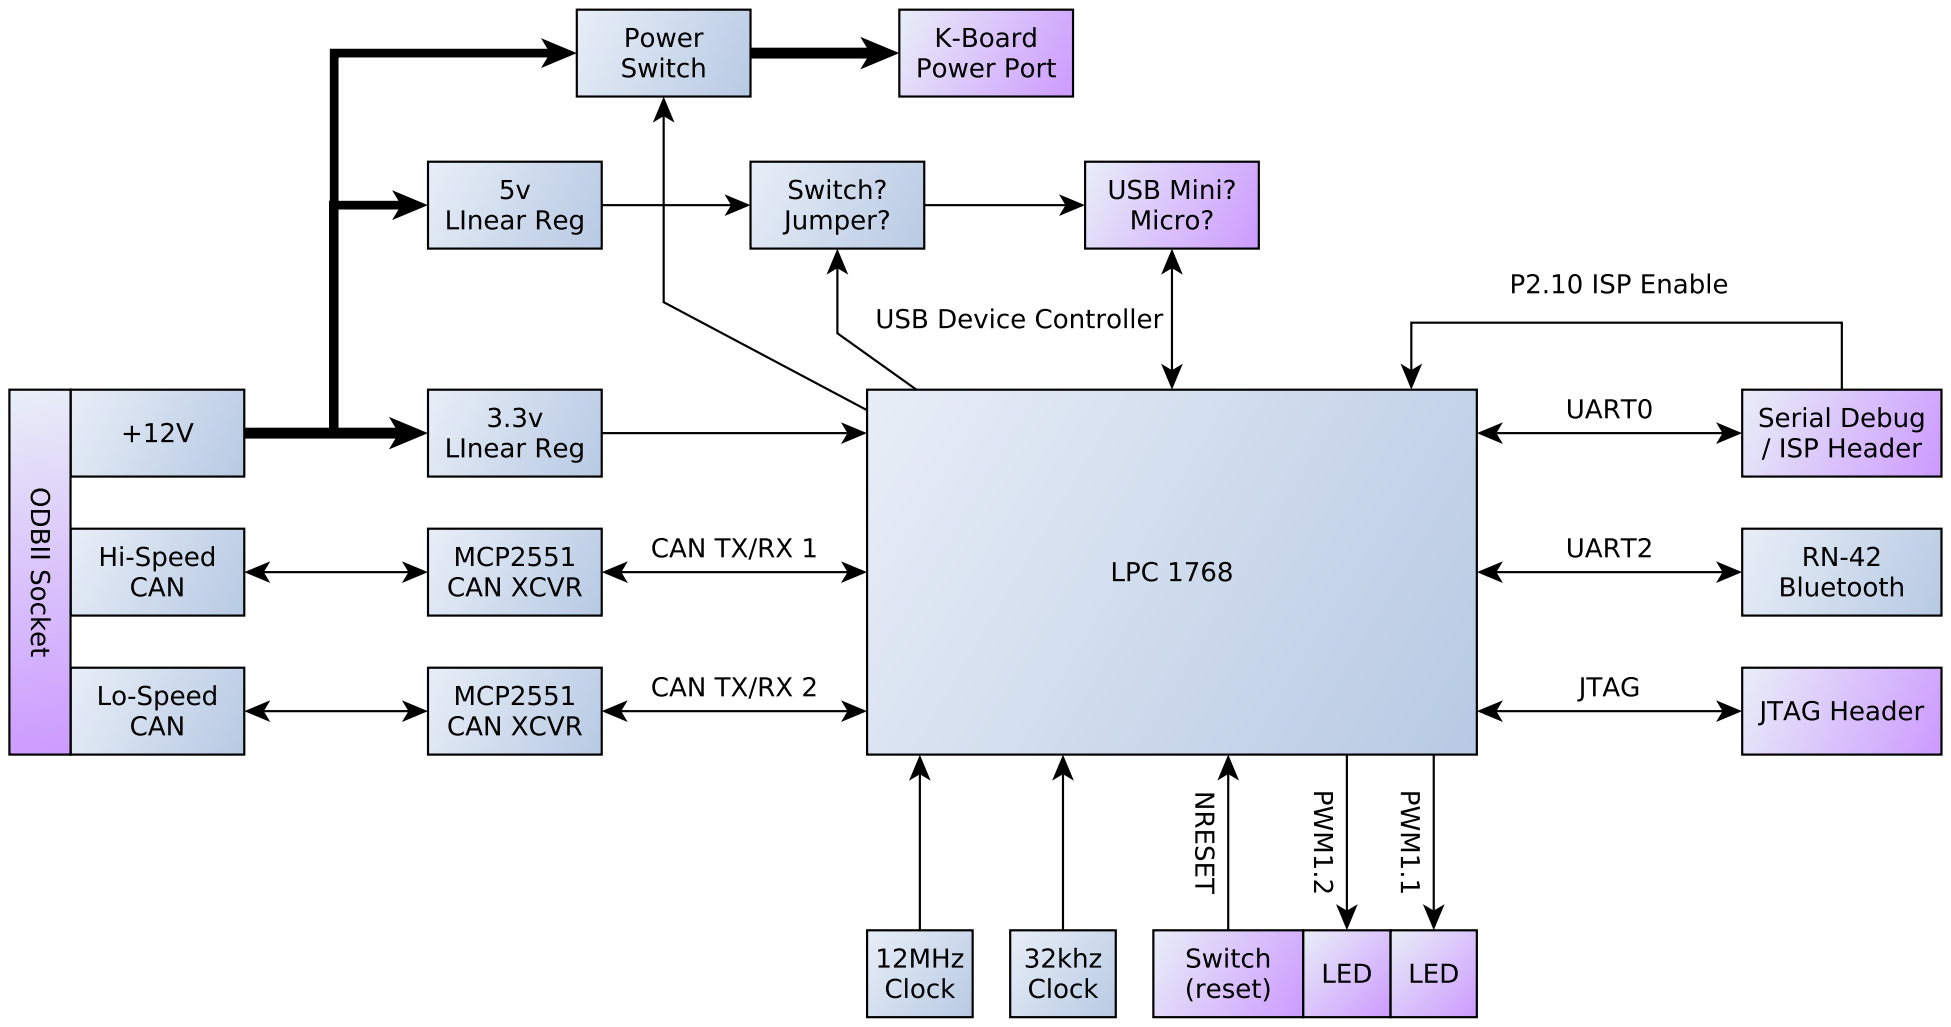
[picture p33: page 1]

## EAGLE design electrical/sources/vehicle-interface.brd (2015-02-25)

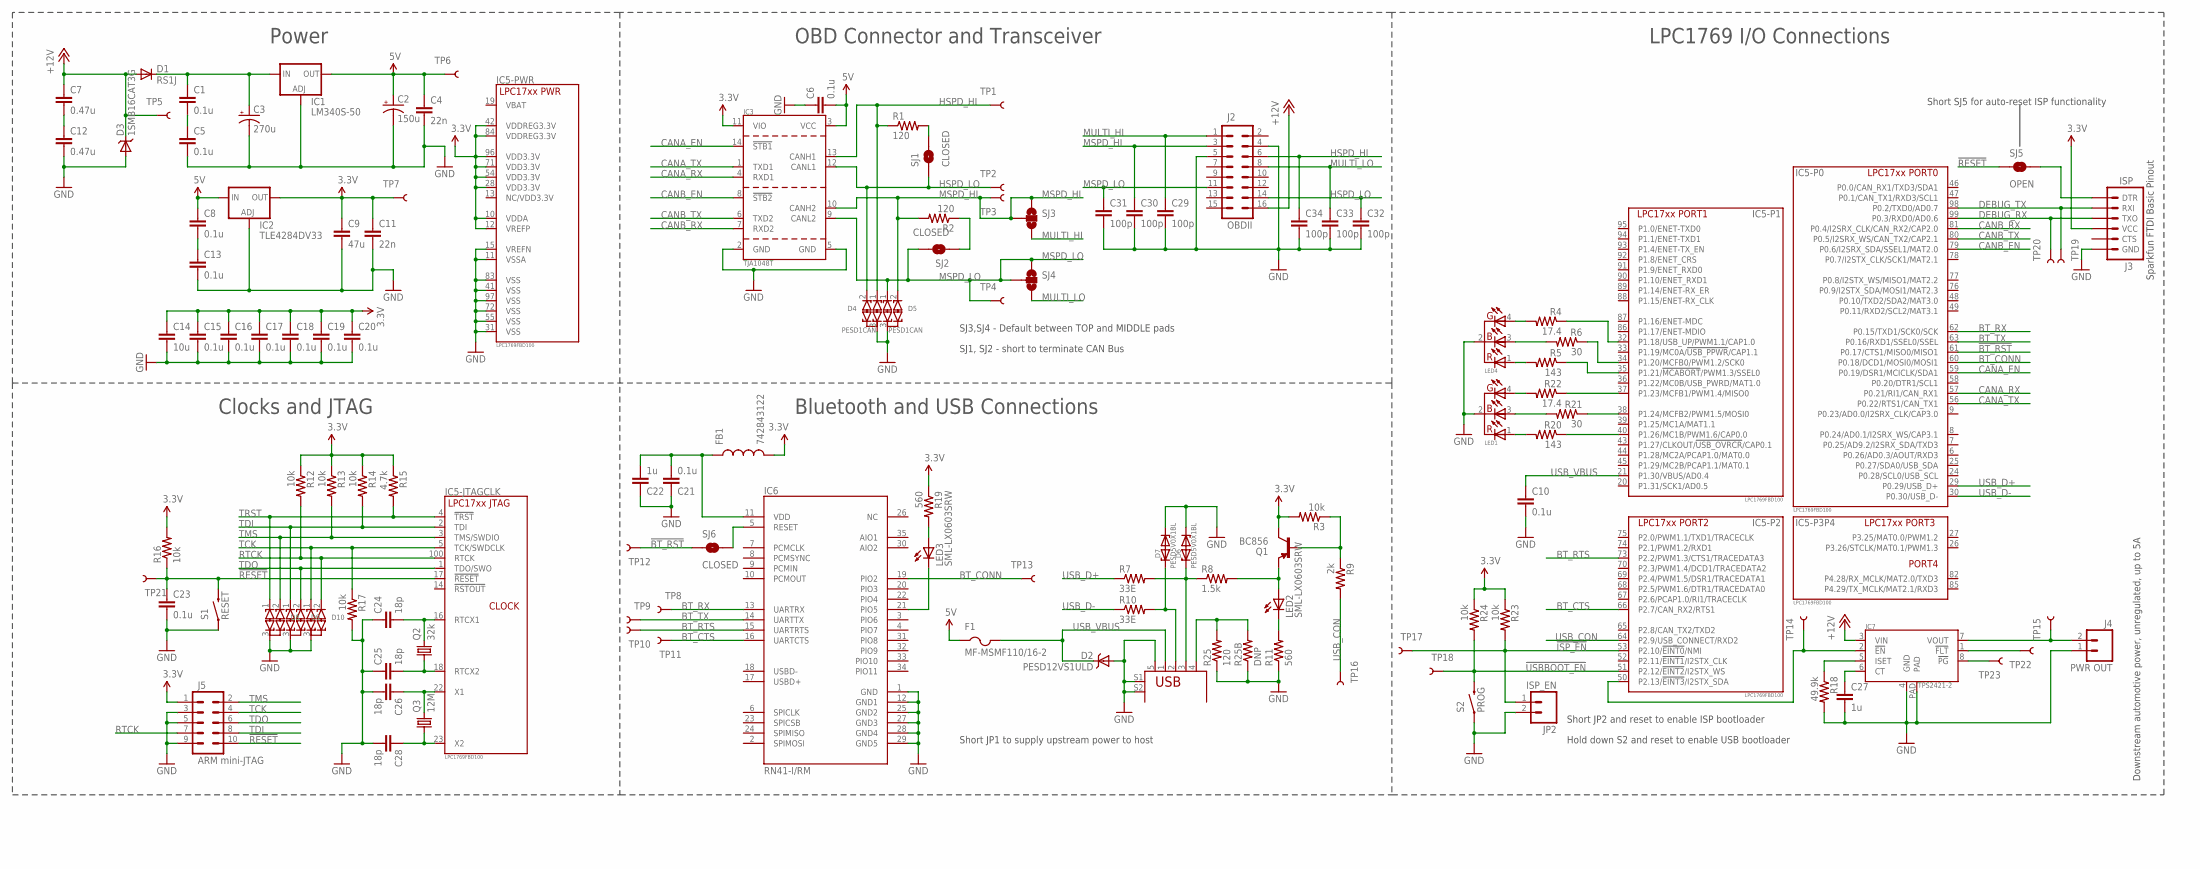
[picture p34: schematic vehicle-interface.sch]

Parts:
C1, C5, C8, C13: 0.1u; 0805
C2: 150u; CPOL-5MMX2D
C3: 270u; CPOL-10MMX5D
C4, C11: 22n; 0402-CAP
C6, C10, C15, C16, C17, C18, C19, C20, C21, C23: 0.1u; 0402-CAP
C7, C12: 0.47u; 0805
C9: 47u; 1210
C14: 10u; 0805
C22, C27: 1u; 0402-CAP
C24, C25, C26, C28: 18p; 0402-CAP
C29, C30, C31, C32, C33, C34: 100p; 0402-CAP
D1: RS1J; SMA-DIODE
D2: PESD12VS1ULD; SOD-882D
D3: 1SMB16CAT3G; SMB-DIODE
D4, D5: PESD1CAN; SOT23
D6, D7: PESD5V0X1BL; SOD-882
D8, D9, D10: DIODE_ESD_DUAL-SOT-1123; SOT-1123
F1: MF-MSMF110/16-2; R1206
FB1: 742843122; C0402
IC1: LM340S-50; V-REG_DPACK
IC2: TLE4284DV33; V-REG_DPACK
IC3: TJA1048T; SO14
IC5: LPC1769FBD100; TQFP100
IC6: RN41-I/RM; RN41
IC7: TPS2421-2; POWER_SO8
J1: USB_MINIB_SHIELD-10118193; 10118193
J2: OBDII; OBDII-COMTECH
J3: ISP; 1X06
J4: PWR OUT; 2-1445055-2
J5: ARM mini-JTAG; SHF-105-01-X-D-SM
JP2: ISP_EN; 1X02
LED1, LED4: RGB; LED5MM-RGB
LED2, LED3: SML-LX0603SRW; LED-0603
Q1: BC856; SOT23-3
Q2: 32k; ST2012SB
Q3: 12M; CX3225SB
R1, R2, R25: 120; 0402-RES
R3, R12, R13, R14, R16, R17, R23, R24: 10k; 0402-RES
R4, R22: 17.4; 0402-RES
R5, R20: 143; 0402-RES
R6, R21: 30; 0402-RES
R7, R10: 33E; 0402-RES
R8: 1.5k; 0402-RES
R9: 2k; 0402-RES
R11, R19: 560; 0402-RES
R15: 4.7k; 0402-RES
R18: 49.9k; 0402-RES
R25B: DNP; AXIAL-0.4
S1: RESET; TACTILE-SWITCH-1101NE
S2: PROG; TACTILE-SWITCH-1101NE
SJ1, SJ2, SJ6: CLOSED; SJ_2S-TRACE
SJ3, SJ4: SOLDERJUMPER_2WAYPASTE1&2; SJ_3_PASTE1&2
SJ5: OPEN; SJ_2S-NO
TP1, TP2, TP3, TP4, TP5, TP6, TP7, TP8, TP9, TP10, TP11, TP12, TP13, TP14, TP15, TP16, TP17, TP18, TP19, TP20, TP21, TP22, TP23: TEST-POINT3X5; PAD.03X.05

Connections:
3.3V: C9.1, C11.1, C14.1, C15.1, C16.1, C17.1, C18.1, C19.1, C20.1, FB1.2, IC2.4 (OUT), IC3.11 (VIO), IC5.10 (VDDA), IC5.12 (VREFP), IC5.28 (VDD3.3V), IC5.42 (VDDREG3.3V), IC5.54 (VDD3.3V), IC5.71 (VDD3.3V), IC5.84 (VDDREG3.3V), IC5.96 (VDD3.3V), J3.4 (VCC), J5.1, Q1.3 (C), R3.2, R12.1, R13.1, R14.1, R15.1, R16.2, R19.1, R23.1, R24.1, TP7.P$1
5V: C2.1 (+), C4.1, C6.2, C8.1, F1.1, IC1.4 (OUT), IC2.3 (IN), IC3.3 (VCC), TP6.P$1
!BT_RST: IC5.61 (P0.17/CTS1/MISO0/MISO1), SJ6.1, TP12.P$1
!ISP_EN: IC5.53 (P2.10/!EINT0!/NMI), JP2.1, R23.2, TP17.P$1
!RESET: C23.1, IC5.17 (!RESET), J5.10, R16.1, S1.P$2 (2), SJ5.1, TP21.P$1
!USBBOOT_EN: IC5.51 (P2.12/!EINT2!/I2STX_WS), R24.2, S2.P$2 (2), TP18.P$1
+12V: C7.1, D1.A, D3.C, IC7.3 (VIN), J2.16, TP5.P$1
BT_CONN: IC5.60 (P0.18/DCD1/MOSI0/MOSI1), IC6.19 (PIO2), TP13.P$1
BT_CTS: IC5.66 (P2.7/CAN_RX2/RTS1), IC6.16 (UARTCTS), TP11.P$1
BT_RTS: IC5.73 (P2.2/PWM1.3/CTS1/TRACEDATA3), IC6.15 (UARTRTS), TP10.P$1
BT_RX: IC5.62 (P0.15/TXD1/SCK0/SCK), IC6.13 (UARTRX), TP8.P$1
BT_TX: IC5.63 (P0.16/RXD1/SSEL0/SSEL), IC6.14 (UARTTX), TP9.P$1
CANA_EN: IC3.14 (!STB1), IC5.59 (P0.19/DSR1/MCICLK/SDA1)
CANA_RX: IC3.4 (RXD1), IC5.57 (P0.21/RI1/CAN_RX1)
CANA_TX: IC3.1 (TXD1), IC5.56 (P0.22/RTS1/CAN_TX1)
CANB_EN: IC3.8 (!STB2), IC5.79 (P0.6/I2SRX_SDA/SSEL1/MAT2.0)
CANB_RX: IC3.7 (RXD2), IC5.81 (P0.4/I2SRX_CLK/CAN_RX2/CAP2.0)
CANB_TX: IC3.6 (TXD2), IC5.80 (P0.5/I2SRX_WS/CAN_TX2/CAP2.1)
DEBUG_RX: IC5.99 (P0.3/RXD0/AD0.6), J3.3 (TXO), TP20.P$1
DEBUG_TX: IC5.98 (P0.2/TXD0/AD0.7), J3.2 (RXI), TP19.P$1
GND: C2.2 (-), C3.1 (-), C4.2, C5.2, C6.1, C9.2, C10.2, C11.2, C12.2, C13.2, C14.2, C15.2, C16.2, C17.2, C18.2, C19.2, C20.2, C21.1, C22.1, C23.2, C24.1, C25.1, C26.2, C27.2, C28.2, C29.2, C30.2, C31.2, C32.2, C33.2, C34.2, D2.2 (A), D3.A, D4.3 (COM), D5.3 (COM), D6.1, D7.1, D8.3 (COM), D9.3 (COM), D10.3 (COM), IC1.1 (ADJ), IC2.1 (ADJ), IC3.2 (GND), IC3.5 (GND), IC5.11 (VSSA), IC5.15 (VREFN), IC5.31 (VSS), IC5.41 (VSS), IC5.55 (VSS), IC5.72 (VSS), IC5.83 (VSS), IC5.97 (VSS), IC6.1 (GND), IC6.12 (GND1), IC6.25 (GND2), IC6.27 (GND3), IC6.28 (GND4), IC6.29 (GND5), IC7.4 (GND), IC7.PAD, J1.5 (GND), J1.S1, J1.S2, J2.4, J2.5, J3.6 (GND), J4.1, J5.3, J5.5, J5.9, JP2.2, LED1.2 (C), LED4.2 (C), R11.1, R17.2, R18.2, R25.1, R25B.P$1 (1), S1.P$1 (1), S2.P$1 (1)
HSPD_HI: C34.1, D4.1 (C1), IC3.13 (CANH1), J2.6, R1.1, TP1.P$1
HSPD_LO: C32.1, D4.2 (C2), IC3.12 (CANL1), J2.14, SJ1.1, TP2.P$1
MSPD_HI: C30.1, D5.2 (C2), IC3.10 (CANH2), J2.3, R2.2, SJ3.1, SJ3.2, TP3.P$1
MSPD_LO: C31.1, D5.1 (C1), IC3.9 (CANL2), J2.11, SJ2.2, SJ4.1, SJ4.2, TP4.P$1
MULTI_HI: C29.1, J2.1, SJ3.3
MULTI_LO: C33.1, J2.8, SJ4.3
unnamed: R1.2, SJ1.2
unnamed: IC5.40 (P1.26/MC1B/PWM1.6/CAP0.0), R20.1
unnamed: R2.1, SJ2.1
unnamed: IC5.50 (P2.13/!EINT3!/I2STX_SDA), IC7.2 (!EN), TP14.P$1
unnamed: LED1.4 (G), R22.2
unnamed: IC6.21 (PIO5), LED3.C
unnamed: C7.2, C12.1
unnamed: LED3.A, R19.2
unnamed: IC5.38 (P1.24/MCFB2/PWM1.5/MOSI0), R21.1
unnamed: IC5.37 (P1.23/MCFB1/PWM1.4/MISO0), R22.1
unnamed: LED1.3 (B), R21.2
unnamed: LED1.1 (R), R20.2
unnamed: IC7.5 (ISET), R18.1
unnamed: C27.1, IC7.6 (CT)
unnamed: LED4.4 (G), R4.2
unnamed: IC5.32 (P1.18/USB_UP/PWM1.1/CAP1.0), R4.1
unnamed: C25.2, IC5.18 (RTCX2), Q2.1
unnamed: C8.2, C13.1
unnamed: J1.4 (ID), R25.2, R25B.P$2 (2)
unnamed: D7.2, J1.2 (D-), R10.2
unnamed: C1.2, C5.1
unnamed: C1.1, C3.2 (+), D1.C, IC1.3 (IN)
unnamed: C24.2, IC5.16 (RTCX1), Q2.2
unnamed: D6.2, J1.3 (D+), R7.2, R8.1
unnamed: C26.1, IC5.22 (X1), Q3.3 (2)
unnamed: C28.1, IC5.23 (X2), Q3.1
unnamed: LED2.A, Q1.2 (E), R8.2
unnamed: LED2.C, R11.2
unnamed: Q1.1 (B), R3.1, R9.1
unnamed: LED4.3 (B), R6.2
unnamed: LED4.1 (R), R5.2
unnamed: IC5.34 (P1.20/MCFB0/PWM1.2/SCK0), R6.1
unnamed: IC5.35 (P1.21/!MCABORT!/PWM1.3/SSEL0), R5.1
unnamed: IC7.1 (!FLT), TP22.P$1
unnamed: IC7.8 (!PG), TP23.P$1
unnamed: J3.1 (DTR), SJ5.2
unnamed: IC6.5 (RESET), SJ6.2
unnamed: C21.2, C22.2, FB1.1, IC6.11 (VDD)
RTCK: D10.2 (C2), IC5.100 (RTCK), J5.7, R12.2
TCK: D10.1 (C1), IC5.5 (TCK/SWDCLK), J5.4, R17.1
TDI: D9.1 (C1), IC5.2 (TDI), J5.8, R14.2
TDO: D9.2 (C2), IC5.1 (TDO/SWO), J5.6
TMS: D8.2 (C2), IC5.3 (TMS/SWDIO), J5.2, R13.2
TRST: D8.1 (C1), IC5.4 (!TRST), R15.2
USB_CON: IC5.64 (P2.9/USB_CONNECT/RXD2), R9.2, TP16.P$1
USB_D+: IC5.29 (P0.29/USB_D+), R7.1
USB_D-: IC5.30 (P0.30/USB_D-), R10.1
USB_VBUS: C10.1, D2.1 (C), F1.2, IC5.21 (P1.30/VBUS/AD0.4), J1.1 (VBUS)
VOUT: IC7.7 (VOUT), J4.2, TP15.P$1

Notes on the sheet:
Clocks and JTAG
Bluetooth and USB Connections
OBD Connector and Transceiver
Power
LPC1769 I/O Connections
SJ3,SJ4 - Default between TOP and MIDDLE pads
Sparkfun FTDI Basic Pinout
Downstream automotive power, unregulated, up to 5A
Short SJ5 for auto-reset ISP functionality
Short JP2 and reset to enable ISP bootloader
Hold down S2 and reset to enable USB bootloader
SJ1, SJ2 - short to terminate CAN Bus
Short JP1 to supply upstream power to host

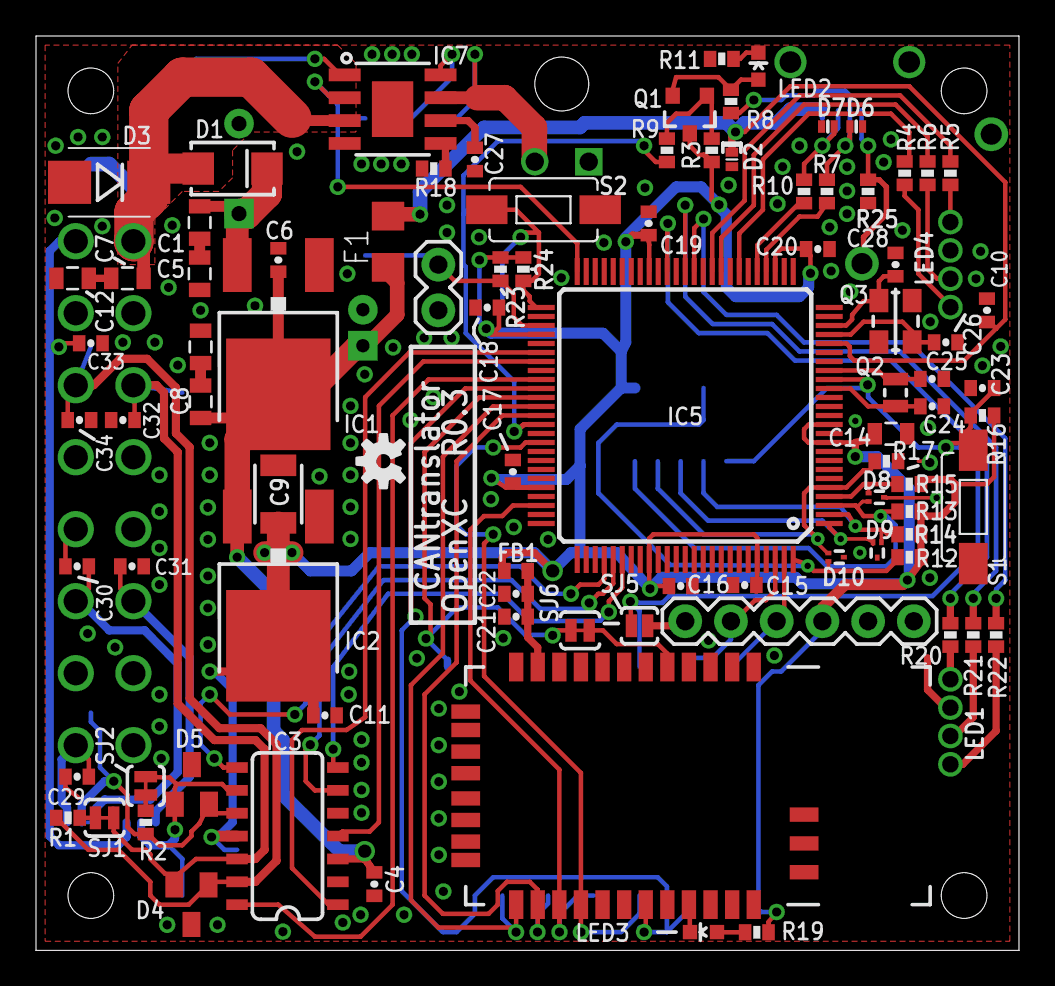
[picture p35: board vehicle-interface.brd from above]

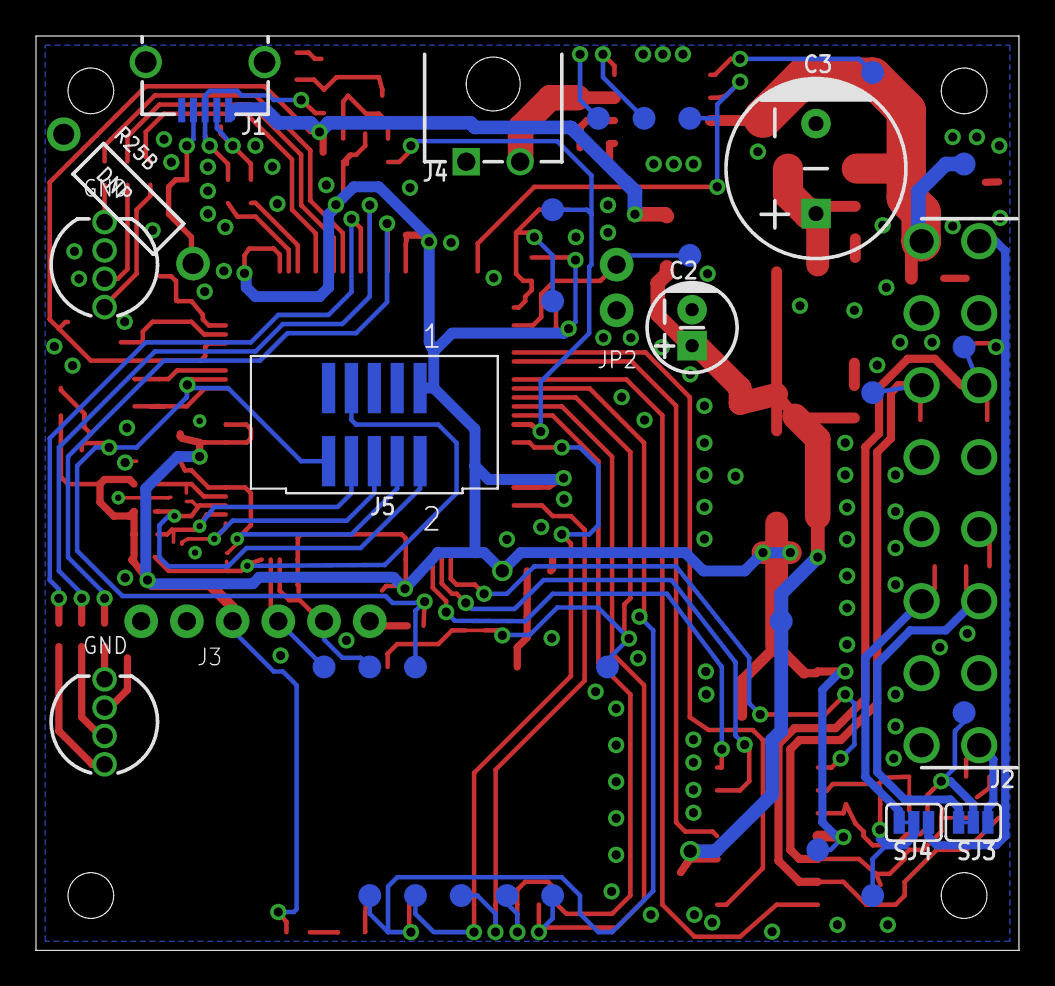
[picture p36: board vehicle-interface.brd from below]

Board: 2 copper layers, 54.6 x 50.8 mm, 125 parts (34 on the bottom side), 76 nets.

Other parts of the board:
DRILEGEND: DRILEGEND
F2: OSHW-LOGO-S
ZDRAW1: A4L-LOC

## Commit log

2013-04-19 Initial commit.
    [CAN_TRANS_assy_reva_asm.stp, CANtranslator.brd, CANtranslator.dxf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]
2013-05-28 Fix docs for when termination resistors should be used.
2013-05-28 Adding updating enclosure files
    [vi-bottom.stl, vi-diffuser.stl, vi-top.stl]
2013-08-27 Rename CAN translator -> vehicle interface.
    [pogo_location.xls, vehicle-interface.bom.xls, vehicle-interface.brd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]
2013-09-17 Re-organize the files a bit.
    [CHANGELOG.xls, DESIGN_CRITERIA.xls, vehicle-interface.bom.xls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]
2013-09-17 Move assembly docs to the new location.
2013-09-17 Oragnize remaining files from docs directory.
    [pogo_location.xls]
2013-09-18 Add design critera directly to HTML, not as an Excel file.
    [DESIGN_CRITERIA.xls, vehicle-interface.dxf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]
2013-09-18 Add notes from Zac on DFM for the housing.
2013-09-18 Add more notes on power supply schematic.
    [vehicle-interface.bom.xls, vehicle-interface.brd, vehicle-interface.sch]
2013-09-18 Add final production version of housing design.
    [vi-bottom.CATPart, vi-bottom.stl, vi-bottom.stp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]
2013-09-18 Add latest version of BOM.
    [vehicle-interface.bom.xls, vehicle-interface.bom.xlsx]
2013-09-18 Add notes from pitch document.
2013-09-19 Add preview images of board layout and schematic.
2013-09-20 Proofread a few sections and add new top/bottom PCB diagrams.
2013-09-20 Highlight Overview nav button when on index page.
2013-09-20 Add GitHub Fork button to top nav.
2013-09-23 Switch USB docs back to looking for 'LPC1759'
    The bootloader actually does say LPC1759 since it was originally designed for that, and I never did change that before the production run.
2013-09-24 Match CNAME to that in the prototype VI box literature.
2013-10-02 Note that termination resistor functionality is reversed.
2013-10-07 Mention that some vehicle may need an extension cable.
    Fixed #17.
2013-10-07 Mention version of shipping PCB.
    Fixed #20.
2013-10-07 Update all images to show shipping housing and PCB.
    I didn't change some of the heavily marked up images as the only change
    to the PCB is the OBD-II connector - we'll see if anyone notices.
    Fixed #22.
2013-11-01 Fix link to BOM.
2013-12-17 Add nav toggle button for narrow screens.
2014-09-04 update OBD-II connector info.
    [vehicle-interface.bom.xlsx]
2014-10-06 updated bom
    [vehicle-interface.bom.xlsx]
2014-12-22 updated engineering drawings and new BOM
    [vehicle-interface.bom-v3.xls, vehicle-interface.bom.xlsx]
2014-12-22 updated CAD files
    [VI_bottom_10-14-14.STEP, VI_diffuser_9-15-14.STEP, VI_top_9-15-14.STEP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]
2015-02-03 updated link for BOM
2015-02-03 updated mechanical section with 2D engineering drawing and step file
    [VI_bottom.STEP, VI_diffuser.STEP, VI_top.STEP]
2015-02-03 corrected typo in BOM link
2015-02-25 updated gerber files, updated silkscreen for JP2 and J3 and GND polarity for LED1 and LED4
    [vehicle-interface.brd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]
2015-10-15 remove original power schematic per request from Kevin & Karl.
2020-09-09 update host device link and remove submit link because it is not supported anymore.

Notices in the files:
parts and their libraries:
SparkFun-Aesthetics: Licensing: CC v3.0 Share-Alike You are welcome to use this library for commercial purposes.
